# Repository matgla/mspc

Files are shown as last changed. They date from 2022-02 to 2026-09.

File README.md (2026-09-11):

# MSPC

Hardware for MSPC: a small modular computer built from a mainboard and extension cards that plug
into the MSPC bus. The mainboard runs [yasos](https://github.com/matgla/yasos.zig).

## Versions and branches

| branch | contents |
|---|---|
| `main` | the current hardware: the v2 boards (same as `mspc_v2`) |
| `mspc_v1` | the first generation, kept for reference |
| `mspc_v2` | the v2 boards as built |
| `mspc_v2.5` | the next revision, work in progress; `main` moves there when it is done and that point is tagged `mspcv2.5` |

## Repository layout

Every board is a KiCad project with its fabrication outputs next to it in `outputs/`.

| directory | board |
|---|---|
| `mainboard/` | Mainboard (project in `mainboard/mainboard/`). RP2350B (80-QFN), QSPI flash and PSRAM, microSD, HS8836A USB hub, TLV320DAC3203 audio DAC, 12 V input with BD9D321EFJ bucks, three MSPC bus sockets (2×10 and 2×15, 1.27 mm). 4 copper layers. |
| `gpu_vga_extension/` | VGA card: RP2350A (60-QFN), 2× W25Q32JV flash, AP2112K 3.3 V regulator, resistor-ladder RGB DAC and DB15 connector. 24 × 50 mm, 4 layers. |
| `gpu_dvi_card/` | DVI card: same core as the VGA card, with an HDMI-type receptacle carrying DVI. 24 × 50 mm, 4 layers. |
| `fpga_extension/` | FPGA card (project in `fpga_extension/fpga_extension/`): Lattice ECP5 LFE5UM-85F, W958D8NBYA HyperRAM, QSPI configuration flash, microSD, and an on-board RP2040 USB-C JTAG programmer. 47.5 × 50 mm, 6 layers. |
| `bus_adapter_20pin/` | Passive breakout from the 2×10 1.27 mm bus socket to two 1×10 2.54 mm headers. |
| `bus_adapter_30pin/` | Passive breakout from the 2×15 1.27 mm bus socket to two 1×15 2.54 mm headers. |
| `simulation/` | 2022 SPICE sandbox: KiCad/ngspice schematics (audio filter, power switch) and PySpice scripts. Not a board. |

## Working with the files

- The projects are in **KiCad 8** format. Newer KiCad versions upgrade them on the first save, and
  the result no longer opens in KiCad 8. Do such an upgrade as its own commit, with no design
  changes, so later diffs stay readable.
- Schematic PDFs (`outputs/schematic.pdf`) are tracked, so the schematics can be read without
  KiCad. Gerbers and drill files are not: plot them from the KiCad project when ordering a board.
  Per-machine files (backups, caches, `*.kicad_prl`, lock files, local history) are ignored too.

## Known issues

- Some outputs are older than the boards they sit next to: the mainboard stencil (from v1), the
  GPU cards' schematic PDFs and stencils (from before the VGA/DVI split), and the FPGA card's
  schematic PDF. Regenerate them before the next order.
- The silkscreen of the 20-pin bus adapter reads "2x15" (copied from the 30-pin adapter).
- The libraries are copied into each project and have diverged.

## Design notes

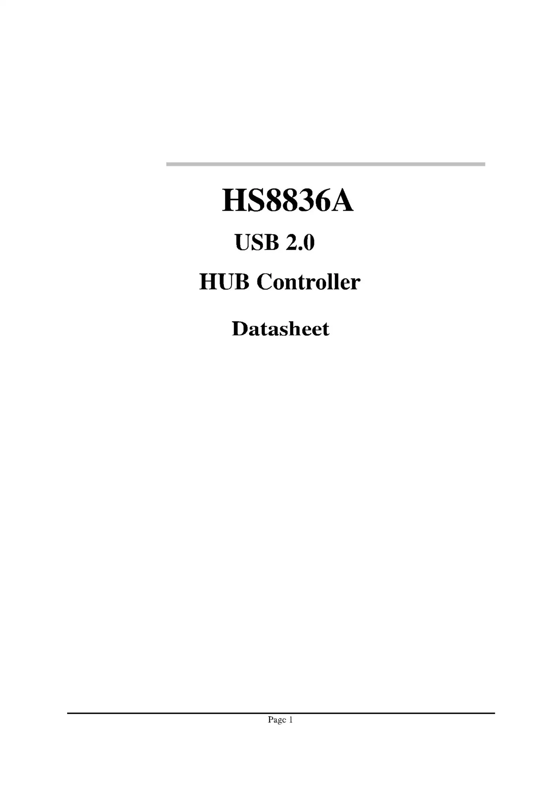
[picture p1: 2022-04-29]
mainboard/mainboard/docs/hs8836a/Had52ff619c5044d0bcb96a23b9133d81U.jpg_.webp

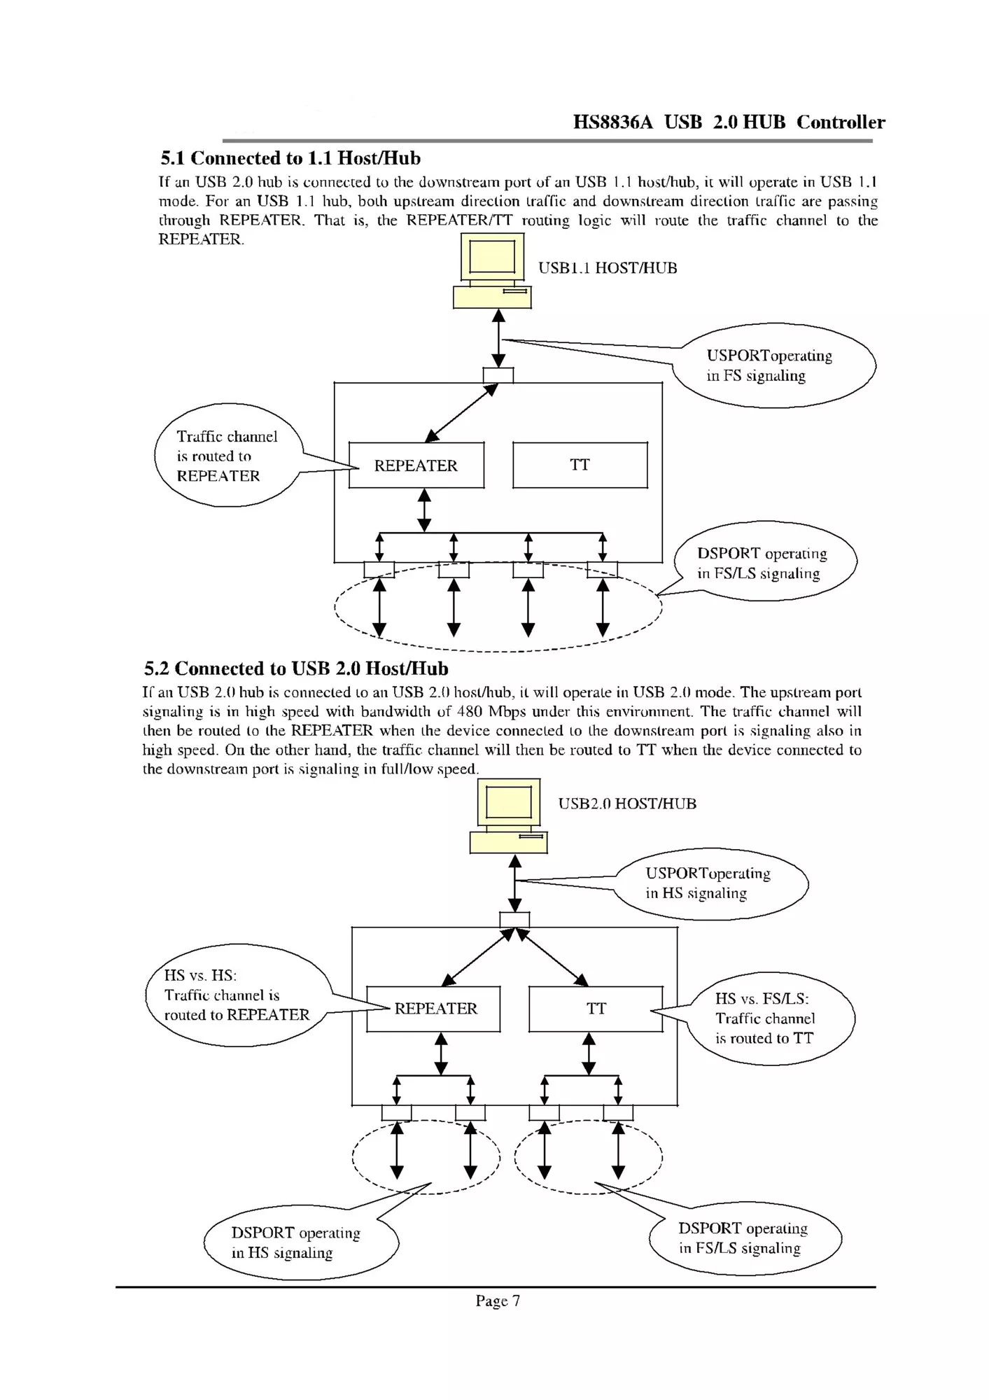
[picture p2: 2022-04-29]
mainboard/mainboard/docs/hs8836a/H961c6f75e87a4ca28475161b637013b4f.jpg_.webp

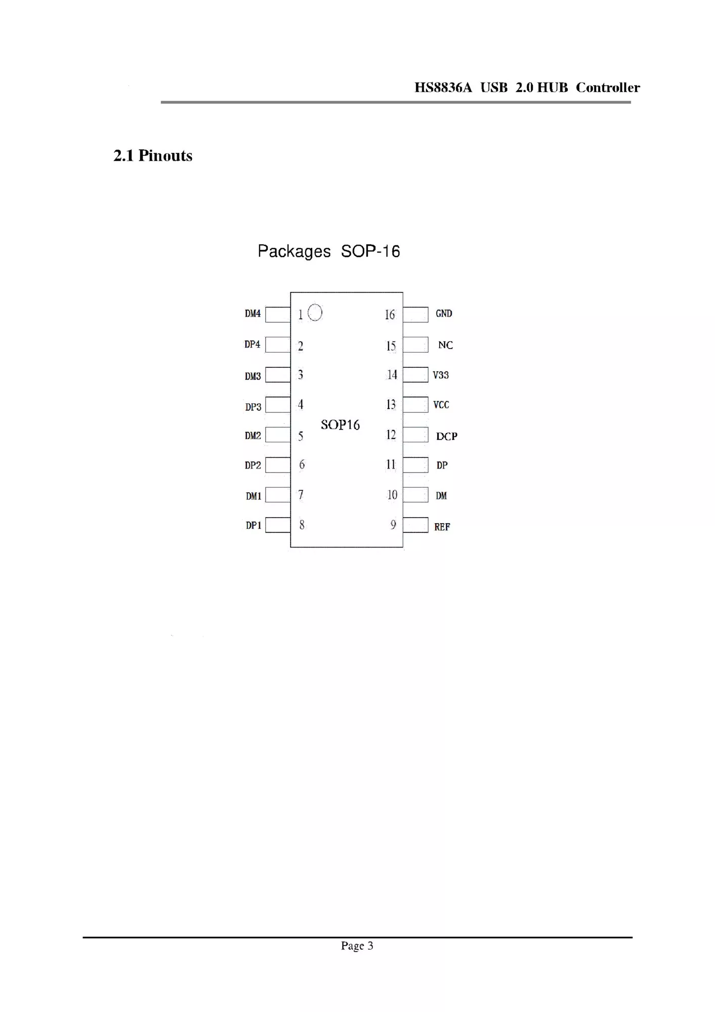
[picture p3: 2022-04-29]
mainboard/mainboard/docs/hs8836a/Hb40b045f20e34e7facae269df4be357fu.jpg_.webp

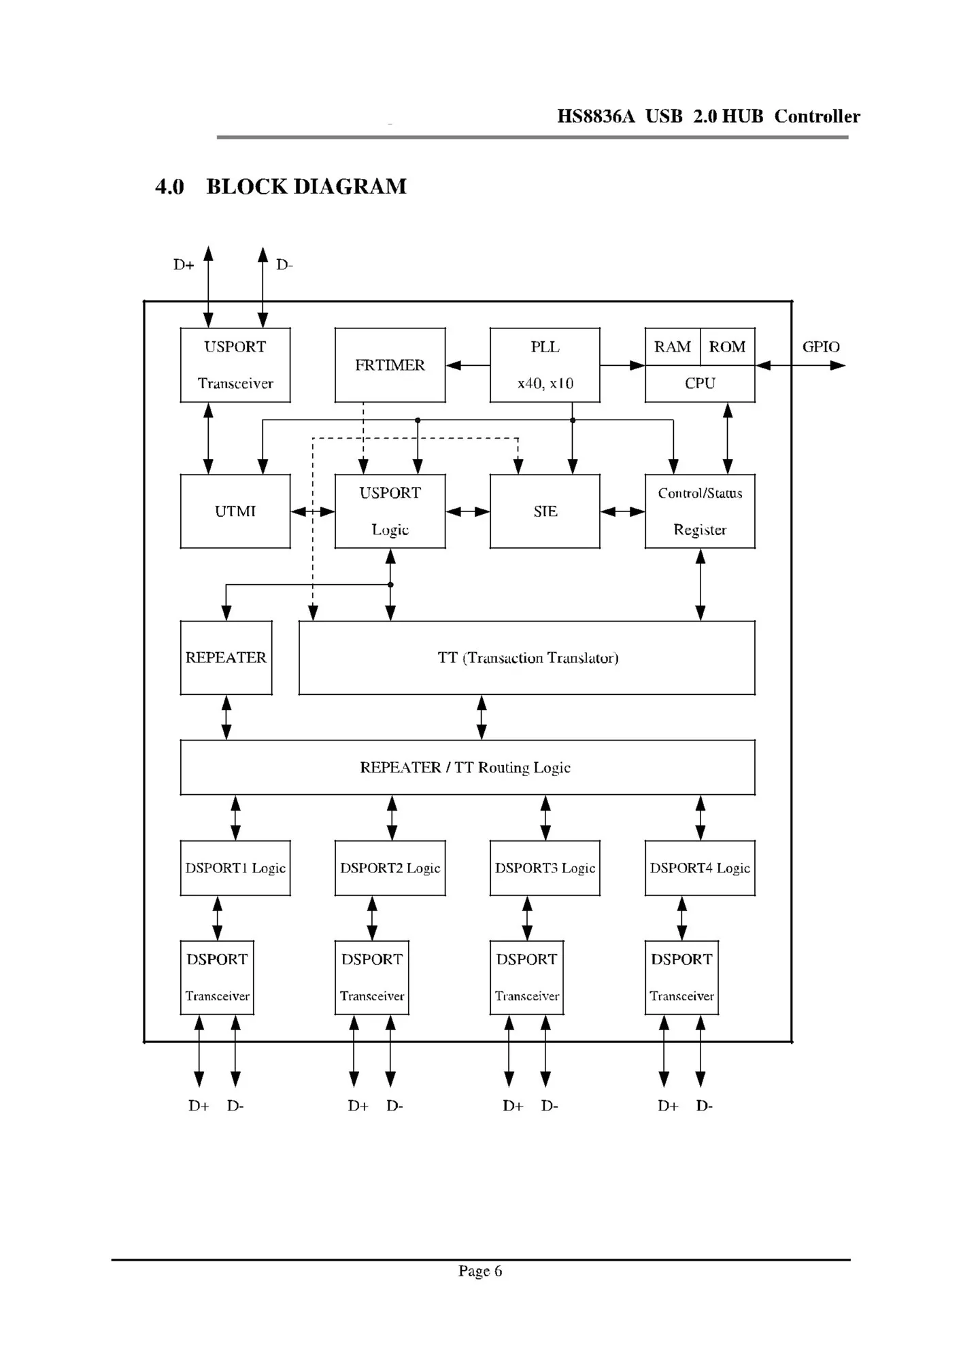
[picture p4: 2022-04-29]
mainboard/mainboard/docs/hs8836a/Hc16099ccc998455ca653669efb70748a5.jpg_.webp

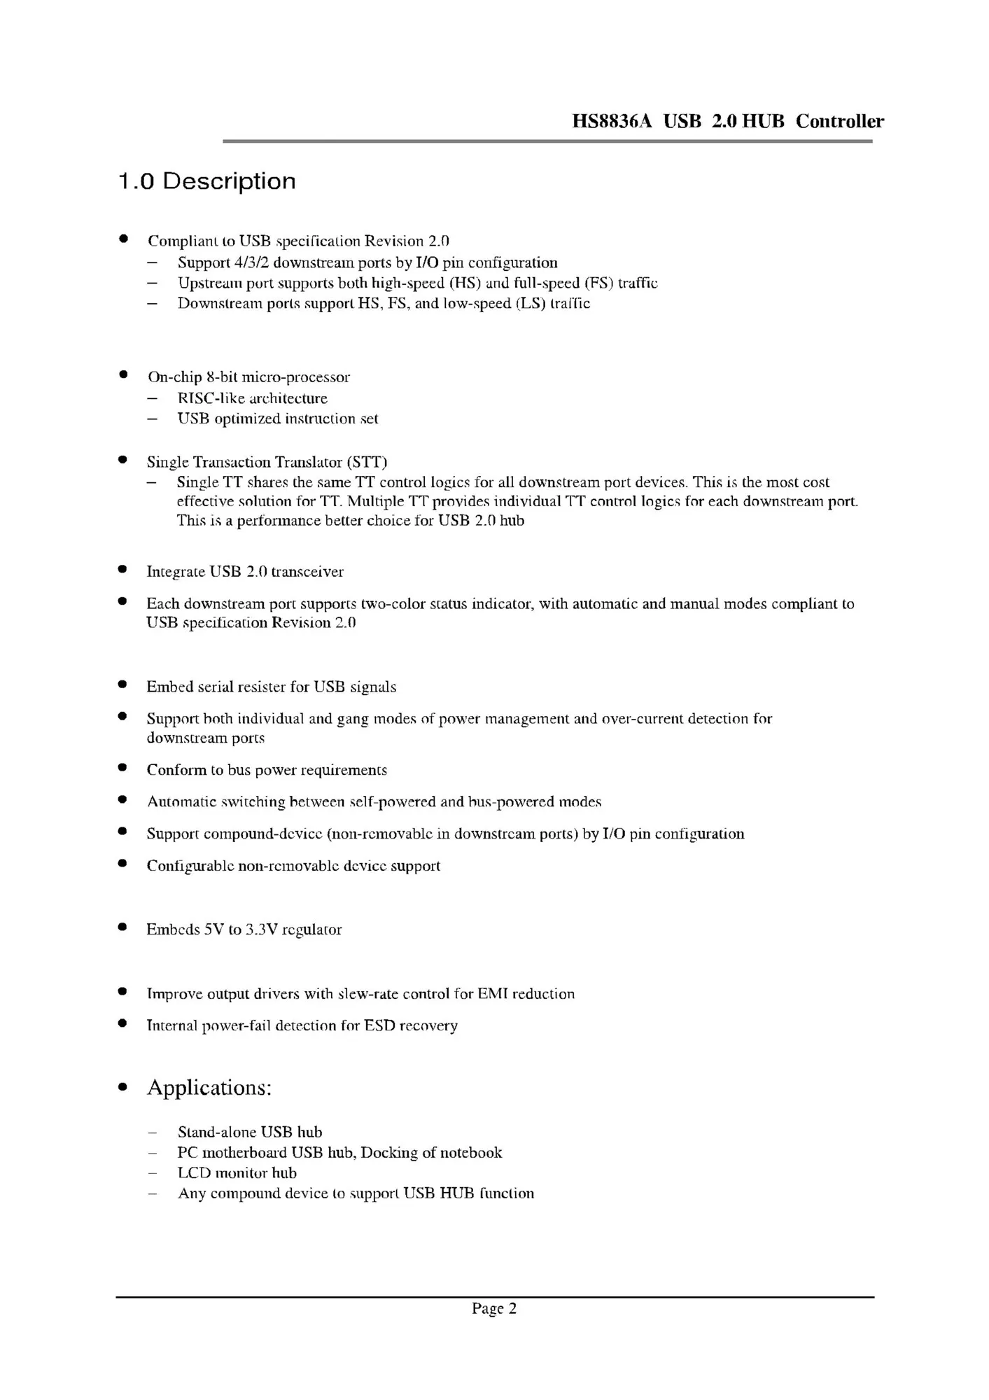
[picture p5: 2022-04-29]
mainboard/mainboard/docs/hs8836a/Hbae3ca12f1974fc99a928988f4e37874O.jpg_.webp

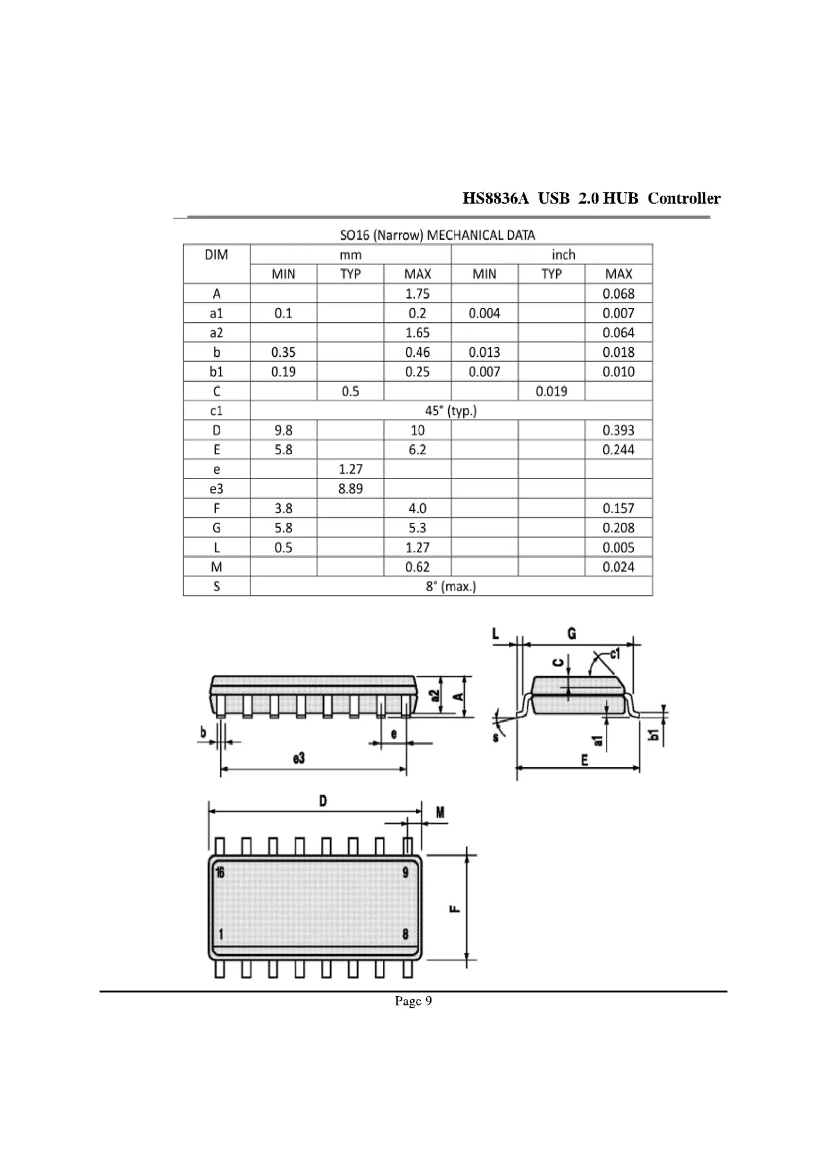
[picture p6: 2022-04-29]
mainboard/mainboard/docs/hs8836a/H5af7ee53966f407483fe4118c96aea51C.jpg_.webp

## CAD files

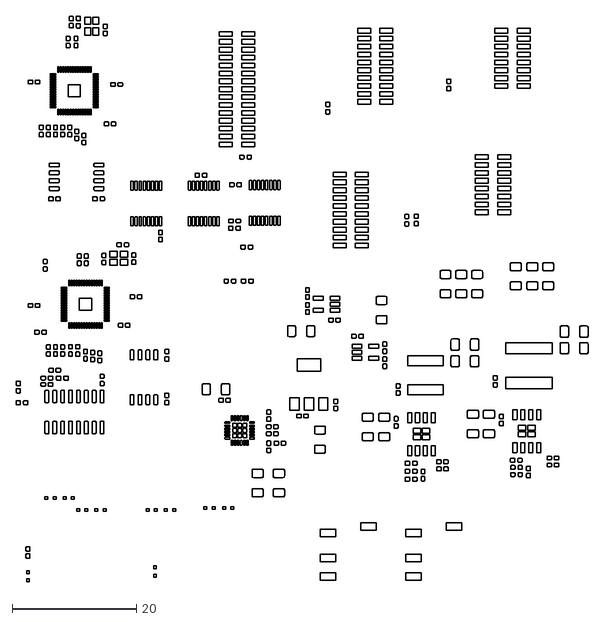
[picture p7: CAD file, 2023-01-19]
mainboard/mainboard/stencil/mainboard-PasteTop.dxf
92.0 x 91.0

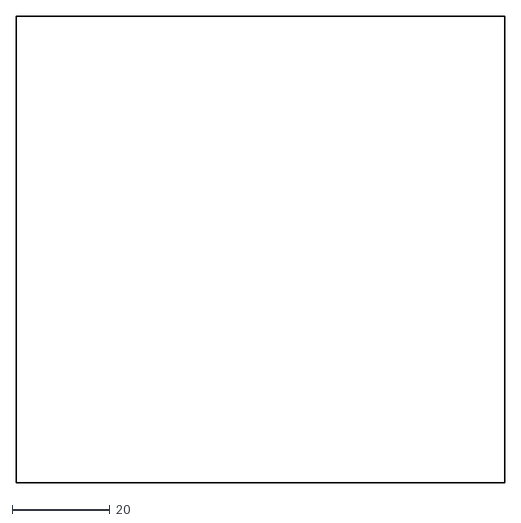
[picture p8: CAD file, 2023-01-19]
mainboard/mainboard/stencil/mainboard-EdgeCuts.dxf
99.9 x 95.3

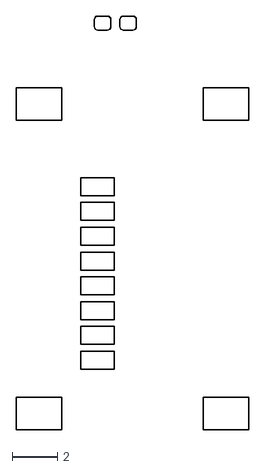
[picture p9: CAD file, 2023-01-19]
mainboard/mainboard/stencil/mainboard-PasteBottom.dxf
10.3 x 18.4

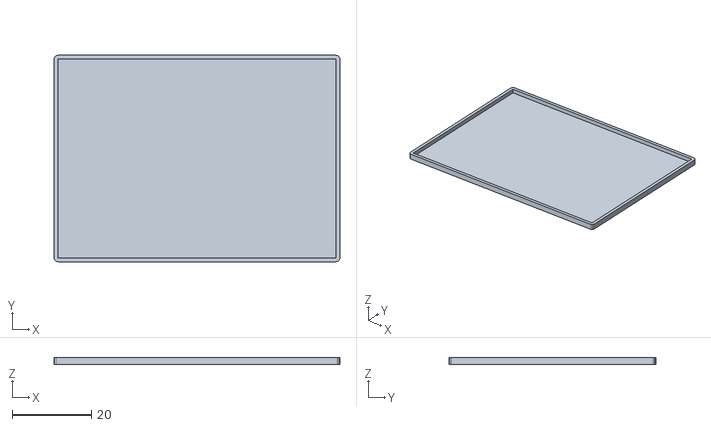
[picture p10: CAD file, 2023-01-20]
gpu_dvi_card/stencil/bottomStencil.stl
72.0 x 52.0 x 1.75

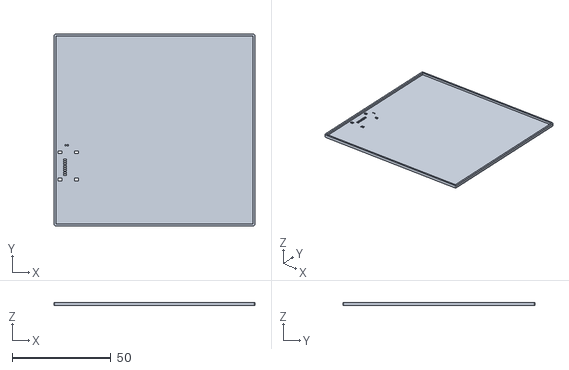
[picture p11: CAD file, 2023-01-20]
mainboard/mainboard/stencil/bottomStencil.stl
101.9 x 97.3 x 1.75

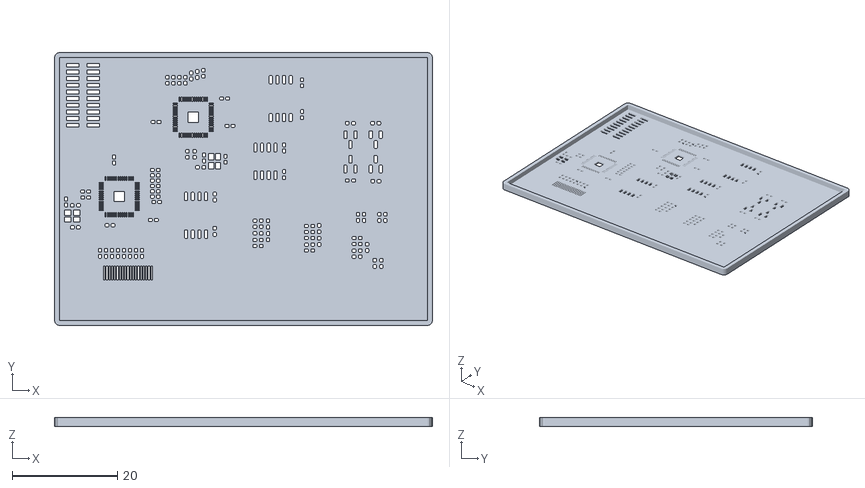
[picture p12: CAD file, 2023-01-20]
gpu_dvi_card/stencil/topStencil.stl
72.0 x 52.0 x 1.75

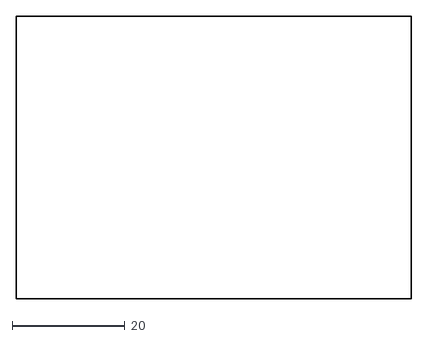
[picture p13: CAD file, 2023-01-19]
gpu_vga_extension/stencil/gpu_extension-EdgeCuts.dxf
70.0 x 50.0

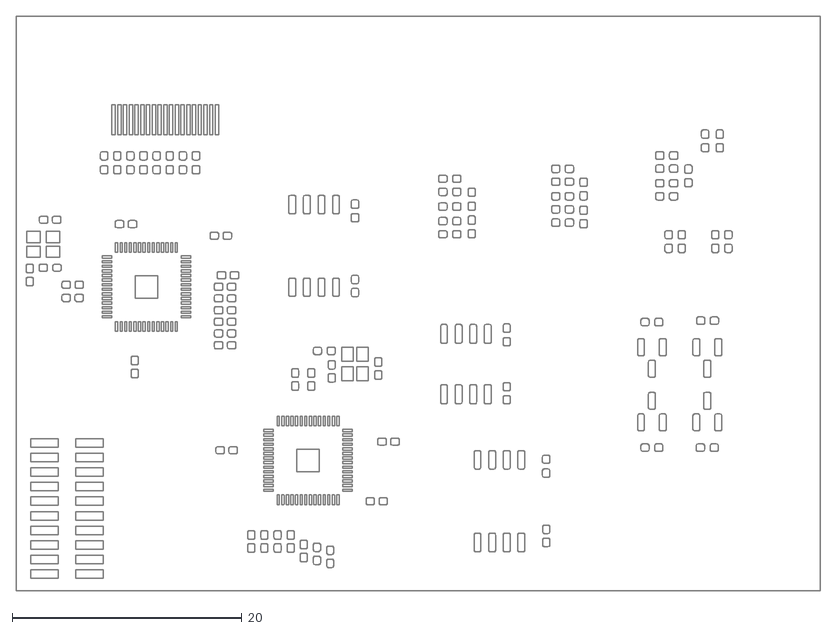
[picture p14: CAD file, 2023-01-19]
gpu_dvi_card/stencil/st2.dxf
70.0 x 50.0

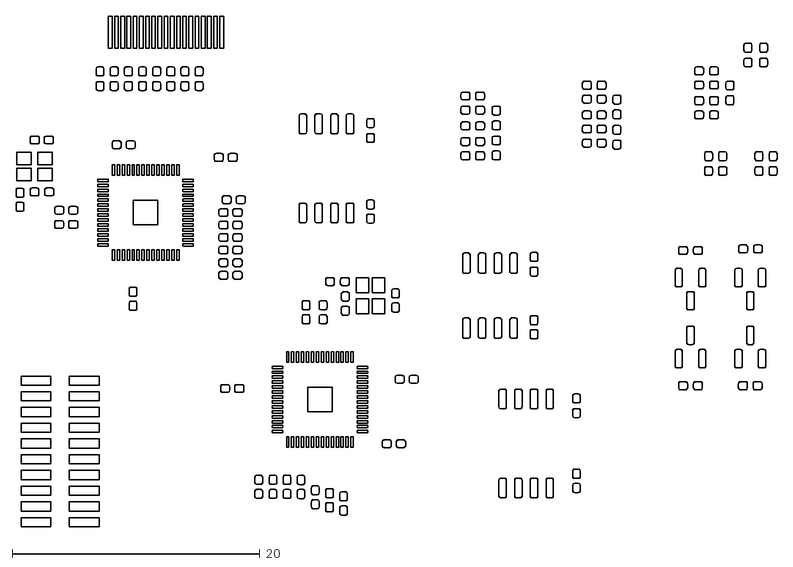
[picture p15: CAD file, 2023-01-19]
gpu_vga_extension/stencil/gpu_extension-PasteTop.dxf
61.5 x 41.2

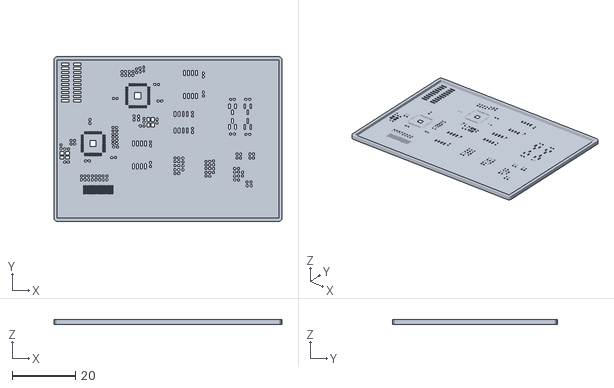
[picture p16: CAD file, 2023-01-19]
mainboard/mainboard/stencil/topStencil.stl
72.0 x 52.0 x 1.45

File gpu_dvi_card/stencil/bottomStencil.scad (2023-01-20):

// Generated by SolidPython 1.1.3 on 2023-01-20 13:13:41
$fa = 0.4; $fs = 0.4;


rotate(a = 0, v = [1, 0, 0]) {
	difference() {
		scale(v = [1, 1, 1]) {
			difference() {
				linear_extrude(height = 1.7500000000) {
					offset(r = 1.0000000000) {
						import(file = "/home/mateusz/repos/mspc/gpu_extension/stencil/gpu_extension-EdgeCuts.dxf", origin = [0, 0]);
					}
				}
				translate(v = [0, 0, 0.4500000000]) {
					linear_extrude(height = 1.7500000000) {
						translate(v = [0, 0, 0]) {
							import(file = "/home/mateusz/repos/mspc/gpu_extension/stencil/gpu_extension-EdgeCuts.dxf", origin = [0, 0]);
						}
					}
				}
			}
		}
		linear_extrude(center = true, height = 1.8000000000) {
			translate(v = [0, 0, 0]) {
				import(file = "/home/mateusz/repos/mspc/gpu_extension/stencil/gpu_extension-PasteBottom.dxf", origin = [0, 0]);
			}
		}
	}
}
/***********************************************
*********      SolidPython code:      **********
************************************************
 
from pcbnewTransition import pcbnew
from pcbnew import VECTOR2I
import numpy as np
import json
from collections import OrderedDict
from kikit.common import *
from kikit.defs import *
from kikit.substrate import Substrate, extractRings, toShapely, linestringToKicad
from kikit.export import gerberImpl, pasteDxfExport
from kikit.export import exportSettingsJlcpcb
import solid
import solid.utils
import subprocess
import shutil
from kikit.common import removeComponents, parseReferences

from shapely.geometry import Point


OUTER_BORDER = fromMm(7.5)
INNER_BORDER = fromMm(5)
MOUNTING_HOLES_COUNT = 3
MOUNTING_HOLE_R = fromMm(1)
HOLE_SPACING = fromMm(20)

def addBottomCounterpart(board, item):
    item = item.Duplicate()
    item.SetLayer(Layer.B_Paste)
    board.Add(item)

def addRoundedCorner(board, center, start, end, thickness):
    corner = pcbnew.PCB_SHAPE()
    corner.SetShape(STROKE_T.S_ARC)
    corner.SetCenter(VECTOR2I(center[0], center[1]))
    corner.SetStart(VECTOR2I(start[0], start[1]))

    if np.cross(start - center, end - center) > 0:
        corner.SetArcAngleAndEnd(fromDegrees(90), True)
    else:
        corner.SetArcAngleAndEnd(fromDegrees(-90), True)
    corner.SetWidth(thickness)
    corner.SetLayer(Layer.F_Paste)
    board.Add(corner)
    addBottomCounterpart(board, corner)

def addLine(board, start, end, thickness):
    line = pcbnew.PCB_SHAPE()
    line.SetShape(STROKE_T.S_SEGMENT)
    line.SetStart(VECTOR2I(start[0], start[1]))
    line.SetEnd(VECTOR2I(end[0], end[1]))
    line.SetWidth(thickness)
    line.SetLayer(Layer.F_Paste)
    board.Add(line)
    addBottomCounterpart(board, line)

def addBite(board, origin, direction, normal, thickness):
    """
    Adds a bite to the stencil, direction points to the bridge, normal points
    inside the stencil
    """
    direction = normalize(direction) * thickness
    normal = normalize(normal) * thickness
    center = VECTOR2I(origin[0], origin[1]) + VECTOR2I(normal[0], normal[1])
    start = origin
    end = center + VECTOR2I(direction[0], direction[1])
    # addLine(board, end, end + normal / 2, thickness)
    addRoundedCorner(board, center, start, end, thickness)

def numberOfCuts(length, bridgeWidth, bridgeSpacing):
    """
    Return number of bridges which fit inside the length and cut length
    """
    count = int(np.floor((length + bridgeWidth) / (bridgeWidth + bridgeSpacing)))
    cutLength = (length - (count - 1) * bridgeWidth) / count
    return count, cutLength

def addFrame(board, rect, bridgeWidth, bridgeSpacing, clearance):
    """
    Add rectangular frame to the board
    """
    R=fromMm(1)

    corners = [
        (tl(rect), VECTOR2I(R, 0), VECTOR2I(0, R)), # TL
        (tr(rect), VECTOR2I(0, R), VECTOR2I(-R, 0)), # TR
        (br(rect), VECTOR2I(-R, 0), VECTOR2I(0, -R)), # BR
        (bl(rect), VECTOR2I(0, -R), VECTOR2I(R, 0)) # BL
    ]
    for c, sOffset, eOffset in corners:
        addRoundedCorner(board, c + sOffset + eOffset, c + sOffset, c + eOffset, clearance)

    count, cutLength = numberOfCuts(rect.GetWidth() - 2 * R, bridgeWidth, bridgeSpacing)
    for i in range(count):
        start = rect.GetX() + R + i * bridgeWidth + i * cutLength
        end = start + cutLength

        y1, y2 = rect.GetY(), rect.GetY() + rect.GetHeight()
        addLine(board, VECTOR2I(start, y1), VECTOR2I(end, y1), clearance)
        if i != 0:
            addBite(board, VECTOR2I(start, y1), VECTOR2I(-1, 0), VECTOR2I(0, 1), clearance)
        if i != count - 1:
            addBite(board, VECTOR2I(end, y1), VECTOR2I(1, 0), VECTOR2I(0, 1), clearance)
        addLine(board, VECTOR2I(start, y2), VECTOR2I(end, y2), clearance)
        if i != 0:
            addBite(board, VECTOR2I(start, y2), VECTOR2I(-1, 0), VECTOR2I(0, -1), clearance)
        if i != count - 1:
            addBite(board, VECTOR2I(end, y2), VECTOR2I(1, 0), VECTOR2I(0, -1), clearance)

    count, cutLength = numberOfCuts(rect.GetHeight() - 2 * R, bridgeWidth, bridgeSpacing)
    for i in range(count):
        start = rect.GetY() + R + i * bridgeWidth + i * cutLength
        end = start + cutLength

        x1, x2 = rect.GetX(), rect.GetX() + rect.GetWidth()
        addLine(board, VECTOR2I(x1, start), VECTOR2I(x1, end), clearance)
        if i != 0:
            addBite(board, VECTOR2I(x1, start), VECTOR2I(0, -1), VECTOR2I(1, 0), clearance)
        if i != count - 1:
            addBite(board, VECTOR2I(x1, end), VECTOR2I(0, 1), VECTOR2I(1, 0), clearance)
        addLine(board, VECTOR2I(x2, start), VECTOR2I(x2, end), clearance)
        if i != 0:
            addBite(board, VECTOR2I(x2, start), VECTOR2I(0, -1), VECTOR2I(-1, 0), clearance)
        if i != count - 1:
            addBite(board, VECTOR2I(x2, end), VECTOR2I(0, 1), VECTOR2I(-1, 0), clearance)

def addHole(board, position, radius):
    circle = pcbnew.PCB_SHAPE()
    circle.SetShape(STROKE_T.S_CIRCLE)
    circle.SetCenter(VECTOR2I(position[0], position[1]))
    # Set 3'oclock point of the circle to set radius
    circle.SetEnd(VECTOR2I(position[0], position[1]) + VECTOR2I(radius/2, 0))

    circle.SetWidth(radius)
    circle.SetLayer(Layer.F_Paste)
    board.Add(circle)
    addBottomCounterpart(board, circle)

def addJigFrame(board, jigFrameSize, bridgeWidth=fromMm(2),
                bridgeSpacing=fromMm(10), clearance=fromMm(0.5)):
    """
    Given a Pcbnew board finds the board outline and creates a stencil for
    KiKit's stencil jig.

    Mainly, adds mounting holes and mouse bites to define the panel outline.

    jigFrameSize is a tuple (width, height).
    """
    bBox = findBoardBoundingBox(board)
    frameSize = rectByCenter(rectCenter(bBox),
        jigFrameSize[0] + 2 * (OUTER_BORDER + INNER_BORDER),
        jigFrameSize[1] + 2 * (OUTER_BORDER + INNER_BORDER))
    cutSize = rectByCenter(rectCenter(bBox),
        jigFrameSize[0] + 2 * (OUTER_BORDER + INNER_BORDER) - fromMm(1),
        jigFrameSize[1] + 2 * (OUTER_BORDER + INNER_BORDER) - fromMm(1))
    addFrame(board, cutSize, bridgeWidth, bridgeSpacing, clearance)

    for i in range(MOUNTING_HOLES_COUNT):
        x = frameSize.GetX() + OUTER_BORDER / 2 + (i + 1) * (frameSize.GetWidth() - OUTER_BORDER) / (MOUNTING_HOLES_COUNT + 1)
        addHole(board, VECTOR2I(x, OUTER_BORDER / 2 + frameSize.GetY()), MOUNTING_HOLE_R)
        addHole(board, VECTOR2I(x, - OUTER_BORDER / 2 +frameSize.GetY() + frameSize.GetHeight()), MOUNTING_HOLE_R)
    for i in range(MOUNTING_HOLES_COUNT):
        y = frameSize.GetY() + OUTER_BORDER / 2 + (i + 1) * (frameSize.GetHeight() - OUTER_BORDER) / (MOUNTING_HOLES_COUNT + 1)
        addHole(board, VECTOR2I(OUTER_BORDER / 2 + frameSize.GetX(), y), MOUNTING_HOLE_R)
        addHole(board, VECTOR2I(- OUTER_BORDER / 2 +frameSize.GetX() + frameSize.GetWidth(), y), MOUNTING_HOLE_R)

    PIN_TOLERANCE = fromMm(0.05)
    addHole(board, tl(frameSize) + VECTOR2I(OUTER_BORDER / 2, OUTER_BORDER / 2), MOUNTING_HOLE_R + PIN_TOLERANCE)
    addHole(board, tr(frameSize) + VECTOR2I(-OUTER_BORDER / 2, OUTER_BORDER / 2), MOUNTING_HOLE_R + PIN_TOLERANCE)
    addHole(board, br(frameSize) + VECTOR2I(-OUTER_BORDER / 2, -OUTER_BORDER / 2), MOUNTING_HOLE_R + PIN_TOLERANCE)
    addHole(board, bl(frameSize) + VECTOR2I(OUTER_BORDER / 2, -OUTER_BORDER / 2), MOUNTING_HOLE_R + PIN_TOLERANCE)

def jigMountingHoles(jigFrameSize, origin=VECTOR2I(0, 0)):
    """ Get list of all mounting holes in a jig of given size """
    w, h = jigFrameSize
    holes = [
        VECTOR2I(0, (w + INNER_BORDER) / 2),
        VECTOR2I(0, -(w + INNER_BORDER) / 2),
        VECTOR2I((h + INNER_BORDER) / 2, 0),
        VECTOR2I(-(h + INNER_BORDER) / 2, 0),
    ]
    return [x + origin for x in holes]

def createOuterPolygon(board, jigFrameSize, outerBorder):
    bBox = findBoardBoundingBox(board)
    centerpoint = rectCenter(bBox)
    holes = jigMountingHoles(jigFrameSize, centerpoint)
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

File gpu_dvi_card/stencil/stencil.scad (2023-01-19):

difference() {
    cube([70, 50, .3]);
    translate([-1.5, -3, 0]) minkowski() {
        linear_extrude(.2) import("st2.dxf");
        cube(.1);
    }
}

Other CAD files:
gpu_dvi_card/stencil/gpu_extension-PasteBottom.dxf
gpu_vga_extension/stencil/gpu_extension-PasteBottom.dxf
gpu_dvi_card/stencil/topStencil.scad
gpu_vga_extension/stencil/topStencil.scad
mainboard/mainboard/stencil/bottomStencil.scad
mainboard/mainboard/stencil/topStencil.scad

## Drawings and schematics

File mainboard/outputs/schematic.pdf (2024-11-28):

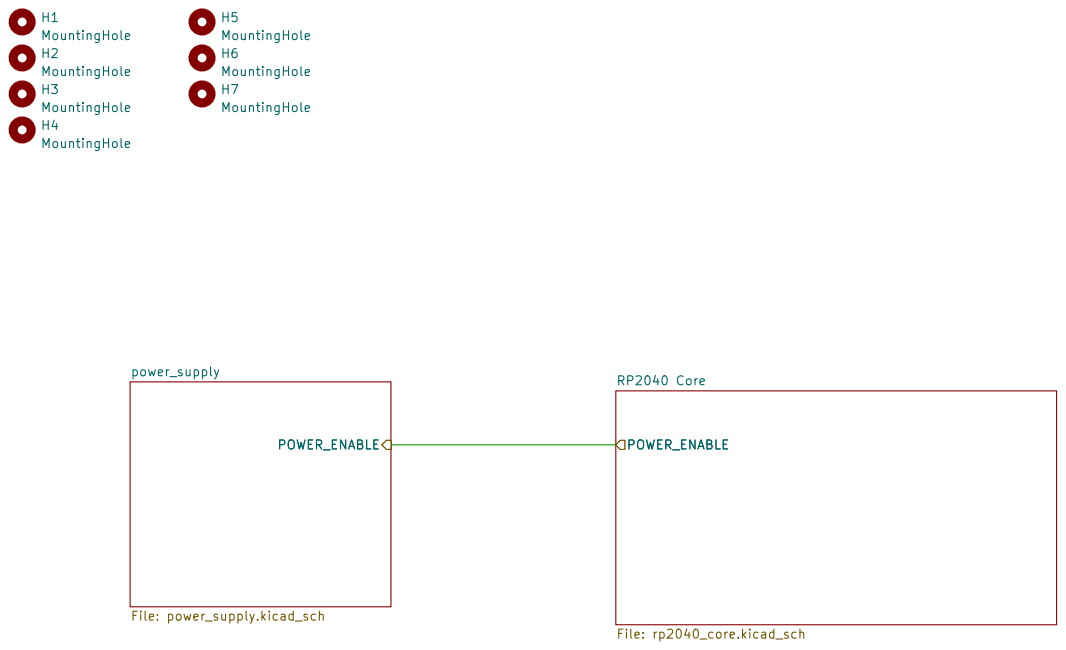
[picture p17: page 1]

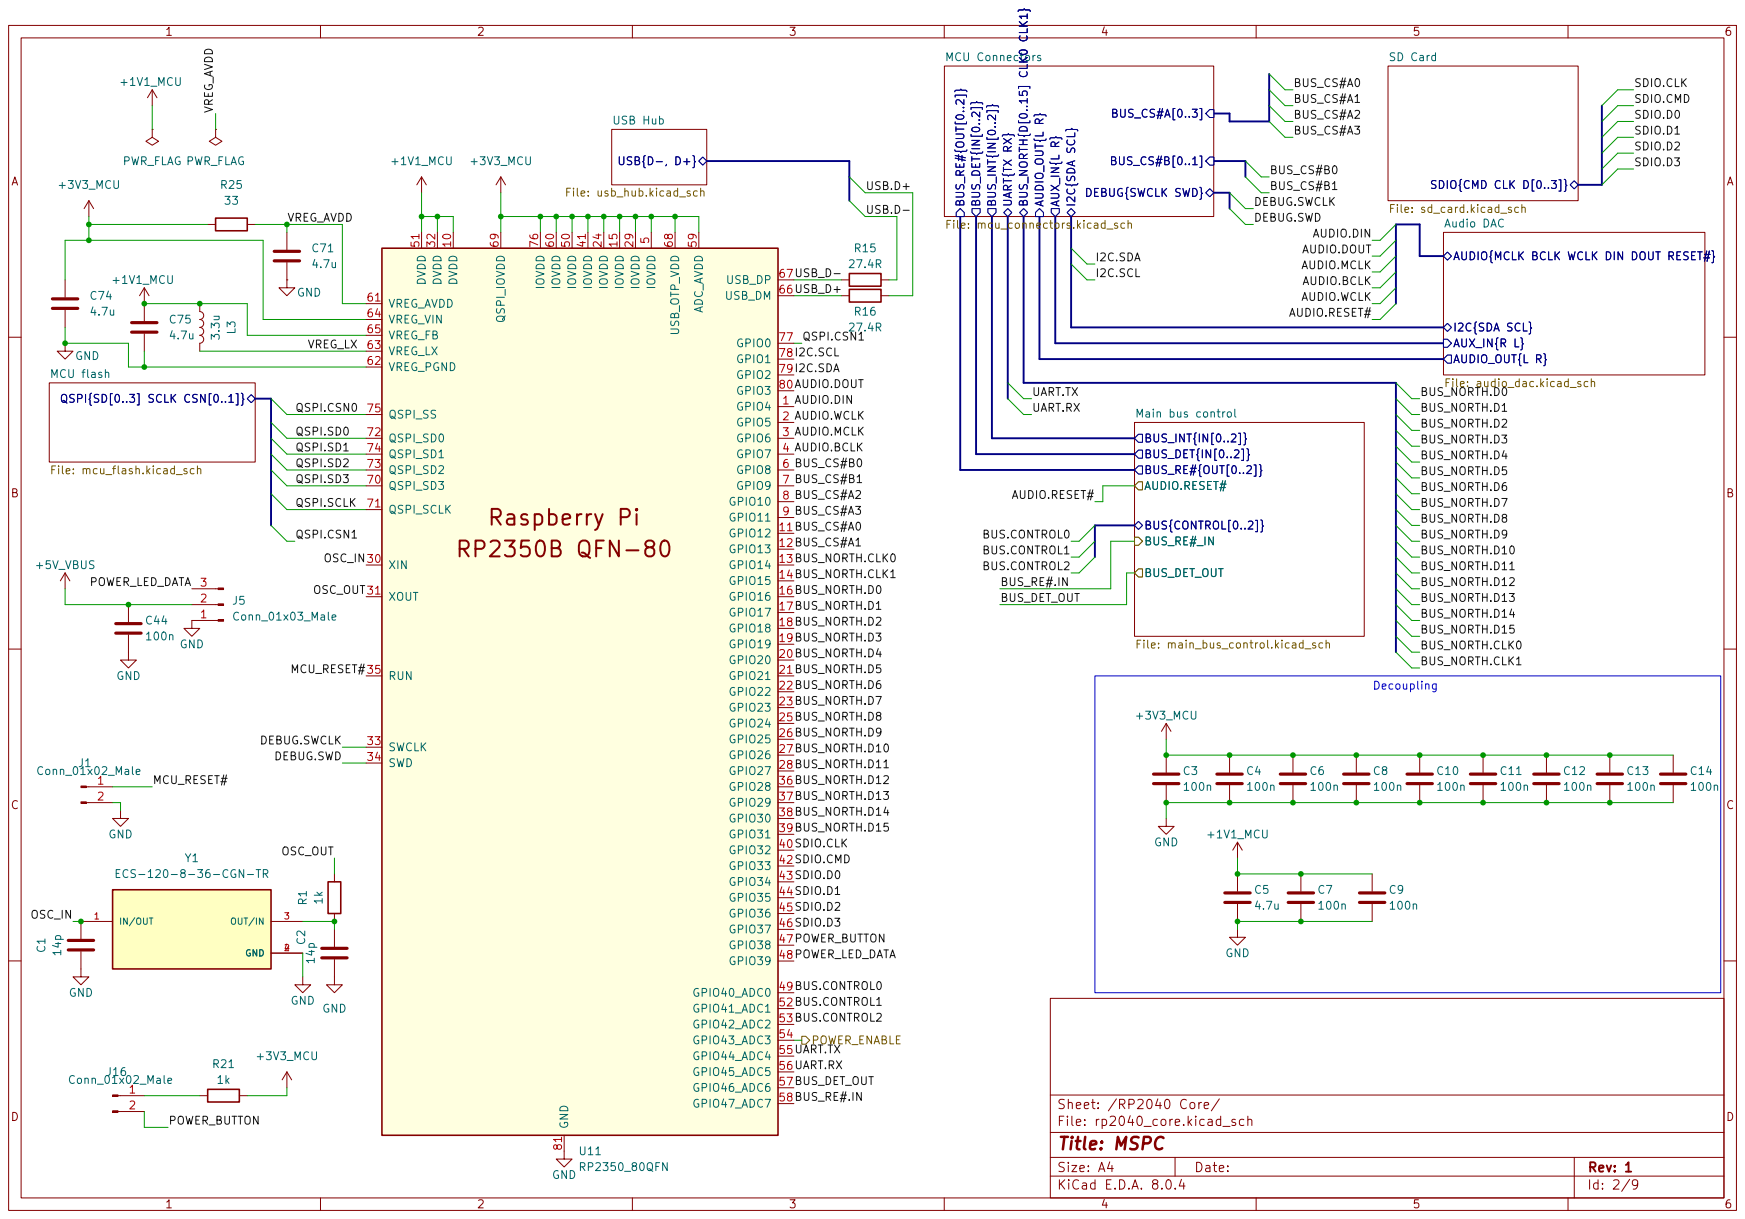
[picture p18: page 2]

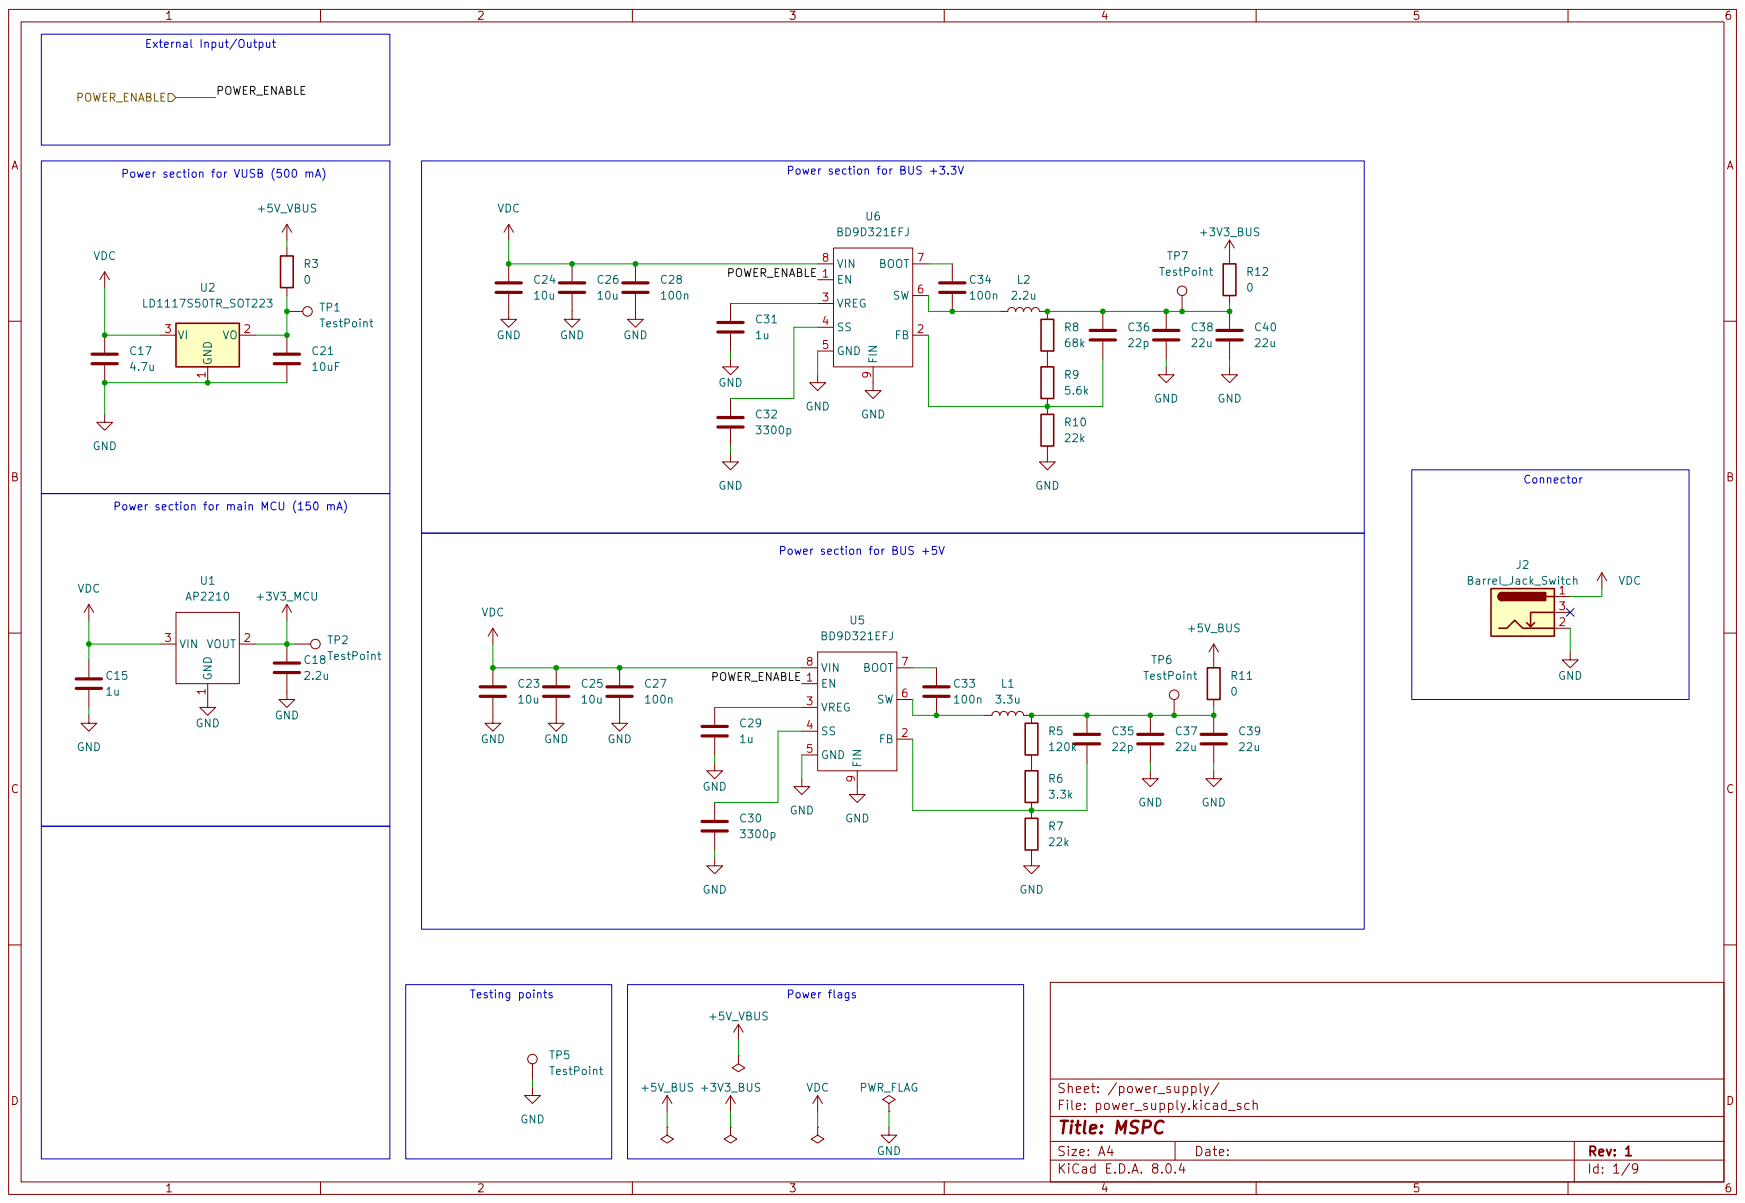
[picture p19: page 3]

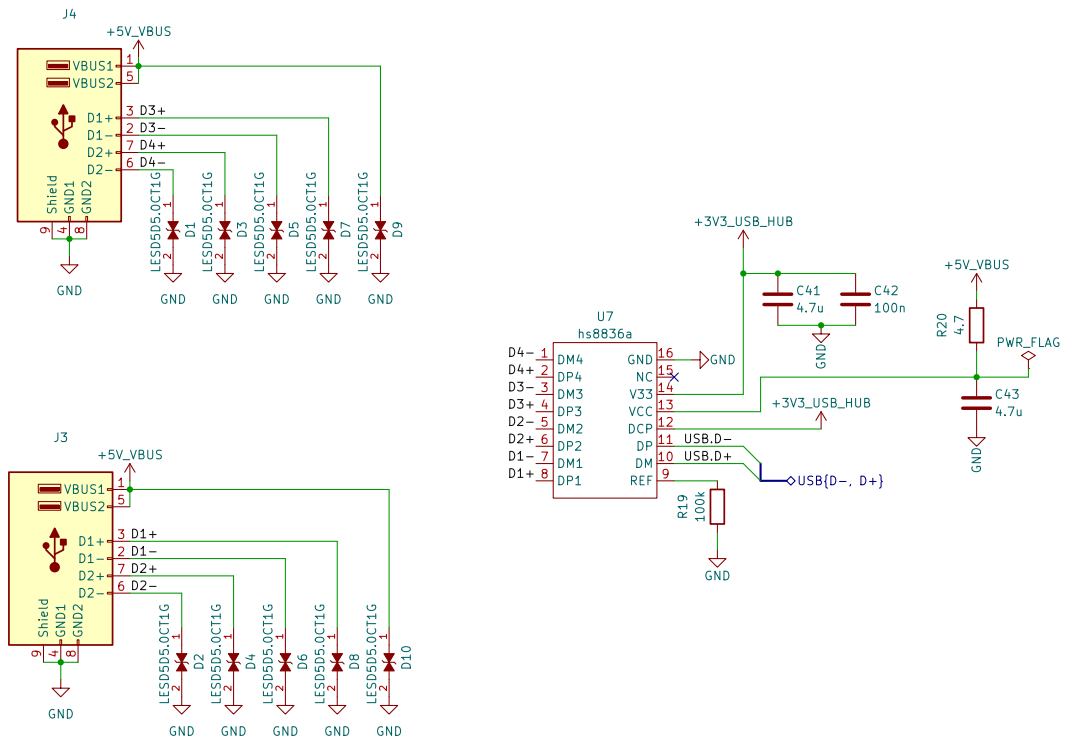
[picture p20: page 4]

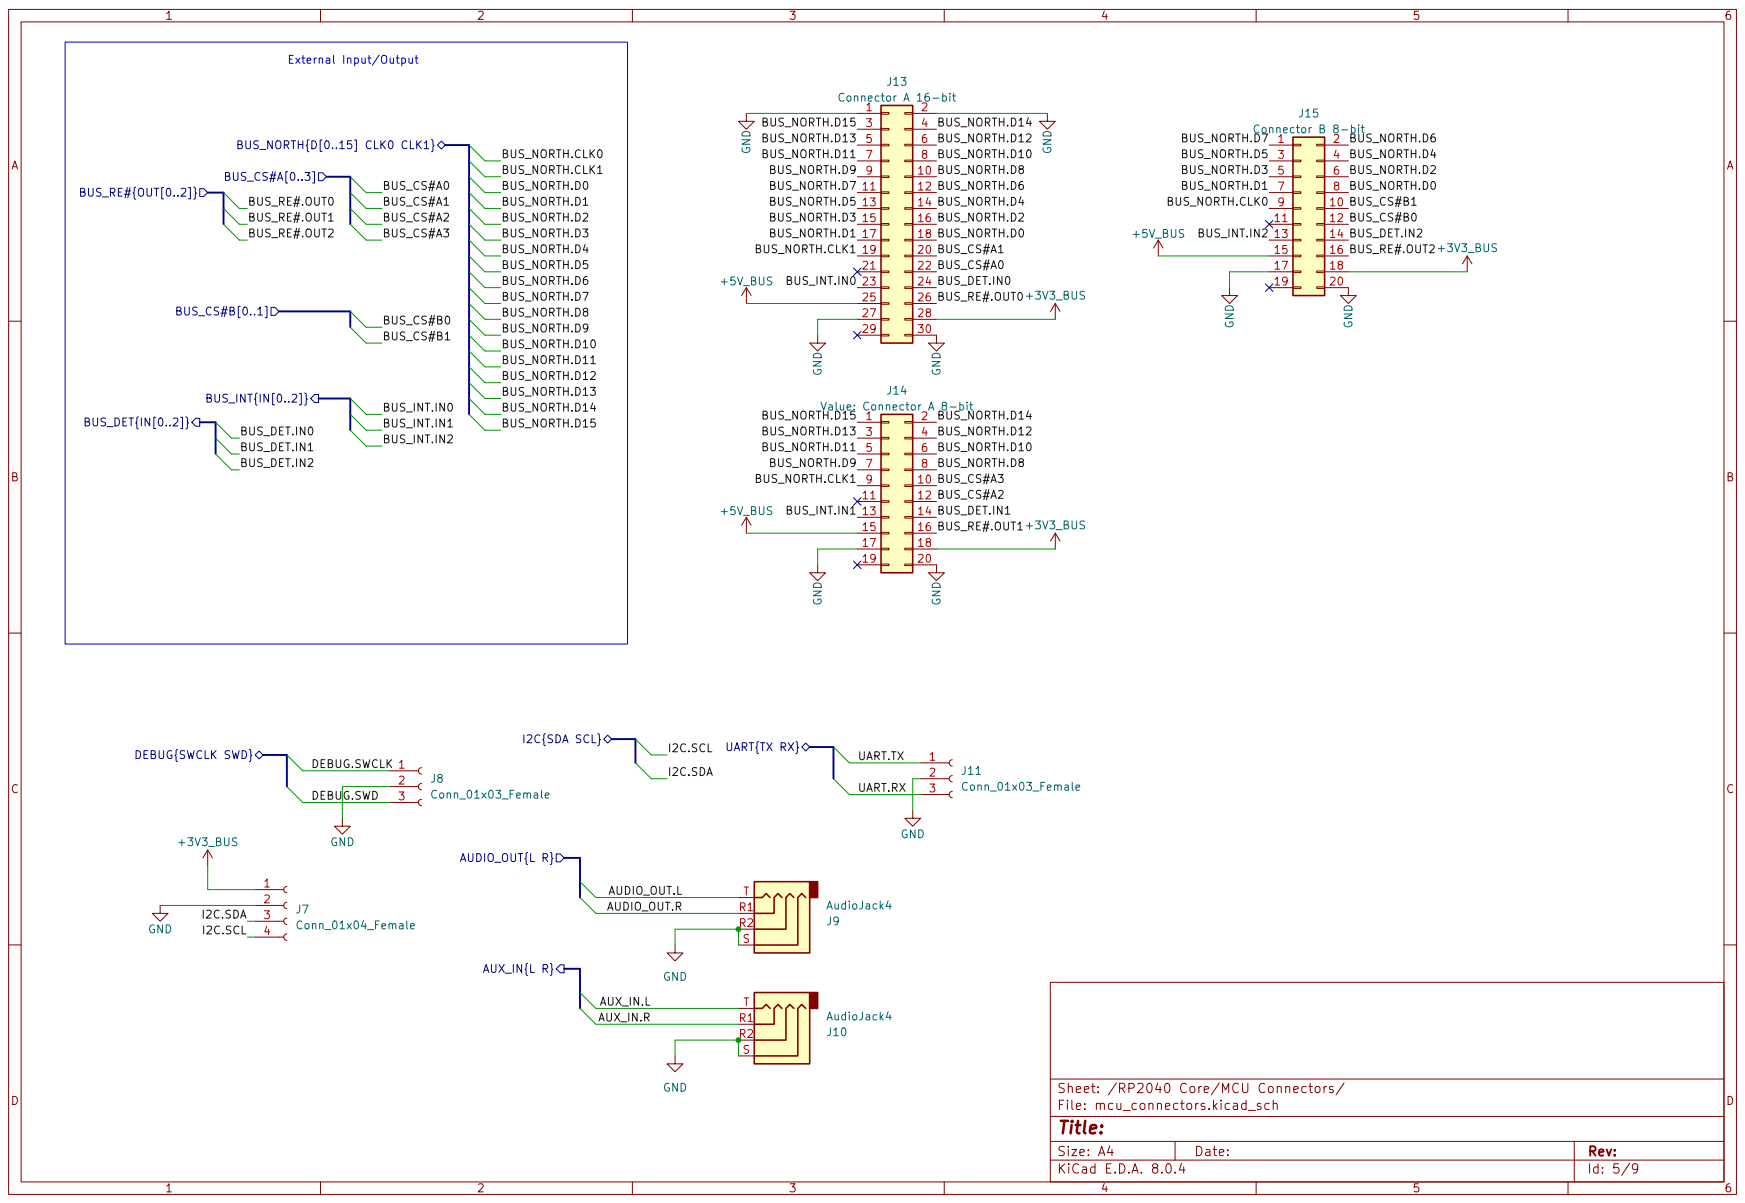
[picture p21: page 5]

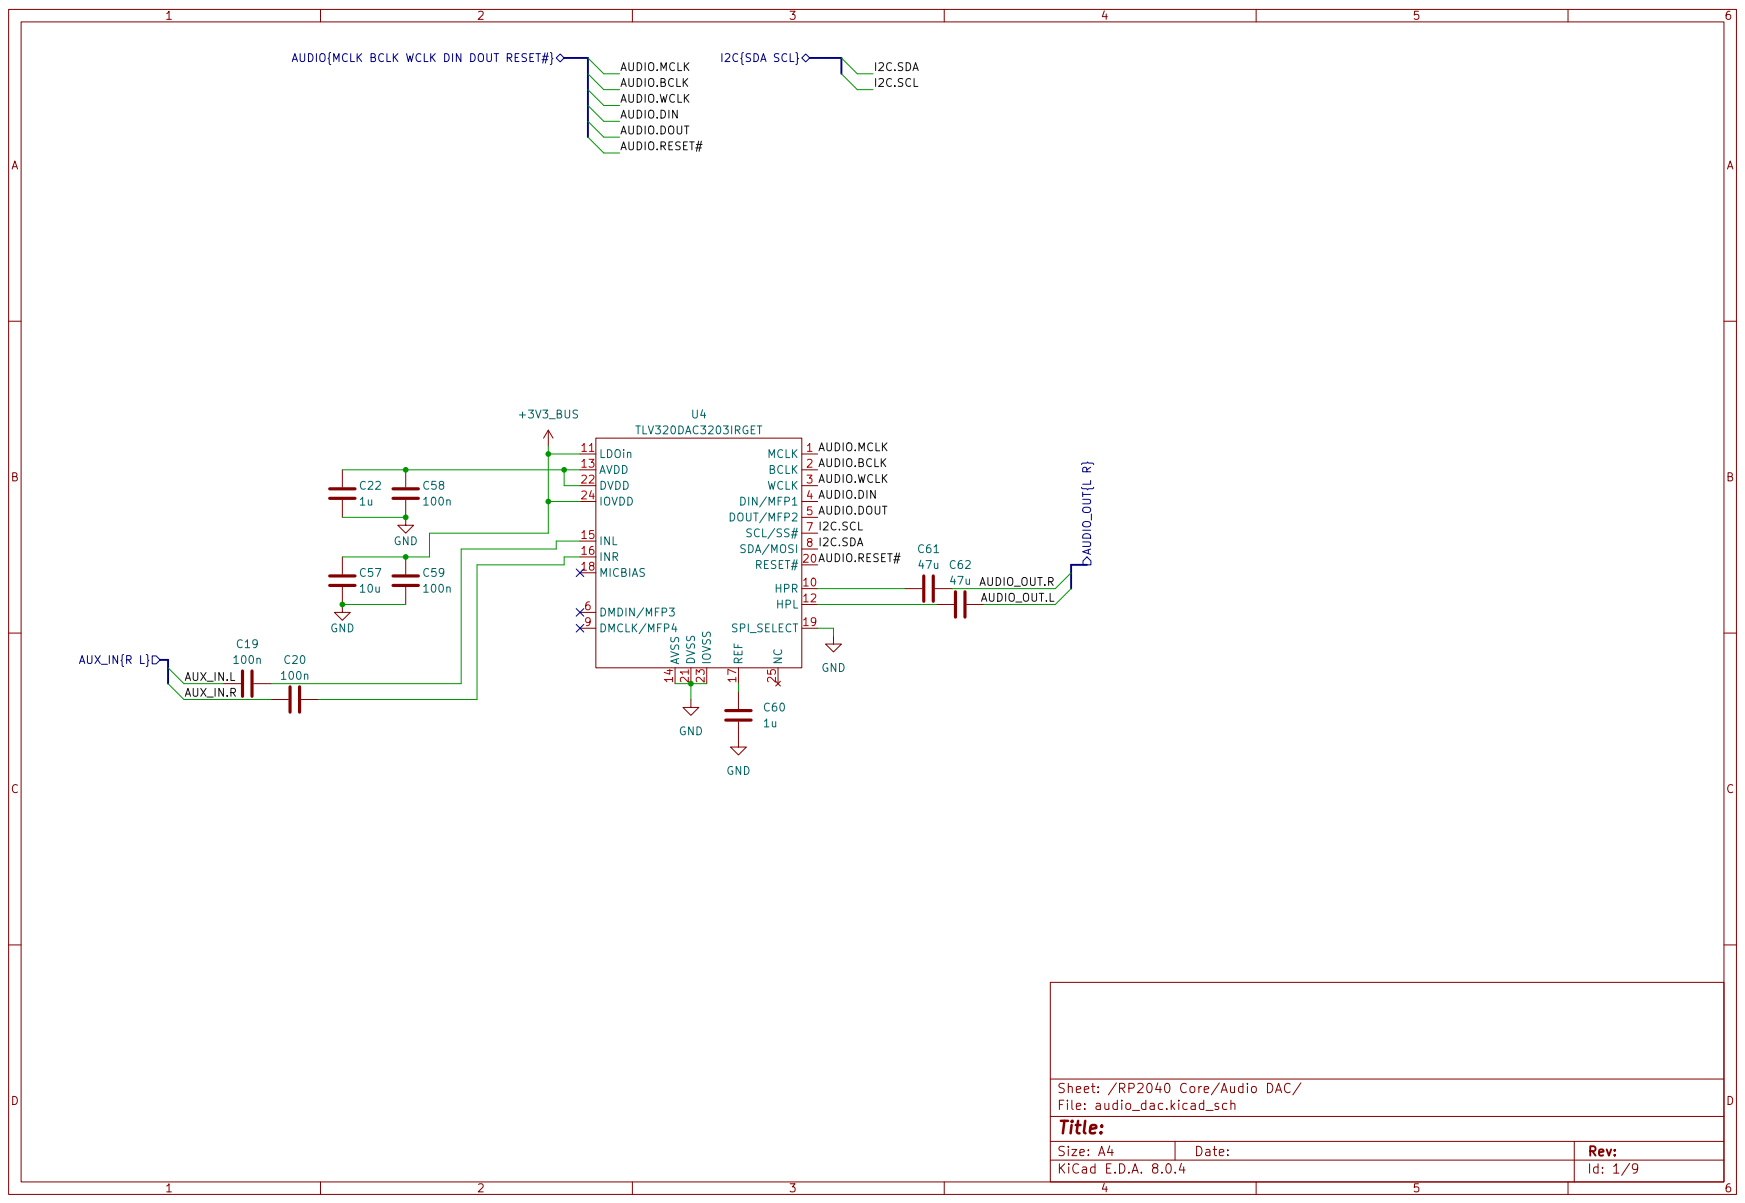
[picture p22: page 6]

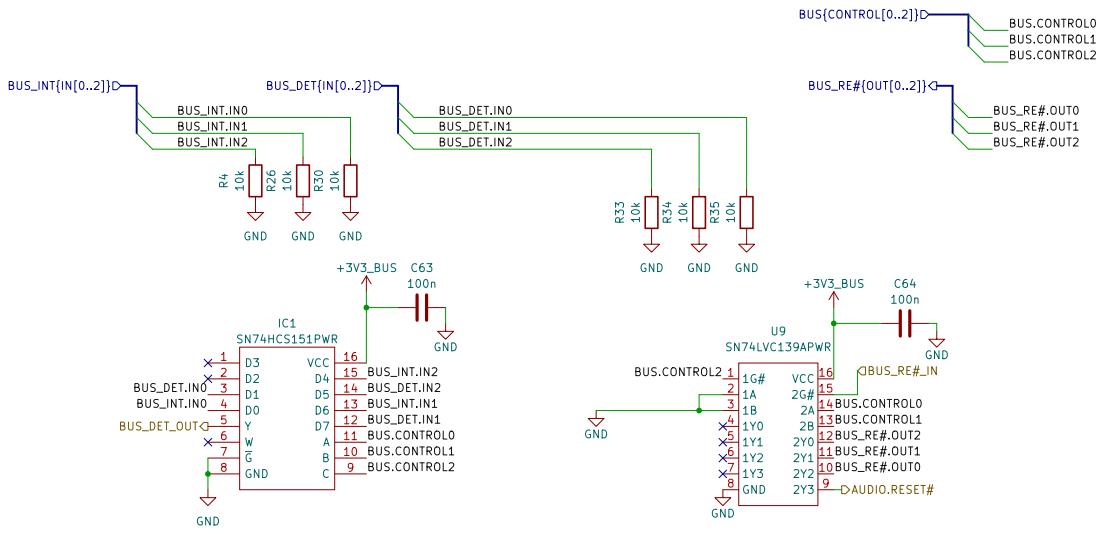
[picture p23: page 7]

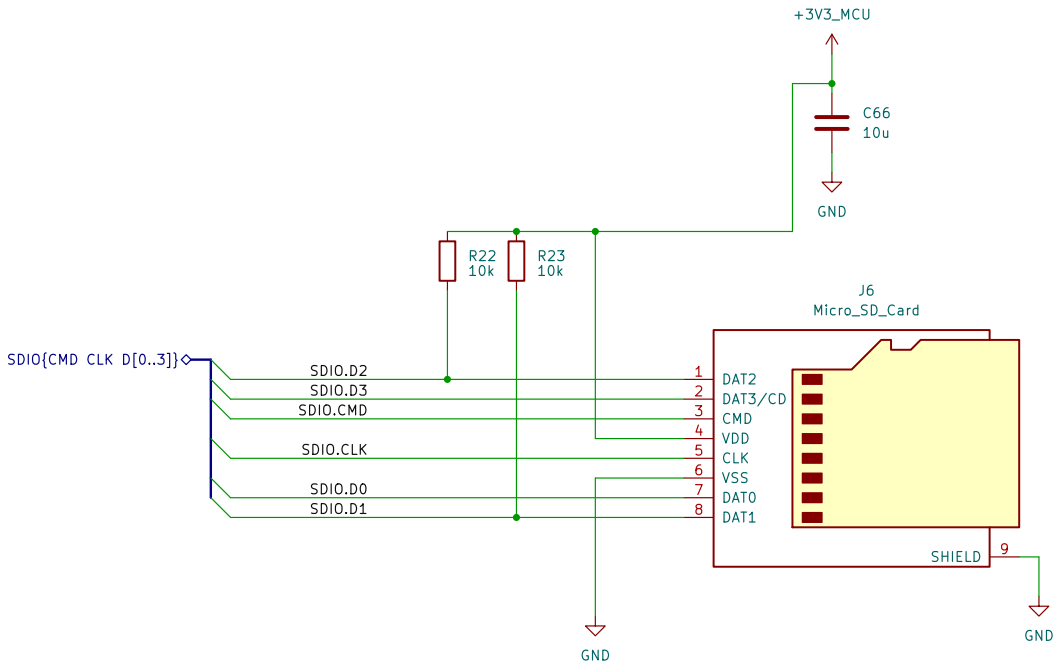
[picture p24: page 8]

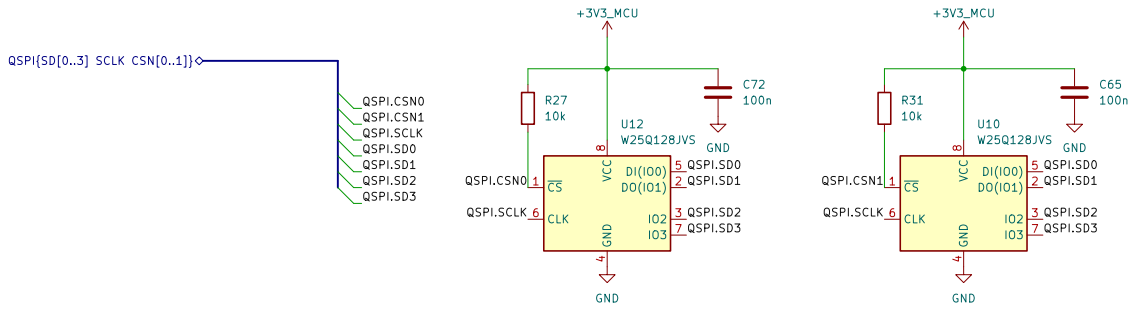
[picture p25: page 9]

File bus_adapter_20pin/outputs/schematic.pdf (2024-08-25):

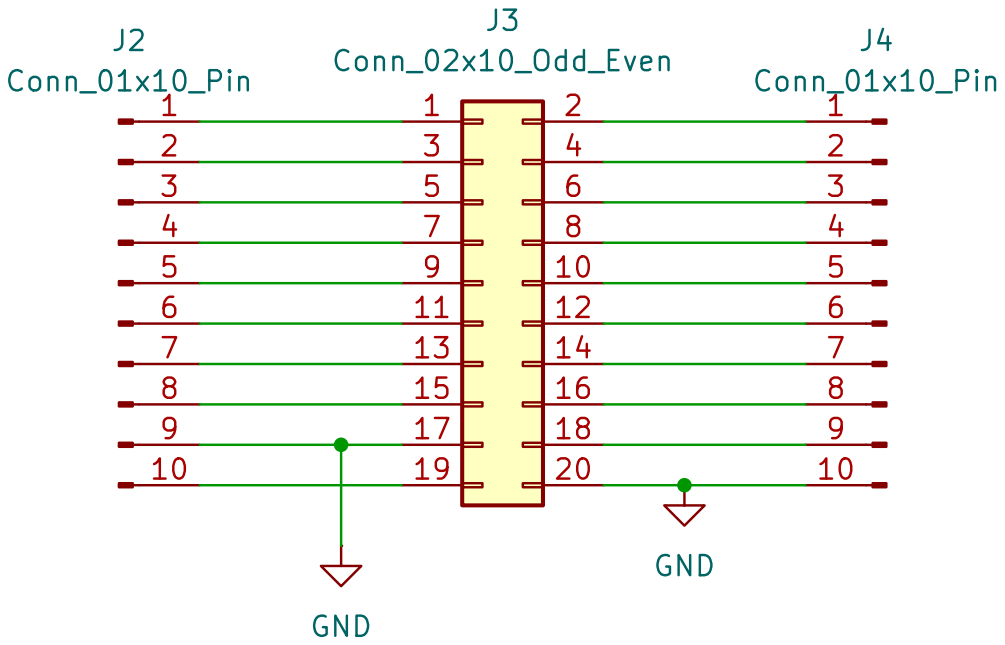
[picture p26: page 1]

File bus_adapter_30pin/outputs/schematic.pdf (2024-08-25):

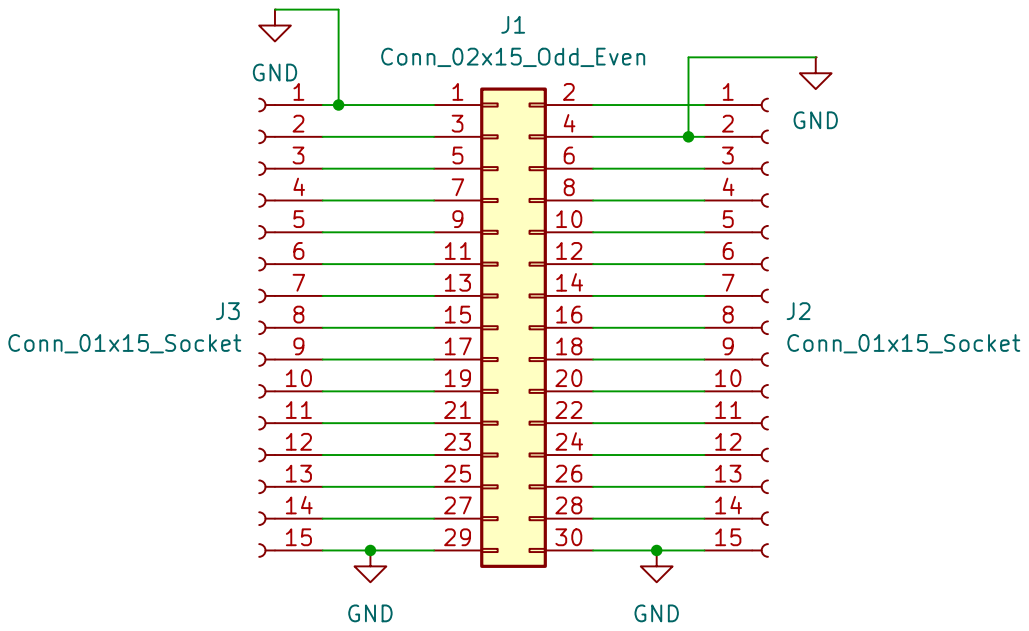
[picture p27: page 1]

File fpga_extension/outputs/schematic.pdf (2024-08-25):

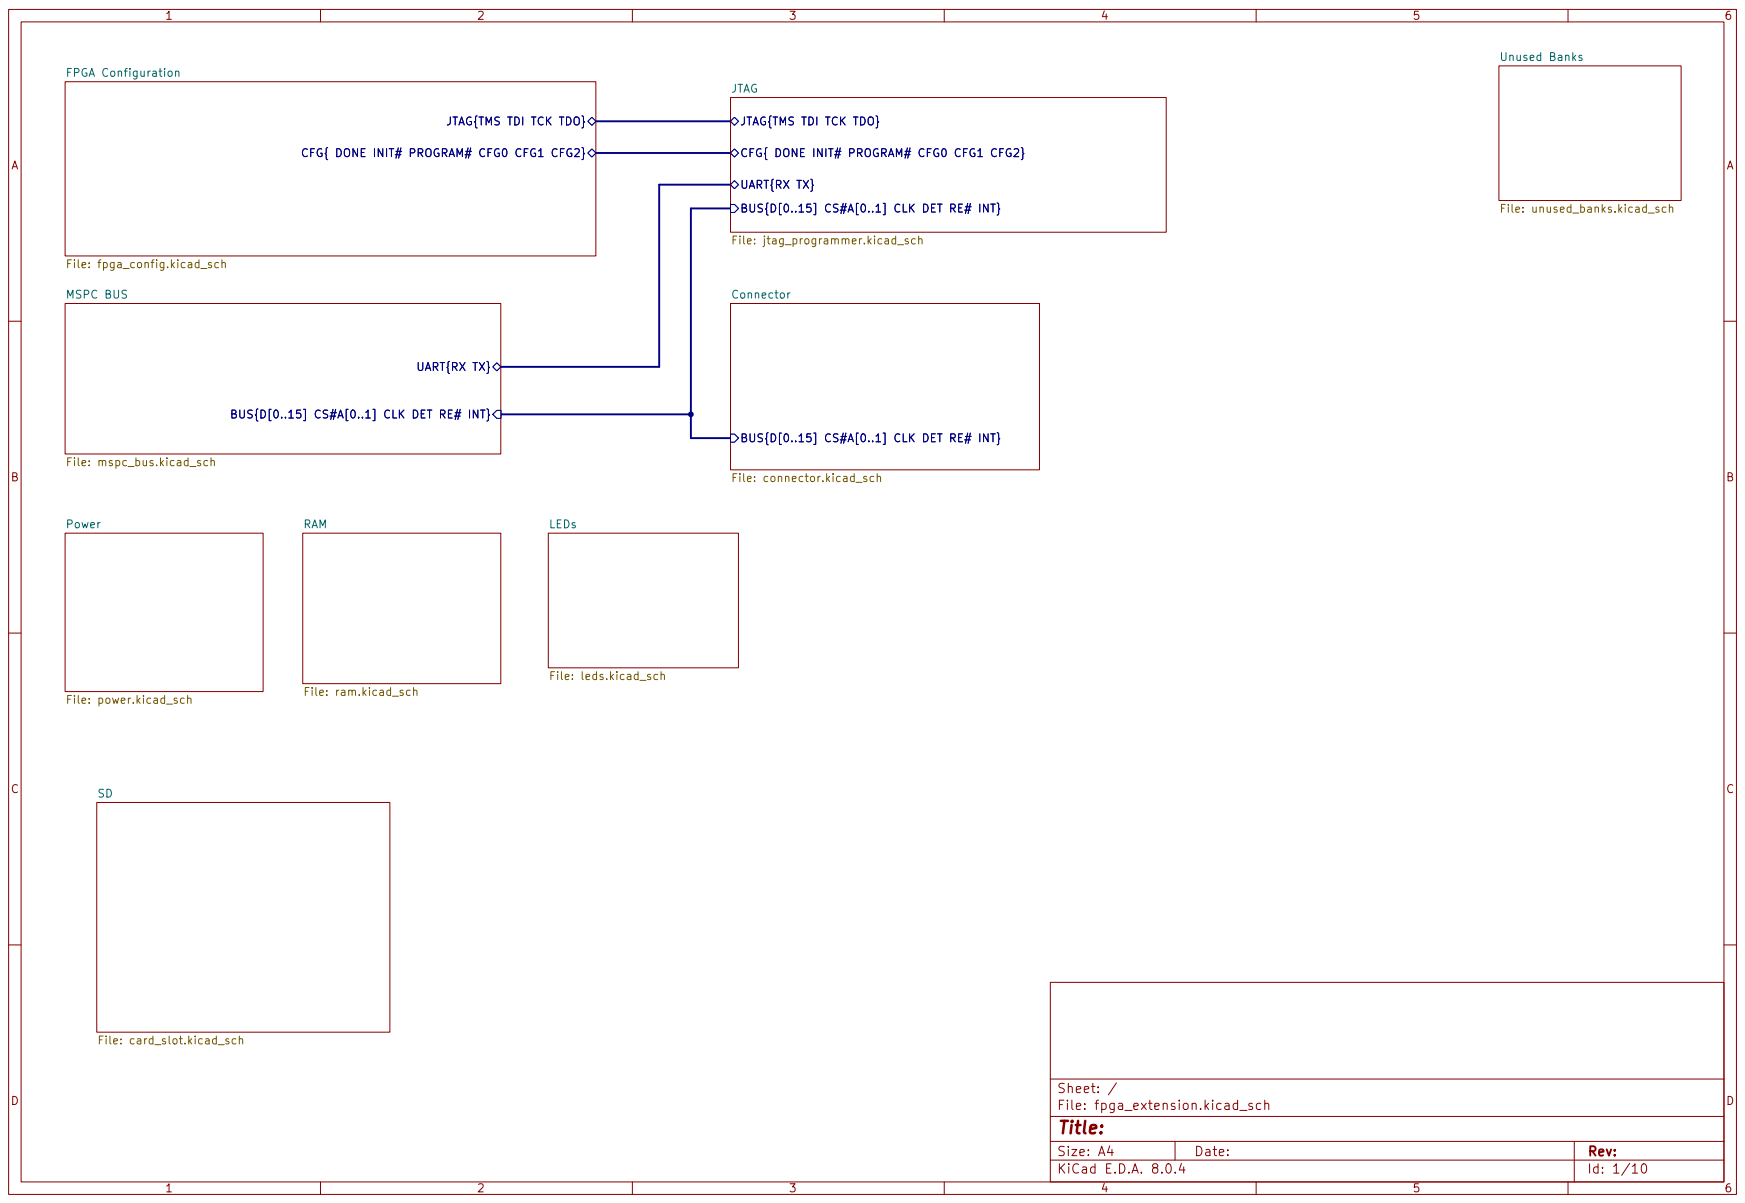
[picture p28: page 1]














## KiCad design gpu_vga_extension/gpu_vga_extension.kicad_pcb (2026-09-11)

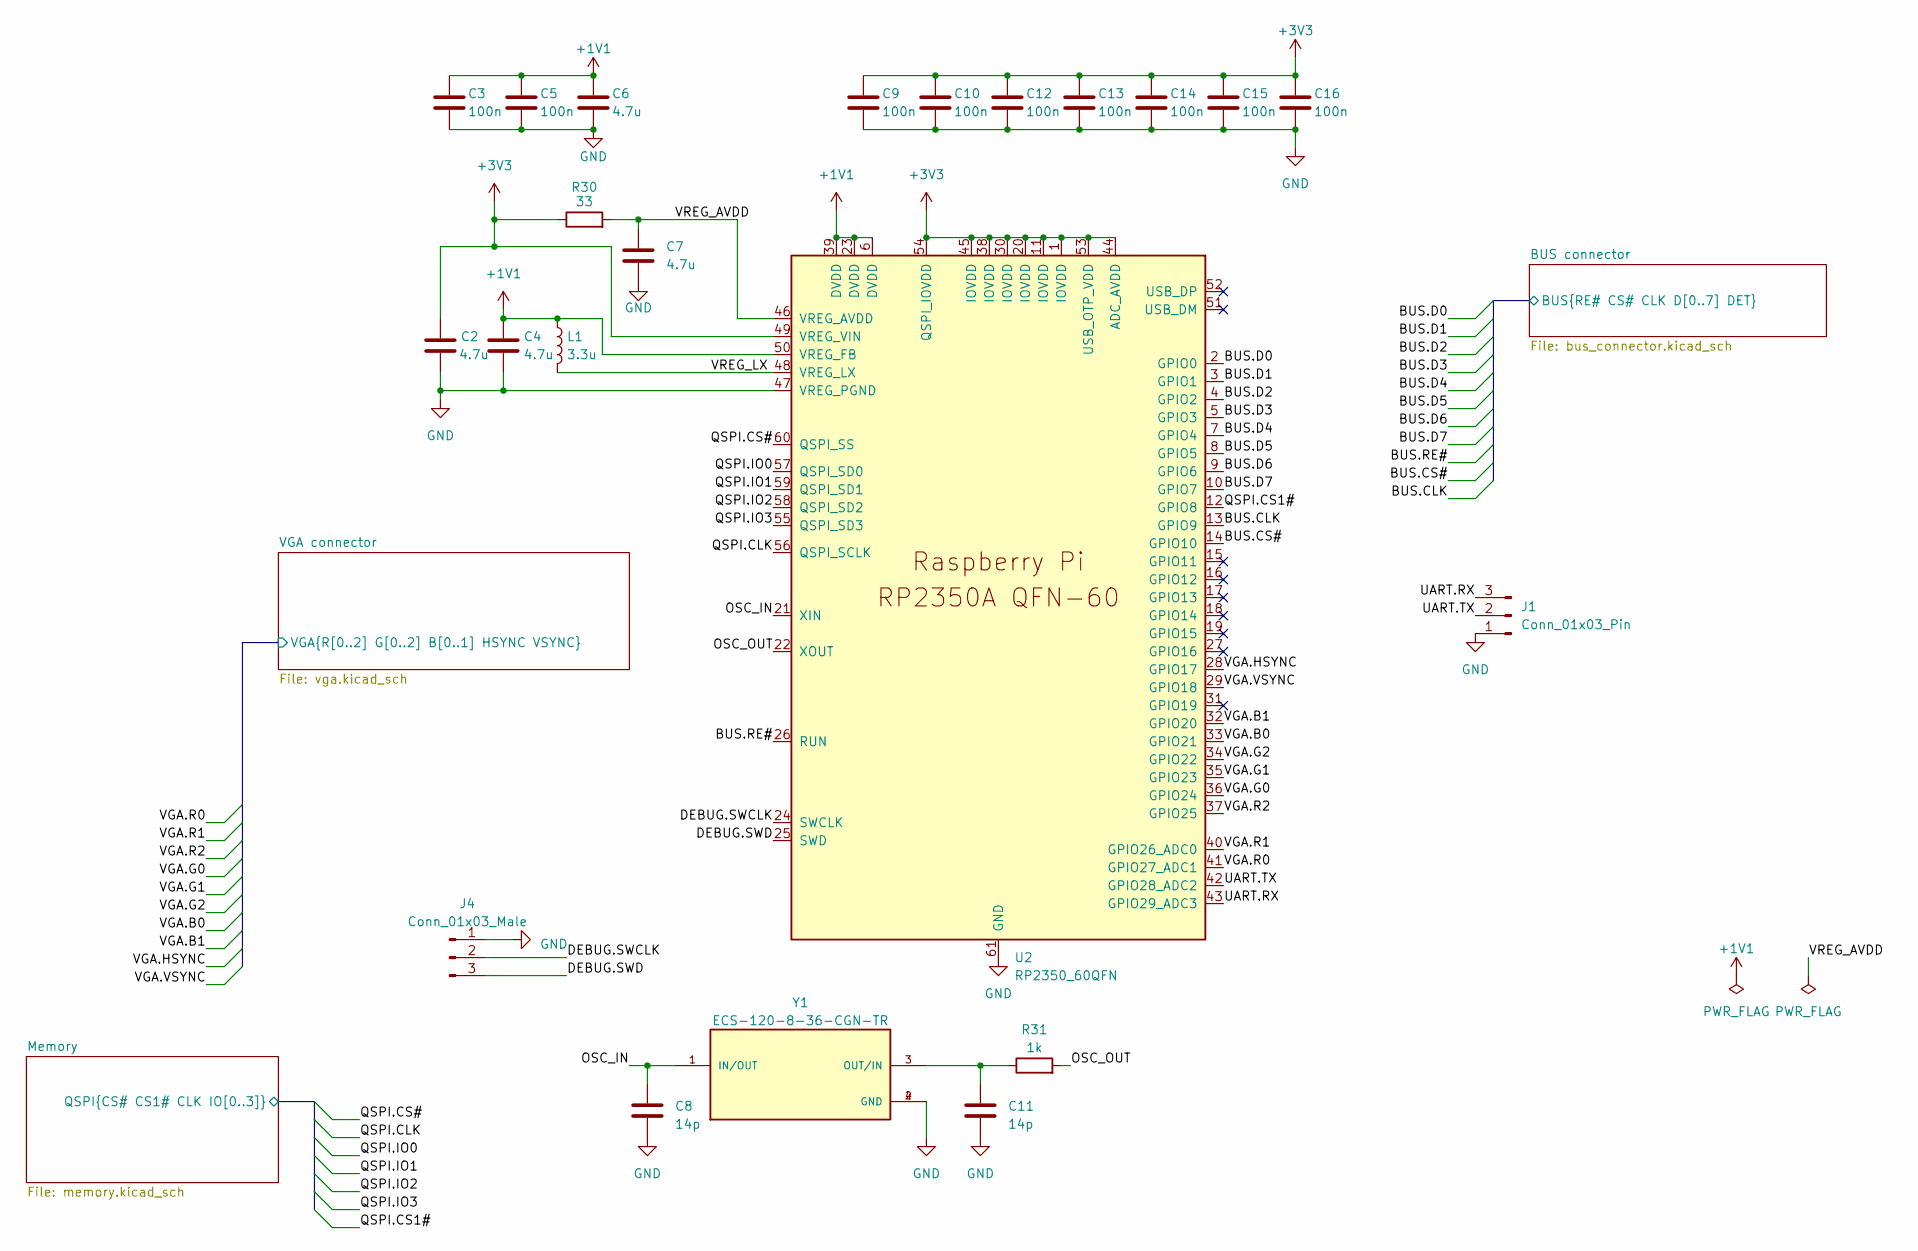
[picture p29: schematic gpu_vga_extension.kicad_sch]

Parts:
C2, C4, C6, C7: 4.7u; C_0402_1005Metric_Pad0.74x0.62mm_HandSolder
C3, C5, C9, C10, C12, C13, C14, C15, C16: 100n; C_0402_1005Metric_Pad0.74x0.62mm_HandSolder
C8, C11: 14p; C_0402_1005Metric_Pad0.74x0.62mm_HandSolder
J1: Conn_01x03_Pin; PinHeader_1x03_P2.54mm_Vertical
J4: Conn_01x03_Male; PinHeader_1x03_P2.54mm_Vertical
L1: 3.3u; L_0805_2012Metric_Pad1.15x1.40mm_HandSolder
R30: 33; R_0402_1005Metric_Pad0.72x0.64mm_HandSolder
R31: 1k; R_0402_1005Metric_Pad0.72x0.64mm_HandSolder
U2: RP2350_60QFN; RP2350-QFN-60-1EP_7x7_P0.4mm_EP3.4x3.4mm_ThermalVias
Y1: ECS-120-8-36-CGN-TR; XTAL_ECS-120-8-36-CGN-TR; PARTREV 2017

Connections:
+1V1: C3.1, C4.1, C5.1, C6.1, L1.1, U2.6 (DVDD), U2.23 (DVDD), U2.39 (DVDD), U2.50 (VREG_FB)
+3V3: C2.1, C9.1, C10.1, C12.1, C13.1, C14.1, C15.1, C16.1, R30.1, U2.1 (IOVDD), U2.11 (IOVDD), U2.20 (IOVDD), U2.30 (IOVDD), U2.38 (IOVDD), U2.44 (ADC_AVDD), U2.45 (IOVDD), U2.49 (VREG_VIN), U2.53 (USB_OTP_VDD), U2.54 (QSPI_IOVDD); also elsewhere on the board
/BUS connector/BUS.CLK: U2.13 (GPIO9); also elsewhere on the board
/BUS connector/BUS.CS#: U2.14 (GPIO10); also elsewhere on the board
/BUS connector/BUS.D0: U2.2 (GPIO0); also elsewhere on the board
/BUS connector/BUS.D1: U2.3 (GPIO1); also elsewhere on the board
/BUS connector/BUS.D2: U2.4 (GPIO2); also elsewhere on the board
/BUS connector/BUS.D3: U2.5 (GPIO3); also elsewhere on the board
/BUS connector/BUS.D4: U2.7 (GPIO4); also elsewhere on the board
/BUS connector/BUS.D5: U2.8 (GPIO5); also elsewhere on the board
/BUS connector/BUS.D6: U2.9 (GPIO6); also elsewhere on the board
/BUS connector/BUS.D7: U2.10 (GPIO7); also elsewhere on the board
/BUS connector/BUS.RE#: U2.26 (RUN); also elsewhere on the board
/DEBUG.SWCLK: J4.2, U2.24 (SWCLK)
/DEBUG.SWD: J4.3, U2.25 (SWD)
/Memory/QSPI.CLK: U2.56 (QSPI_SCLK); also elsewhere on the board
/Memory/QSPI.CS1#: U2.12 (GPIO8); also elsewhere on the board
/Memory/QSPI.CS#: U2.60 (QSPI_SS); also elsewhere on the board
/Memory/QSPI.IO0: U2.57 (QSPI_SD0); also elsewhere on the board
/Memory/QSPI.IO1: U2.59 (QSPI_SD1); also elsewhere on the board
/Memory/QSPI.IO2: U2.58 (QSPI_SD2); also elsewhere on the board
/Memory/QSPI.IO3: U2.55 (QSPI_SD3); also elsewhere on the board
/OSC_IN: C8.1, U2.21 (XIN), Y1.1 (IN/OUT)
/OSC_OUT: R31.2, U2.22 (XOUT)
/UART.RX: J1.3, U2.43 (GPIO29_ADC3)
/UART.TX: J1.2, U2.42 (GPIO28_ADC2)
/VGA connector/VGA.B0: U2.33 (GPIO21); also elsewhere on the board
/VGA connector/VGA.B1: U2.32 (GPIO20); also elsewhere on the board
/VGA connector/VGA.G0: U2.36 (GPIO24); also elsewhere on the board
/VGA connector/VGA.G1: U2.35 (GPIO23); also elsewhere on the board
/VGA connector/VGA.G2: U2.34 (GPIO22); also elsewhere on the board
/VGA connector/VGA.HSYNC: U2.28 (GPIO17); also elsewhere on the board
/VGA connector/VGA.R0: U2.41 (GPIO27_ADC1); also elsewhere on the board
/VGA connector/VGA.R1: U2.40 (GPIO26_ADC0); also elsewhere on the board
/VGA connector/VGA.R2: U2.37 (GPIO25); also elsewhere on the board
/VGA connector/VGA.VSYNC: U2.29 (GPIO18); also elsewhere on the board
/VREG_AVDD: C7.1, R30.2, U2.46 (VREG_AVDD)
/VREG_LX: L1.2, U2.48 (VREG_LX)
GND: C2.2, C3.2, C4.2, C5.2, C6.2, C7.2, C8.2, C9.2, C10.2, C11.2, C12.2, C13.2, C14.2, C15.2, C16.2, J1.1, J4.1, U2.47 (VREG_PGND), U2.61 (GND), Y1.2 (GND), Y1.4 (GND); also elsewhere on the board
unnamed: C11.1, R31.1, Y1.3 (OUT/IN)

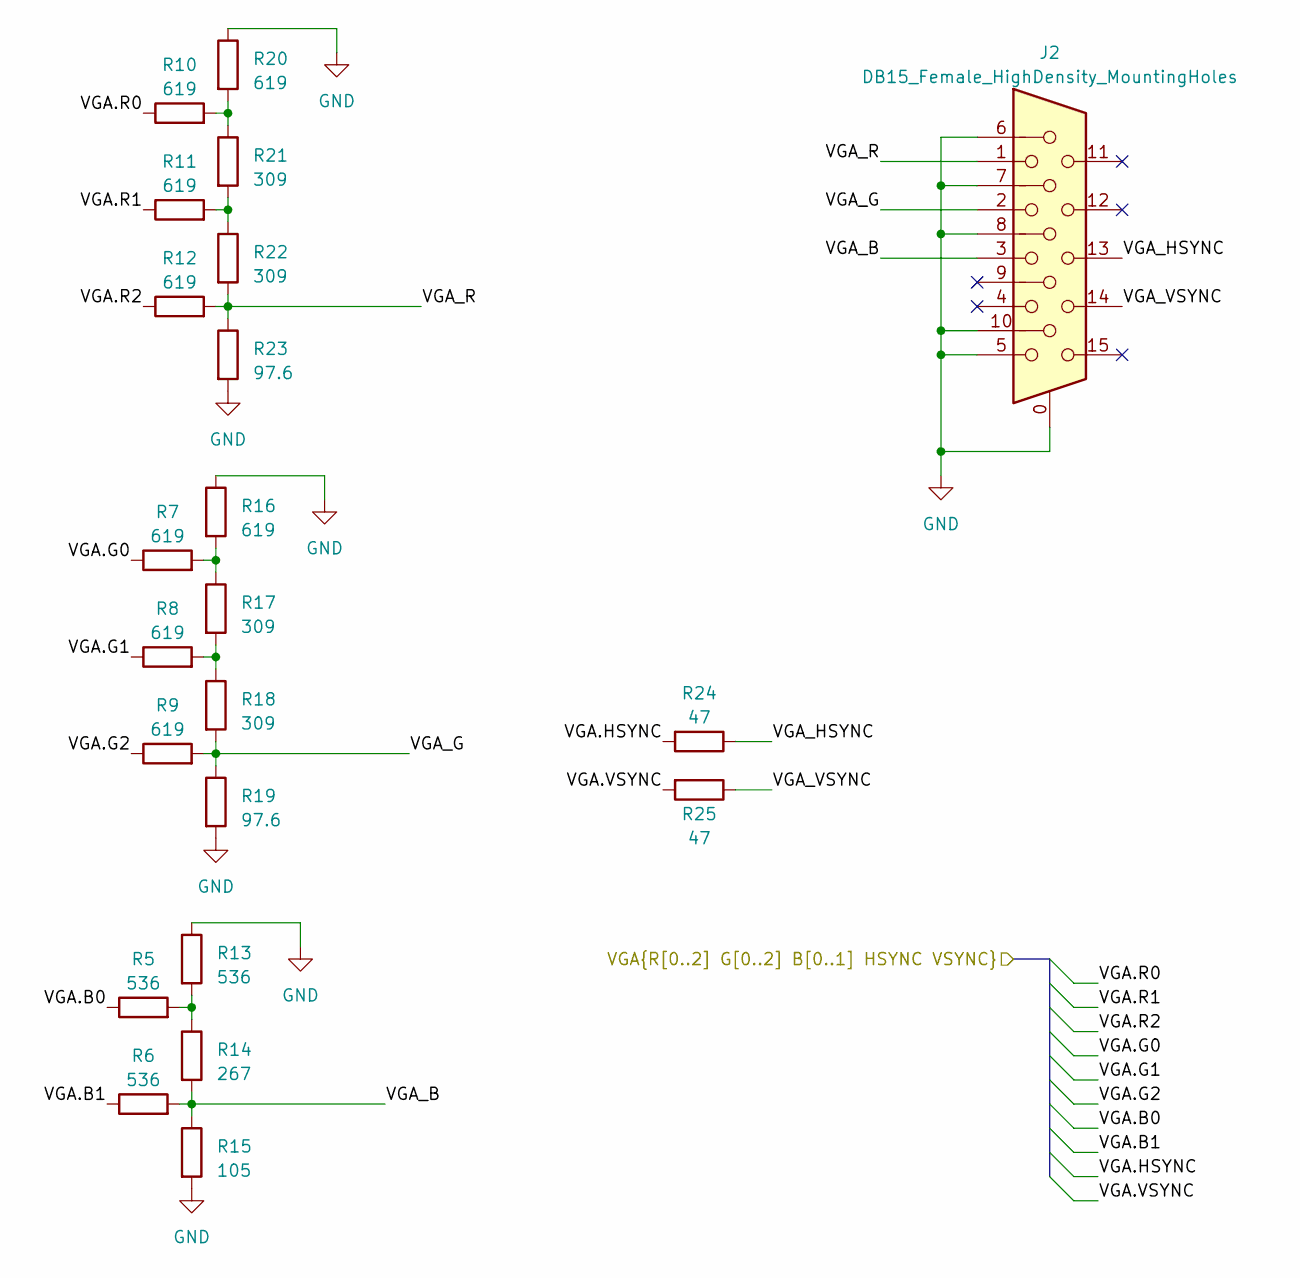
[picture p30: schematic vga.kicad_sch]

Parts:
J2: DB15_Female_HighDensity_MountingHoles; DSUB-15-HD_Female_Horizontal_P2.29x1.98mm_EdgePinOffset3.03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
R5, R6, R13: 536; R_0402_1005Metric_Pad0.72x0.64mm_HandSolder
R7, R8, R9, R10, R11, R12, R16, R20: 619; R_0402_1005Metric_Pad0.72x0.64mm_HandSolder
R14: 267; R_0402_1005Metric_Pad0.72x0.64mm_HandSolder
R15: 105; R_0402_1005Metric_Pad0.72x0.64mm_HandSolder
R17, R18, R21, R22: 309; R_0402_1005Metric_Pad0.72x0.64mm_HandSolder
R19, R23: 97.6; R_0402_1005Metric_Pad0.72x0.64mm_HandSolder
R24, R25: 47; R_0402_1005Metric_Pad0.72x0.64mm_HandSolder

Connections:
/VGA connector/VGA.B0: R5.1; also elsewhere on the board
/VGA connector/VGA.B1: R6.1; also elsewhere on the board
/VGA connector/VGA.G0: R7.1; also elsewhere on the board
/VGA connector/VGA.G1: R8.1; also elsewhere on the board
/VGA connector/VGA.G2: R9.1; also elsewhere on the board
/VGA connector/VGA.HSYNC: R24.2; also elsewhere on the board
/VGA connector/VGA.R0: R10.1; also elsewhere on the board
/VGA connector/VGA.R1: R11.1; also elsewhere on the board
/VGA connector/VGA.R2: R12.1; also elsewhere on the board
/VGA connector/VGA.VSYNC: R25.2; also elsewhere on the board
/VGA connector/VGA_B: J2.3, R6.2, R14.2, R15.1
/VGA connector/VGA_G: J2.2, R9.2, R18.2, R19.1
/VGA connector/VGA_HSYNC: J2.13, R24.1
/VGA connector/VGA_R: J2.1, R12.2, R22.2, R23.1
/VGA connector/VGA_VSYNC: J2.14, R25.1
GND: J2.0, J2.5, J2.6, J2.7, J2.8, J2.10, R13.1, R15.2, R16.1, R19.2, R20.1, R23.2; also elsewhere on the board
unnamed: R10.2, R20.2, R21.1
unnamed: R11.2, R21.2, R22.1
unnamed: R5.2, R13.2, R14.1
unnamed: R7.2, R16.2, R17.1
unnamed: R8.2, R17.2, R18.1

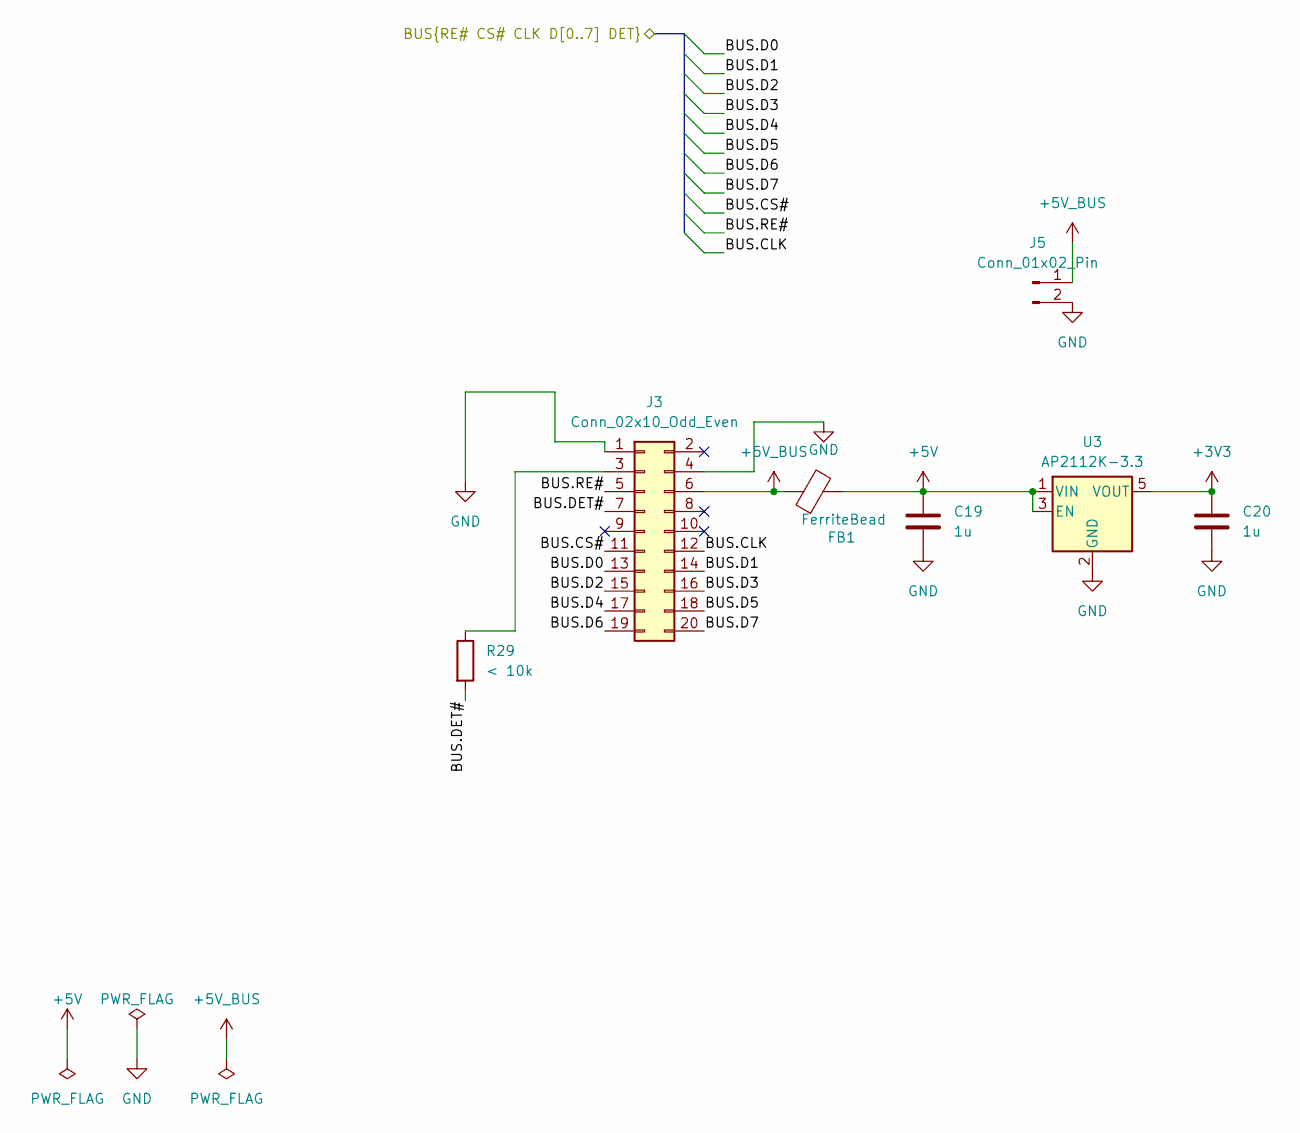
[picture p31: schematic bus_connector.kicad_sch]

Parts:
C19, C20: 1u; C_0402_1005Metric_Pad0.74x0.62mm_HandSolder
FB1: FerriteBead; L_0805_2012Metric_Pad1.05x1.20mm_HandSolder
J3: Conn_02x10_Odd_Even; PinHeader_2x10_P1.27mm_Vertical_SMD
J5: Conn_01x02_Pin; PinHeader_1x02_P2.54mm_Vertical
R29: < 10k; R_0402_1005Metric_Pad0.72x0.64mm_HandSolder
U3: AP2112K-3.3; SOT-23-5_HandSoldering

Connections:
+3V3: C20.1, U3.5 (VOUT); also elsewhere on the board
+5V: C19.1, FB1.2, U3.1 (VIN), U3.3 (EN)
+5V_BUS: FB1.1, J3.6, J5.1
/BUS connector/BUS.CLK: J3.12; also elsewhere on the board
/BUS connector/BUS.CS#: J3.11; also elsewhere on the board
/BUS connector/BUS.D0: J3.13; also elsewhere on the board
/BUS connector/BUS.D1: J3.14; also elsewhere on the board
/BUS connector/BUS.D2: J3.15; also elsewhere on the board
/BUS connector/BUS.D3: J3.16; also elsewhere on the board
/BUS connector/BUS.D4: J3.17; also elsewhere on the board
/BUS connector/BUS.D5: J3.18; also elsewhere on the board
/BUS connector/BUS.D6: J3.19; also elsewhere on the board
/BUS connector/BUS.D7: J3.20; also elsewhere on the board
/BUS connector/BUS.DET#: J3.7, R29.2
/BUS connector/BUS.RE#: J3.5; also elsewhere on the board
GND: C19.2, C20.2, J3.1, J3.4, J5.2, U3.2 (GND); also elsewhere on the board
unnamed: J3.3, R29.1

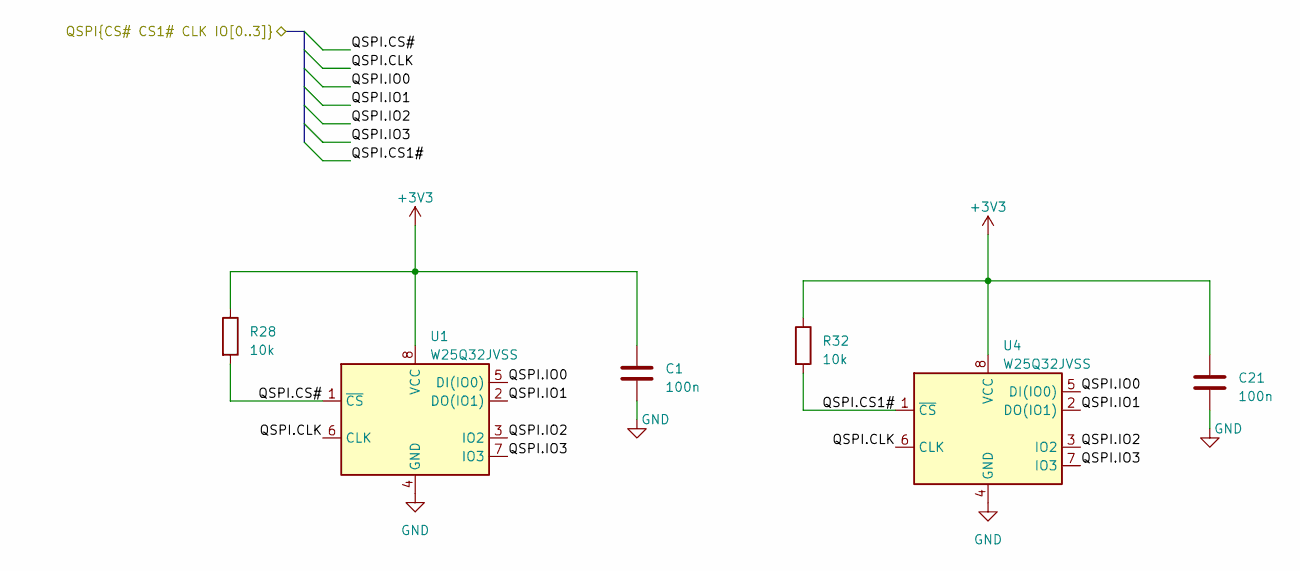
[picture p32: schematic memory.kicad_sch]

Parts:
C1, C21: 100n; C_0402_1005Metric_Pad0.74x0.62mm_HandSolder
R28, R32: 10k; R_0402_1005Metric_Pad0.72x0.64mm_HandSolder
U1, U4: W25Q32JVSS; SOIC-8_5.23x5.23mm_P1.27mm

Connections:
+3V3: C1.1, C21.1, R28.1, R32.1, U1.8 (VCC), U4.8 (VCC); also elsewhere on the board
/Memory/QSPI.CLK: U1.6 (CLK), U4.6 (CLK); also elsewhere on the board
/Memory/QSPI.CS1#: R32.2, U4.1 (~CS); also elsewhere on the board
/Memory/QSPI.CS#: R28.2, U1.1 (~CS); also elsewhere on the board
/Memory/QSPI.IO0: U1.5 (DI(IO0)), U4.5 (DI(IO0)); also elsewhere on the board
/Memory/QSPI.IO1: U1.2 (DO(IO1)), U4.2 (DO(IO1)); also elsewhere on the board
/Memory/QSPI.IO2: U1.3 (IO2), U4.3 (IO2); also elsewhere on the board
/Memory/QSPI.IO3: U1.7 (IO3), U4.7 (IO3); also elsewhere on the board
GND: C1.2, C21.2, U1.4 (GND), U4.4 (GND); also elsewhere on the board

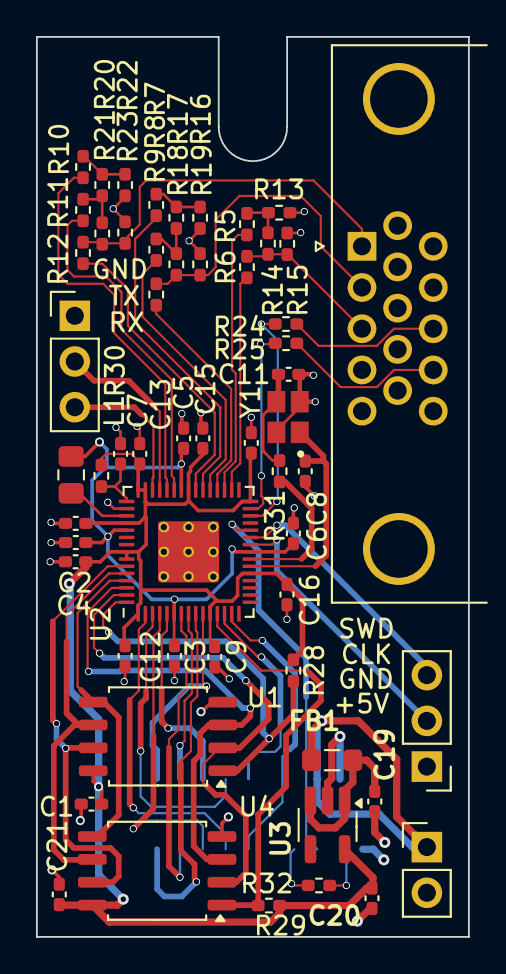
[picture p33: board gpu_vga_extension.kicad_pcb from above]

Board: 4 copper layers, 24.0 x 50.0 mm, 57 parts (1 on the bottom side), 54 nets.

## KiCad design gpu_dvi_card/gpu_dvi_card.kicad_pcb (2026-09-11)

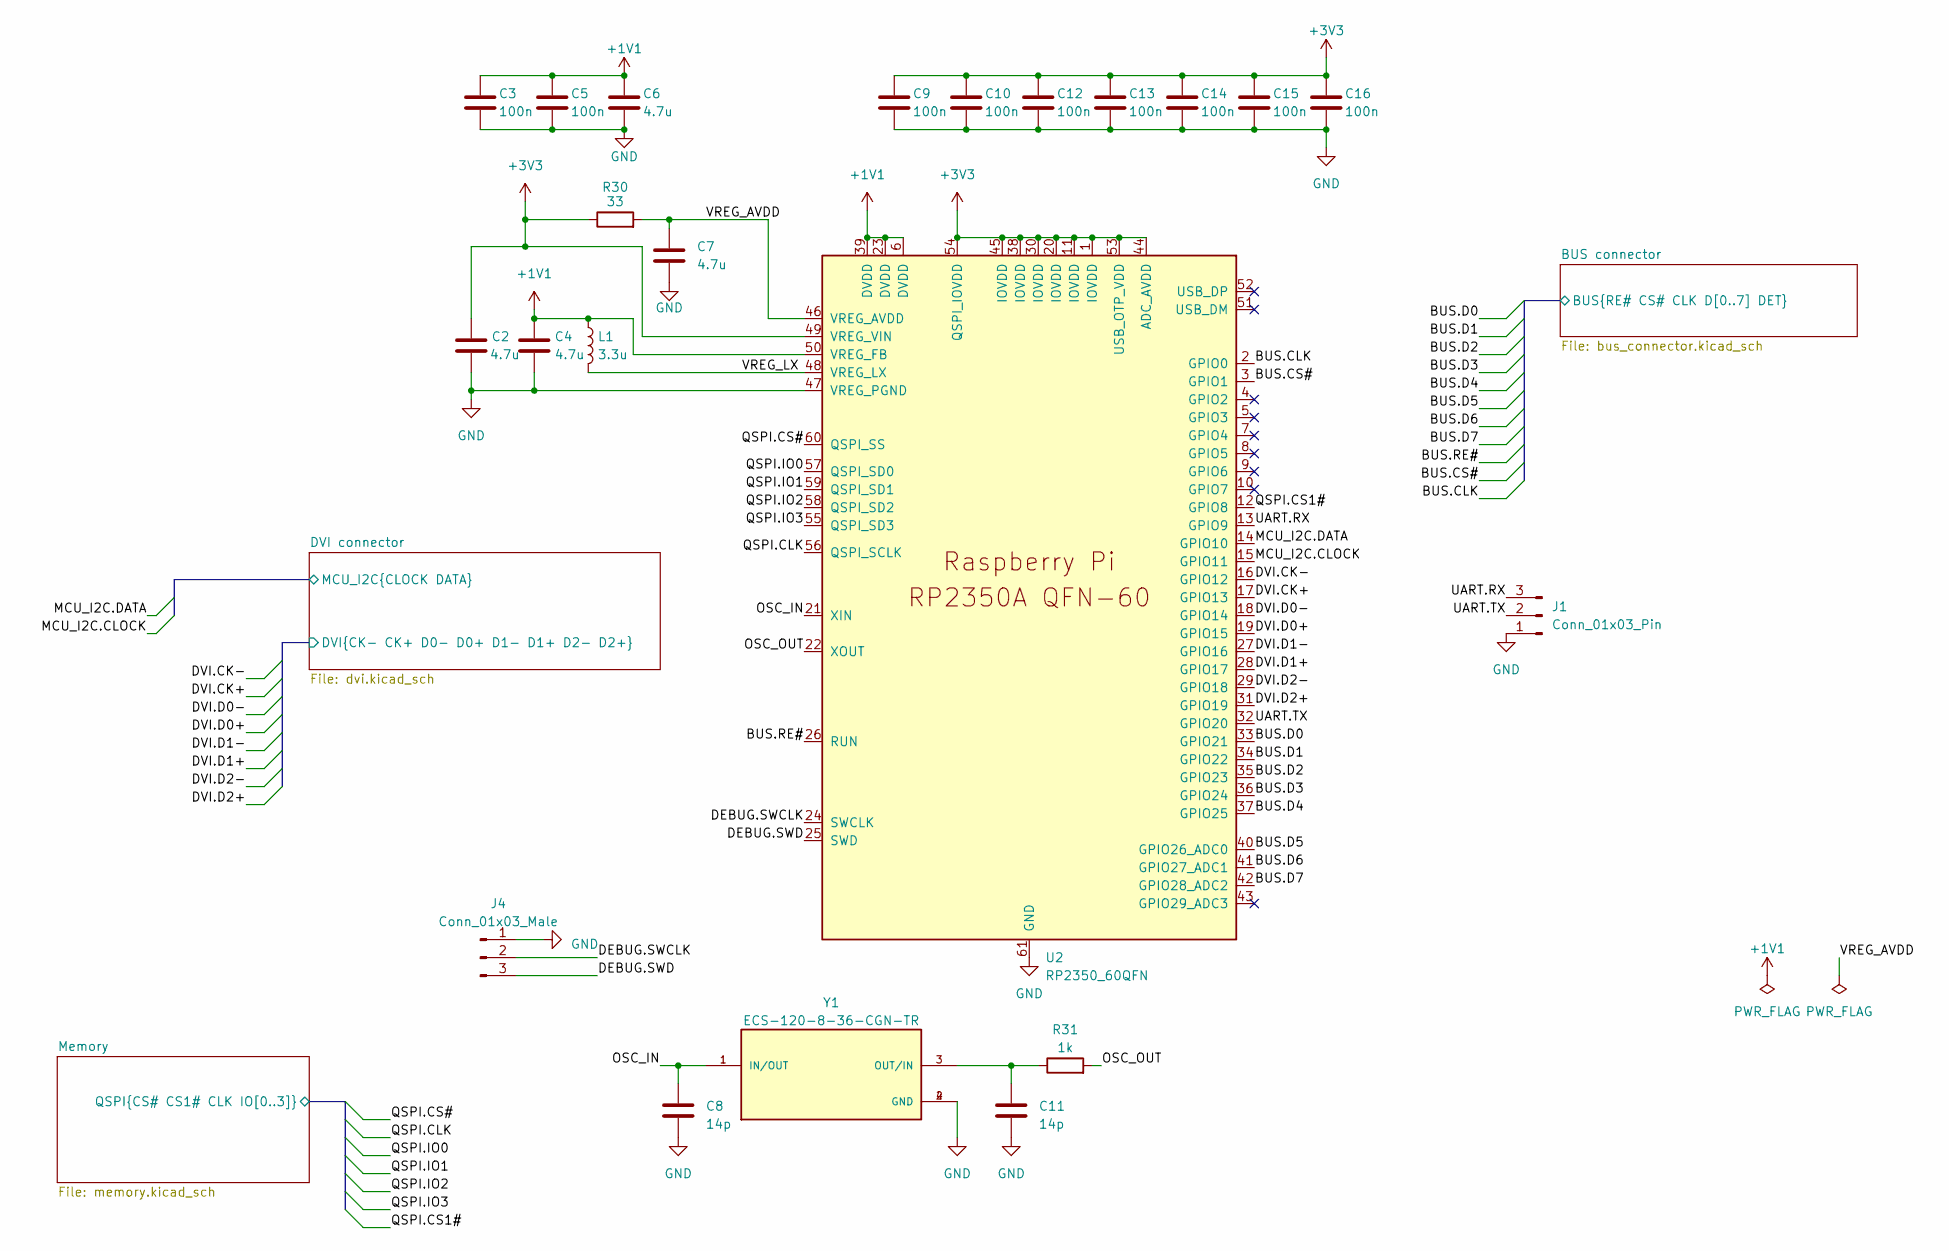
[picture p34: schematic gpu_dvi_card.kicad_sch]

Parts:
C2, C4, C6, C7: 4.7u; C_0402_1005Metric_Pad0.74x0.62mm_HandSolder
C3, C5, C9, C10, C12, C13, C14, C15, C16: 100n; C_0402_1005Metric_Pad0.74x0.62mm_HandSolder
C8, C11: 14p; C_0402_1005Metric_Pad0.74x0.62mm_HandSolder
J1: Conn_01x03_Pin; PinHeader_1x03_P2.54mm_Vertical
J4: Conn_01x03_Male; PinHeader_1x03_P2.54mm_Vertical
L1: 3.3u; L_0805_2012Metric_Pad1.15x1.40mm_HandSolder
R30: 33; R_0402_1005Metric_Pad0.72x0.64mm_HandSolder
R31: 1k; R_0402_1005Metric_Pad0.72x0.64mm_HandSolder
U2: RP2350_60QFN; RP2350-QFN-60-1EP_7x7_P0.4mm_EP3.4x3.4mm_ThermalVias
Y1: ECS-120-8-36-CGN-TR; XTAL_ECS-120-8-36-CGN-TR; PARTREV 2017

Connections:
+1V1: C3.1, C4.1, C5.1, C6.1, L1.1, U2.6 (DVDD), U2.23 (DVDD), U2.39 (DVDD), U2.50 (VREG_FB)
+3V3: C2.1, C9.1, C10.1, C12.1, C13.1, C14.1, C15.1, C16.1, R30.1, U2.1 (IOVDD), U2.11 (IOVDD), U2.20 (IOVDD), U2.30 (IOVDD), U2.38 (IOVDD), U2.44 (ADC_AVDD), U2.45 (IOVDD), U2.49 (VREG_VIN), U2.53 (USB_OTP_VDD), U2.54 (QSPI_IOVDD); also elsewhere on the board
/BUS connector/BUS.CLK: U2.2 (GPIO0); also elsewhere on the board
/BUS connector/BUS.CS#: U2.3 (GPIO1); also elsewhere on the board
/BUS connector/BUS.D0: U2.33 (GPIO21); also elsewhere on the board
/BUS connector/BUS.D1: U2.34 (GPIO22); also elsewhere on the board
/BUS connector/BUS.D2: U2.35 (GPIO23); also elsewhere on the board
/BUS connector/BUS.D3: U2.36 (GPIO24); also elsewhere on the board
/BUS connector/BUS.D4: U2.37 (GPIO25); also elsewhere on the board
/BUS connector/BUS.D5: U2.40 (GPIO26_ADC0); also elsewhere on the board
/BUS connector/BUS.D6: U2.41 (GPIO27_ADC1); also elsewhere on the board
/BUS connector/BUS.D7: U2.42 (GPIO28_ADC2); also elsewhere on the board
/BUS connector/BUS.RE#: U2.26 (RUN); also elsewhere on the board
/DEBUG.SWCLK: J4.2, U2.24 (SWCLK)
/DEBUG.SWD: J4.3, U2.25 (SWD)
/DVI connector/DVI.CK+: U2.17 (GPIO13); also elsewhere on the board
/DVI connector/DVI.CK-: U2.16 (GPIO12); also elsewhere on the board
/DVI connector/DVI.D0+: U2.19 (GPIO15); also elsewhere on the board
/DVI connector/DVI.D0-: U2.18 (GPIO14); also elsewhere on the board
/DVI connector/DVI.D1+: U2.28 (GPIO17); also elsewhere on the board
/DVI connector/DVI.D1-: U2.27 (GPIO16); also elsewhere on the board
/DVI connector/DVI.D2+: U2.31 (GPIO19); also elsewhere on the board
/DVI connector/DVI.D2-: U2.29 (GPIO18); also elsewhere on the board
/DVI connector/MCU_I2C.CLOCK: U2.15 (GPIO11); also elsewhere on the board
/DVI connector/MCU_I2C.DATA: U2.14 (GPIO10); also elsewhere on the board
/Memory/QSPI.CLK: U2.56 (QSPI_SCLK); also elsewhere on the board
/Memory/QSPI.CS1#: U2.12 (GPIO8); also elsewhere on the board
/Memory/QSPI.CS#: U2.60 (QSPI_SS); also elsewhere on the board
/Memory/QSPI.IO0: U2.57 (QSPI_SD0); also elsewhere on the board
/Memory/QSPI.IO1: U2.59 (QSPI_SD1); also elsewhere on the board
/Memory/QSPI.IO2: U2.58 (QSPI_SD2); also elsewhere on the board
/Memory/QSPI.IO3: U2.55 (QSPI_SD3); also elsewhere on the board
/OSC_IN: C8.1, U2.21 (XIN), Y1.1 (IN/OUT)
/OSC_OUT: R31.2, U2.22 (XOUT)
/UART.RX: J1.3, U2.13 (GPIO9)
/UART.TX: J1.2, U2.32 (GPIO20)
/VREG_AVDD: C7.1, R30.2, U2.46 (VREG_AVDD)
/VREG_LX: L1.2, U2.48 (VREG_LX)
GND: C2.2, C3.2, C4.2, C5.2, C6.2, C7.2, C8.2, C9.2, C10.2, C11.2, C12.2, C13.2, C14.2, C15.2, C16.2, J1.1, J4.1, U2.47 (VREG_PGND), U2.61 (GND), Y1.2 (GND), Y1.4 (GND); also elsewhere on the board
unnamed: C11.1, R31.1, Y1.3 (OUT/IN)

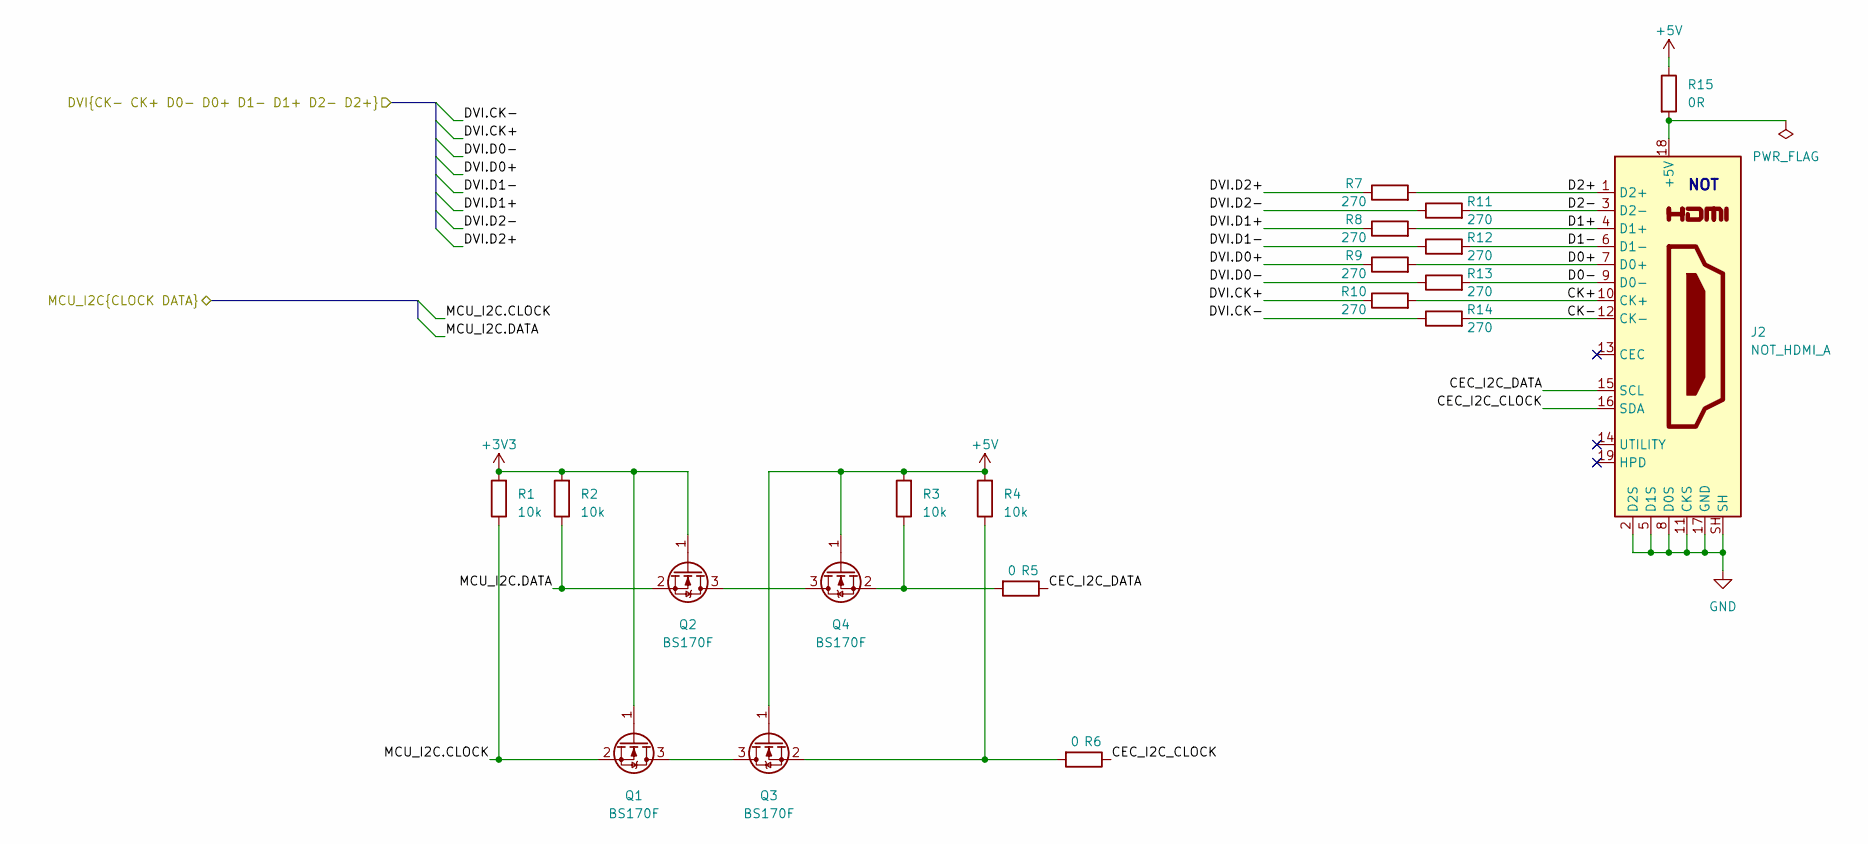
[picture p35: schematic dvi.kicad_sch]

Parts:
J2: NOT_HDMI_A; HDMI_A_Molex_208658-1001_Horizontal
Q1, Q2, Q3, Q4: BS170F; SOT-23
R1, R2, R3, R4: 10k; R_0402_1005Metric_Pad0.72x0.64mm_HandSolder
R5, R6: 0; R_0402_1005Metric_Pad0.72x0.64mm_HandSolder
R7, R8, R9, R10, R11, R12, R13, R14: 270; R_0402_1005Metric_Pad0.72x0.64mm_HandSolder
R15: 0R; R_0402_1005Metric_Pad0.72x0.64mm_HandSolder

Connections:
+3V3: Q1.1 (G), Q2.1 (G), R1.2, R2.2; also elsewhere on the board
+5V: Q3.1 (G), Q4.1 (G), R3.2, R4.2, R15.1; also elsewhere on the board
/DVI connector/CEC_I2C_CLOCK: J2.16 (SDA), R6.1
/DVI connector/CEC_I2C_DATA: J2.15 (SCL), R5.1
/DVI connector/CK+: J2.10 (CK+), R10.2
/DVI connector/CK-: J2.12 (CK-), R14.2
/DVI connector/D0+: J2.7 (D0+), R9.2
/DVI connector/D0-: J2.9 (D0-), R13.2
/DVI connector/D1+: J2.4 (D1+), R8.2
/DVI connector/D1-: J2.6 (D1-), R12.2
/DVI connector/D2+: J2.1 (D2+), R7.2
/DVI connector/D2-: J2.3 (D2-), R11.2
/DVI connector/DVI.CK+: R10.1; also elsewhere on the board
/DVI connector/DVI.CK-: R14.1; also elsewhere on the board
/DVI connector/DVI.D0+: R9.1; also elsewhere on the board
/DVI connector/DVI.D0-: R13.1; also elsewhere on the board
/DVI connector/DVI.D1+: R8.1; also elsewhere on the board
/DVI connector/DVI.D1-: R12.1; also elsewhere on the board
/DVI connector/DVI.D2+: R7.1; also elsewhere on the board
/DVI connector/DVI.D2-: R11.1; also elsewhere on the board
/DVI connector/MCU_I2C.CLOCK: Q1.2 (S), R1.1; also elsewhere on the board
/DVI connector/MCU_I2C.DATA: Q2.2 (S), R2.1; also elsewhere on the board
GND: J2.2 (D2S), J2.5 (D1S), J2.8 (D0S), J2.11 (CKS), J2.17 (GND), J2.SH; also elsewhere on the board
unnamed: J2.18 (+5V), R15.2
unnamed: Q1.3 (D), Q3.3 (D)
unnamed: Q2.3 (D), Q4.3 (D)
unnamed: Q3.2 (S), R4.1, R6.2
unnamed: Q4.2 (S), R3.1, R5.2

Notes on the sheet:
NOT


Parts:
C19, C20: 1u; C_0402_1005Metric_Pad0.74x0.62mm_HandSolder
FB1: FerriteBead; L_0805_2012Metric_Pad1.05x1.20mm_HandSolder
J3: Conn_02x10_Odd_Even; PinHeader_2x10_P1.27mm_Vertical_SMD
J5: Conn_01x02_Pin; PinHeader_1x02_P2.54mm_Vertical
R29: < 10k; R_0402_1005Metric_Pad0.72x0.64mm_HandSolder
U3: AP2112K-3.3; SOT-23-5_HandSoldering

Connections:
+3V3: C20.1, U3.5 (VOUT); also elsewhere on the board
+5V: C19.1, FB1.2, U3.1 (VIN), U3.3 (EN); also elsewhere on the board
+5V_BUS: FB1.1, J3.6, J5.1
/BUS connector/BUS.CLK: J3.12; also elsewhere on the board
/BUS connector/BUS.CS#: J3.11; also elsewhere on the board
/BUS connector/BUS.D0: J3.13; also elsewhere on the board
/BUS connector/BUS.D1: J3.14; also elsewhere on the board
/BUS connector/BUS.D2: J3.15; also elsewhere on the board
/BUS connector/BUS.D3: J3.16; also elsewhere on the board
/BUS connector/BUS.D4: J3.17; also elsewhere on the board
/BUS connector/BUS.D5: J3.18; also elsewhere on the board
/BUS connector/BUS.D6: J3.19; also elsewhere on the board
/BUS connector/BUS.D7: J3.20; also elsewhere on the board
/BUS connector/BUS.DET#: J3.7, R29.2
/BUS connector/BUS.RE#: J3.5; also elsewhere on the board
GND: C19.2, C20.2, J3.1, J3.4, J5.2, U3.2 (GND); also elsewhere on the board
unnamed: J3.3, R29.1


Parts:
C1, C21: 100n; C_0402_1005Metric_Pad0.74x0.62mm_HandSolder
R28, R32: 10k; R_0402_1005Metric_Pad0.72x0.64mm_HandSolder
U1, U4: W25Q32JVSS; SOIC-8_5.23x5.23mm_P1.27mm

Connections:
+3V3: C1.1, C21.1, R28.1, R32.1, U1.8 (VCC), U4.8 (VCC); also elsewhere on the board
/Memory/QSPI.CLK: U1.6 (CLK), U4.6 (CLK); also elsewhere on the board
/Memory/QSPI.CS1#: R32.2, U4.1 (~CS); also elsewhere on the board
/Memory/QSPI.CS#: R28.2, U1.1 (~CS); also elsewhere on the board
/Memory/QSPI.IO0: U1.5 (DI(IO0)), U4.5 (DI(IO0)); also elsewhere on the board
/Memory/QSPI.IO1: U1.2 (DO(IO1)), U4.2 (DO(IO1)); also elsewhere on the board
/Memory/QSPI.IO2: U1.3 (IO2), U4.3 (IO2); also elsewhere on the board
/Memory/QSPI.IO3: U1.7 (IO3), U4.7 (IO3); also elsewhere on the board
GND: C1.2, C21.2, U1.4 (GND), U4.4 (GND); also elsewhere on the board

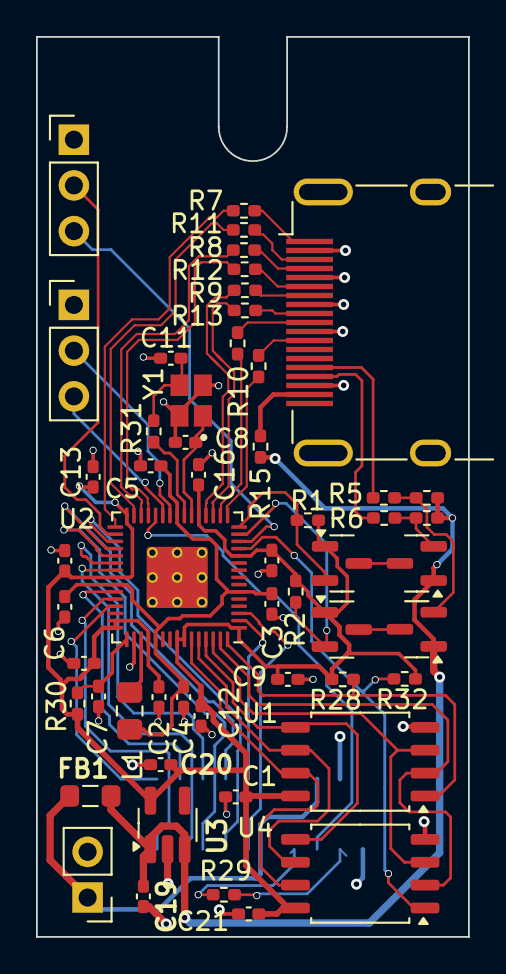
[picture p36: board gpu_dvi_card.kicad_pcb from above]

Board: 4 copper layers, 24.0 x 50.0 mm, 55 parts (1 on the bottom side), 59 nets.

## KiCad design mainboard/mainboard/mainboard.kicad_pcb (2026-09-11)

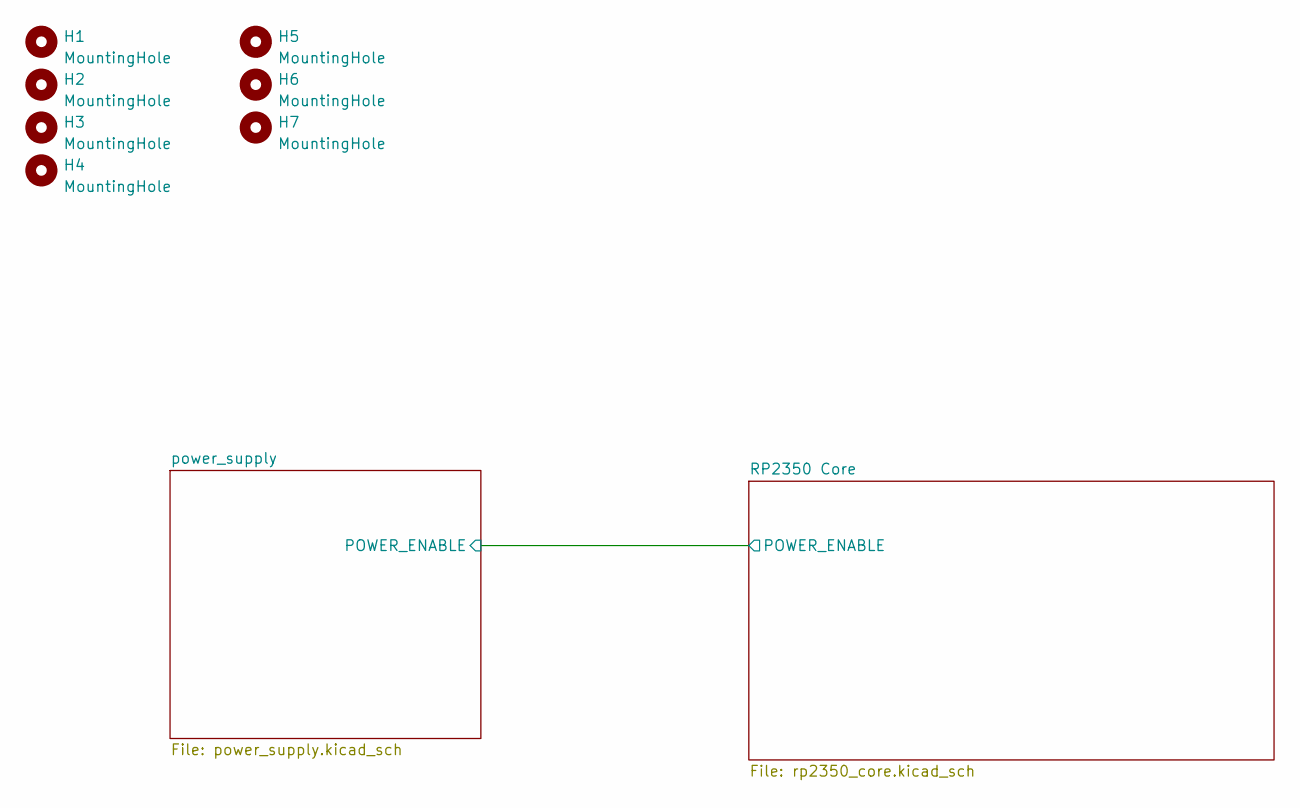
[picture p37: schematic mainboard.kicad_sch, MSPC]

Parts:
H1, H2, H3, H4: MountingHole; MountingHole_3.2mm_M3_DIN965
H5, H6, H7: MountingHole; MountingHole_2.2mm_M2_DIN965

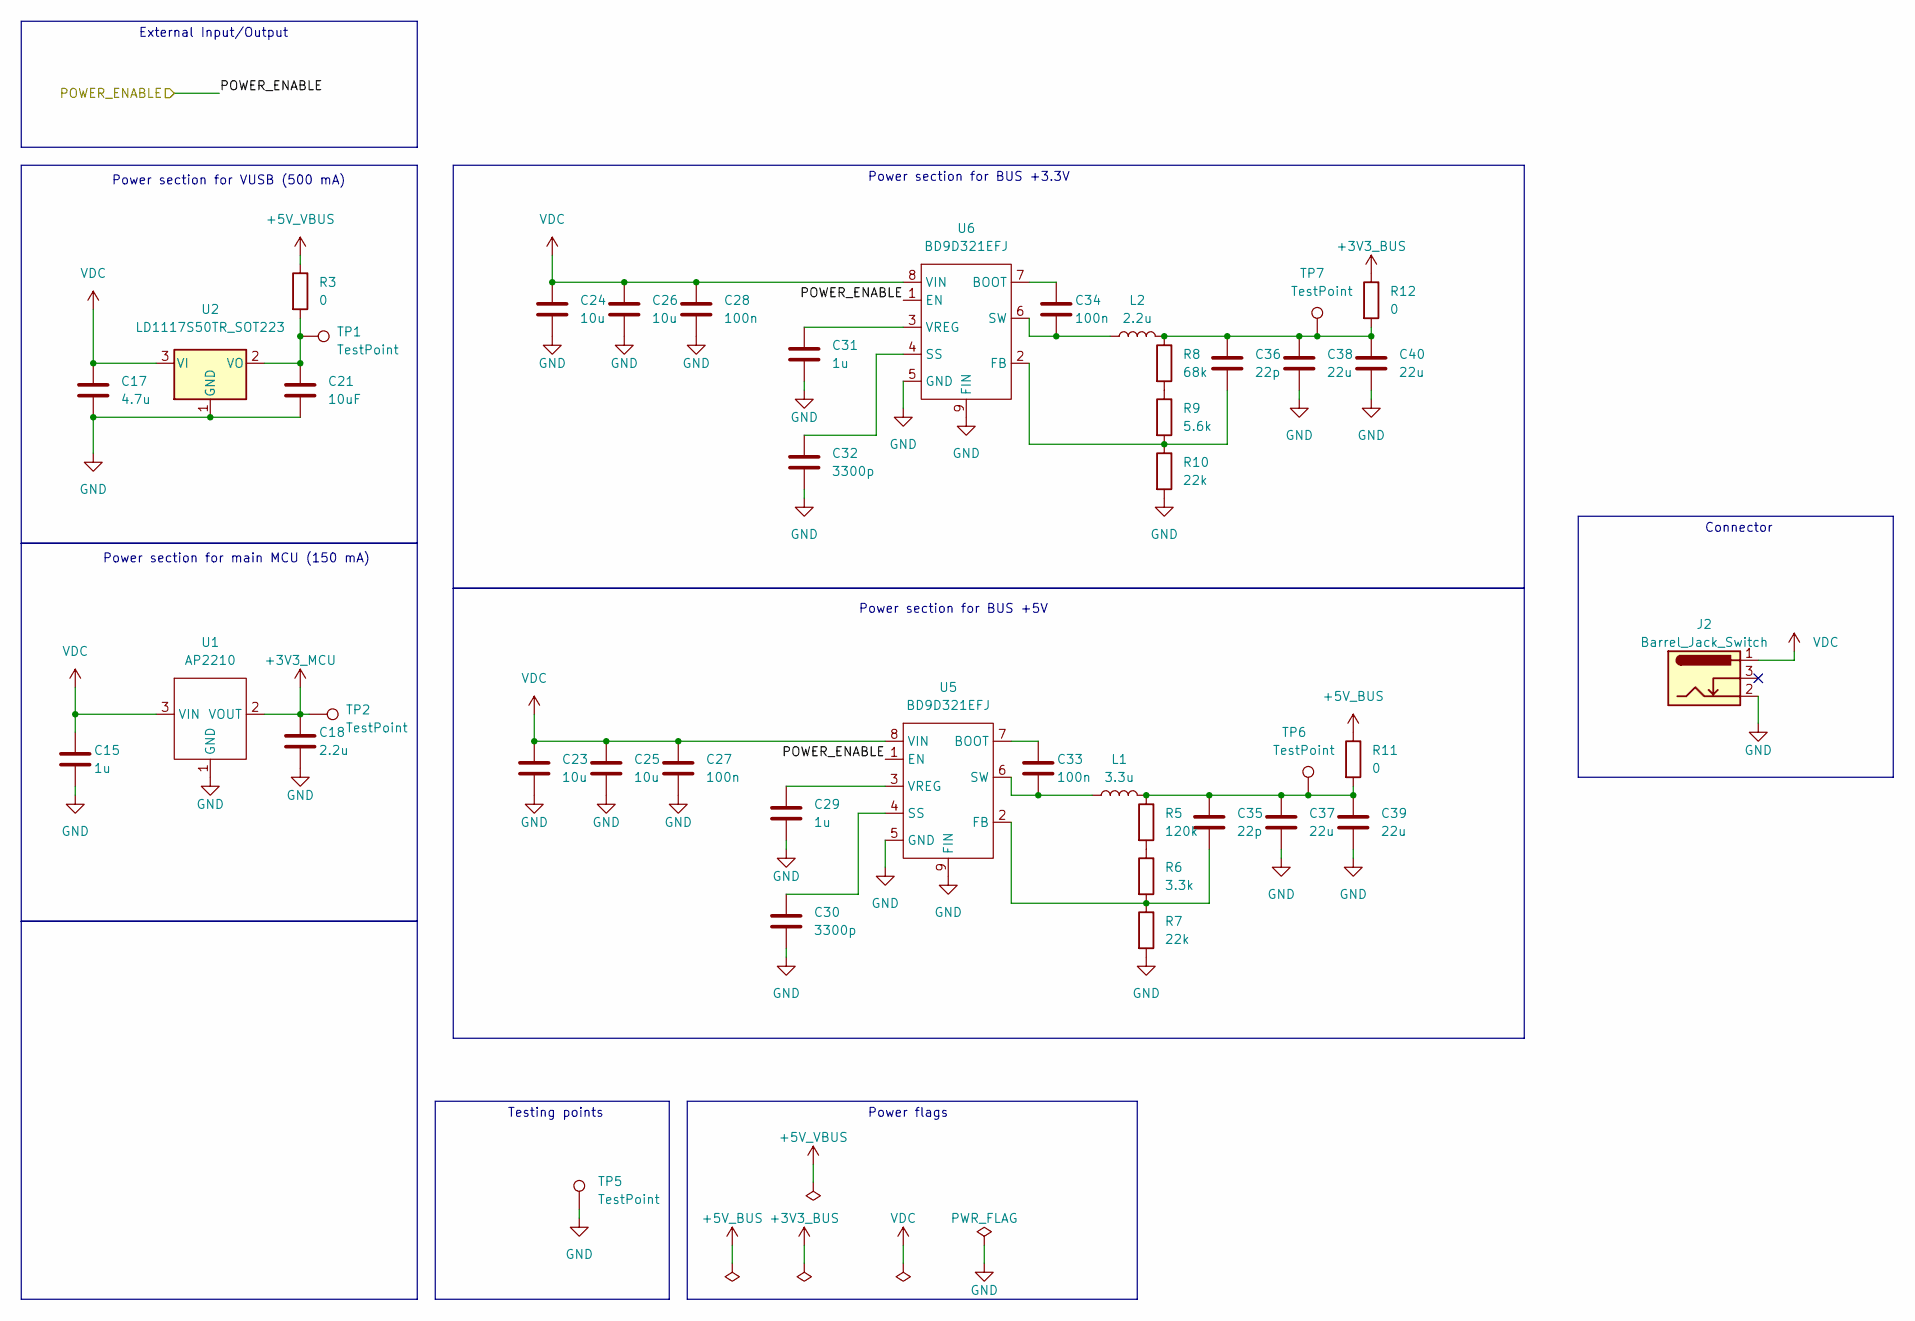
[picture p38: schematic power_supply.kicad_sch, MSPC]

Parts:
C15, C29, C31: 1u; C_0402_1005Metric_Pad0.74x0.62mm_HandSolder
C17: 4.7u; C_0402_1005Metric_Pad0.74x0.62mm_HandSolder
C18: 2.2u; C_0402_1005Metric_Pad0.74x0.62mm_HandSolder
C21: 10uF; C_0402_1005Metric_Pad0.74x0.62mm_HandSolder
C23, C24, C25, C26: 10u; C_1206_3216Metric_Pad1.33x1.80mm_HandSolder
C27, C28, C33, C34: 100n; C_0402_1005Metric_Pad0.74x0.62mm_HandSolder
C30, C32: 3300p; C_0402_1005Metric_Pad0.74x0.62mm_HandSolder
C35, C36: 22p; C_0402_1005Metric_Pad0.74x0.62mm_HandSolder
C37, C38, C39, C40: 22u; C_1206_3216Metric_Pad1.33x1.80mm_HandSolder
J2: Barrel_Jack_Switch; BarrelJack_GCT_DCJ200-10-A_Horizontal
L1: 3.3u; NRS8030
L2: 2.2u; IND_NR6028T4R7M
R3, R11, R12: 0; R_1206_3216Metric_Pad1.30x1.75mm_HandSolder
R5: 120k; R_0402_1005Metric_Pad0.72x0.64mm_HandSolder
R6: 3.3k; R_0402_1005Metric_Pad0.72x0.64mm_HandSolder
R7, R10: 22k; R_0402_1005Metric_Pad0.72x0.64mm_HandSolder
R8: 68k; R_0402_1005Metric_Pad0.72x0.64mm_HandSolder
R9: 5.6k; R_0402_1005Metric_Pad0.72x0.64mm_HandSolder
TP1, TP2, TP6, TP7: TestPoint; TestPoint_Pad_D1.5mm
TP5: TestPoint; TestPoint_THTPad_D1.5mm_Drill0.7mm
U1: AP2210; SOT-23-3
U2: LD1117S50TR_SOT223; SOT-223-3_TabPin2
U5, U6: BD9D321EFJ; SOIC127P600X100-9N

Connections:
+3V3_BUS: R12.1; also elsewhere on the board
+3V3_MCU: C18.1, TP2.1, U1.2 (VOUT); also elsewhere on the board
+5V_BUS: R11.1; also elsewhere on the board
+5V_VBUS: R3.1; also elsewhere on the board
/power_supply/POWER_ENABLE: U5.1 (EN), U6.1 (EN); also elsewhere on the board
GND: C15.2, C17.2, C18.2, C21.2, C23.2, C24.2, C25.2, C26.2, C27.2, C28.2, C29.2, C30.2, C31.2, C32.2, C37.2, C38.2, C39.2, C40.2, J2.2, R7.2, R10.2, TP5.1, U1.1 (GND), U2.1 (GND), U5.5 (GND), U5.9 (FIN), U6.5 (GND), U6.9 (FIN); also elsewhere on the board
unnamed: C35.1, C37.1, C39.1, L1.2, R5.1, R11.2, TP6.1
unnamed: C36.1, C38.1, C40.1, L2.2, R8.1, R12.2, TP7.1
unnamed: R5.2, R6.1
unnamed: R8.2, R9.1
unnamed: C21.1, R3.2, TP1.1, U2.2 (VO)
unnamed: C33.1, U5.7 (BOOT)
unnamed: C35.2, R6.2, R7.1, U5.2 (FB)
unnamed: C30.1, U5.4 (SS)
unnamed: C33.2, L1.1, U5.6 (SW)
unnamed: C29.1, U5.3 (VREG)
unnamed: C34.1, U6.7 (BOOT)
unnamed: C36.2, R9.2, R10.1, U6.2 (FB)
unnamed: C32.1, U6.4 (SS)
unnamed: C34.2, L2.1, U6.6 (SW)
unnamed: C31.1, U6.3 (VREG)
VDC: C15.1, C17.1, C23.1, C24.1, C25.1, C26.1, C27.1, C28.1, J2.1, U1.3 (VIN), U2.3 (VI), U5.8 (VIN), U6.8 (VIN)

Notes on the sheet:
External Input/Output
Power section for BUS +5V
Power section for main MCU (150 mA)
Connector
Power flags
Power section for VUSB (500 mA)
Testing points
Power section for BUS +3.3V

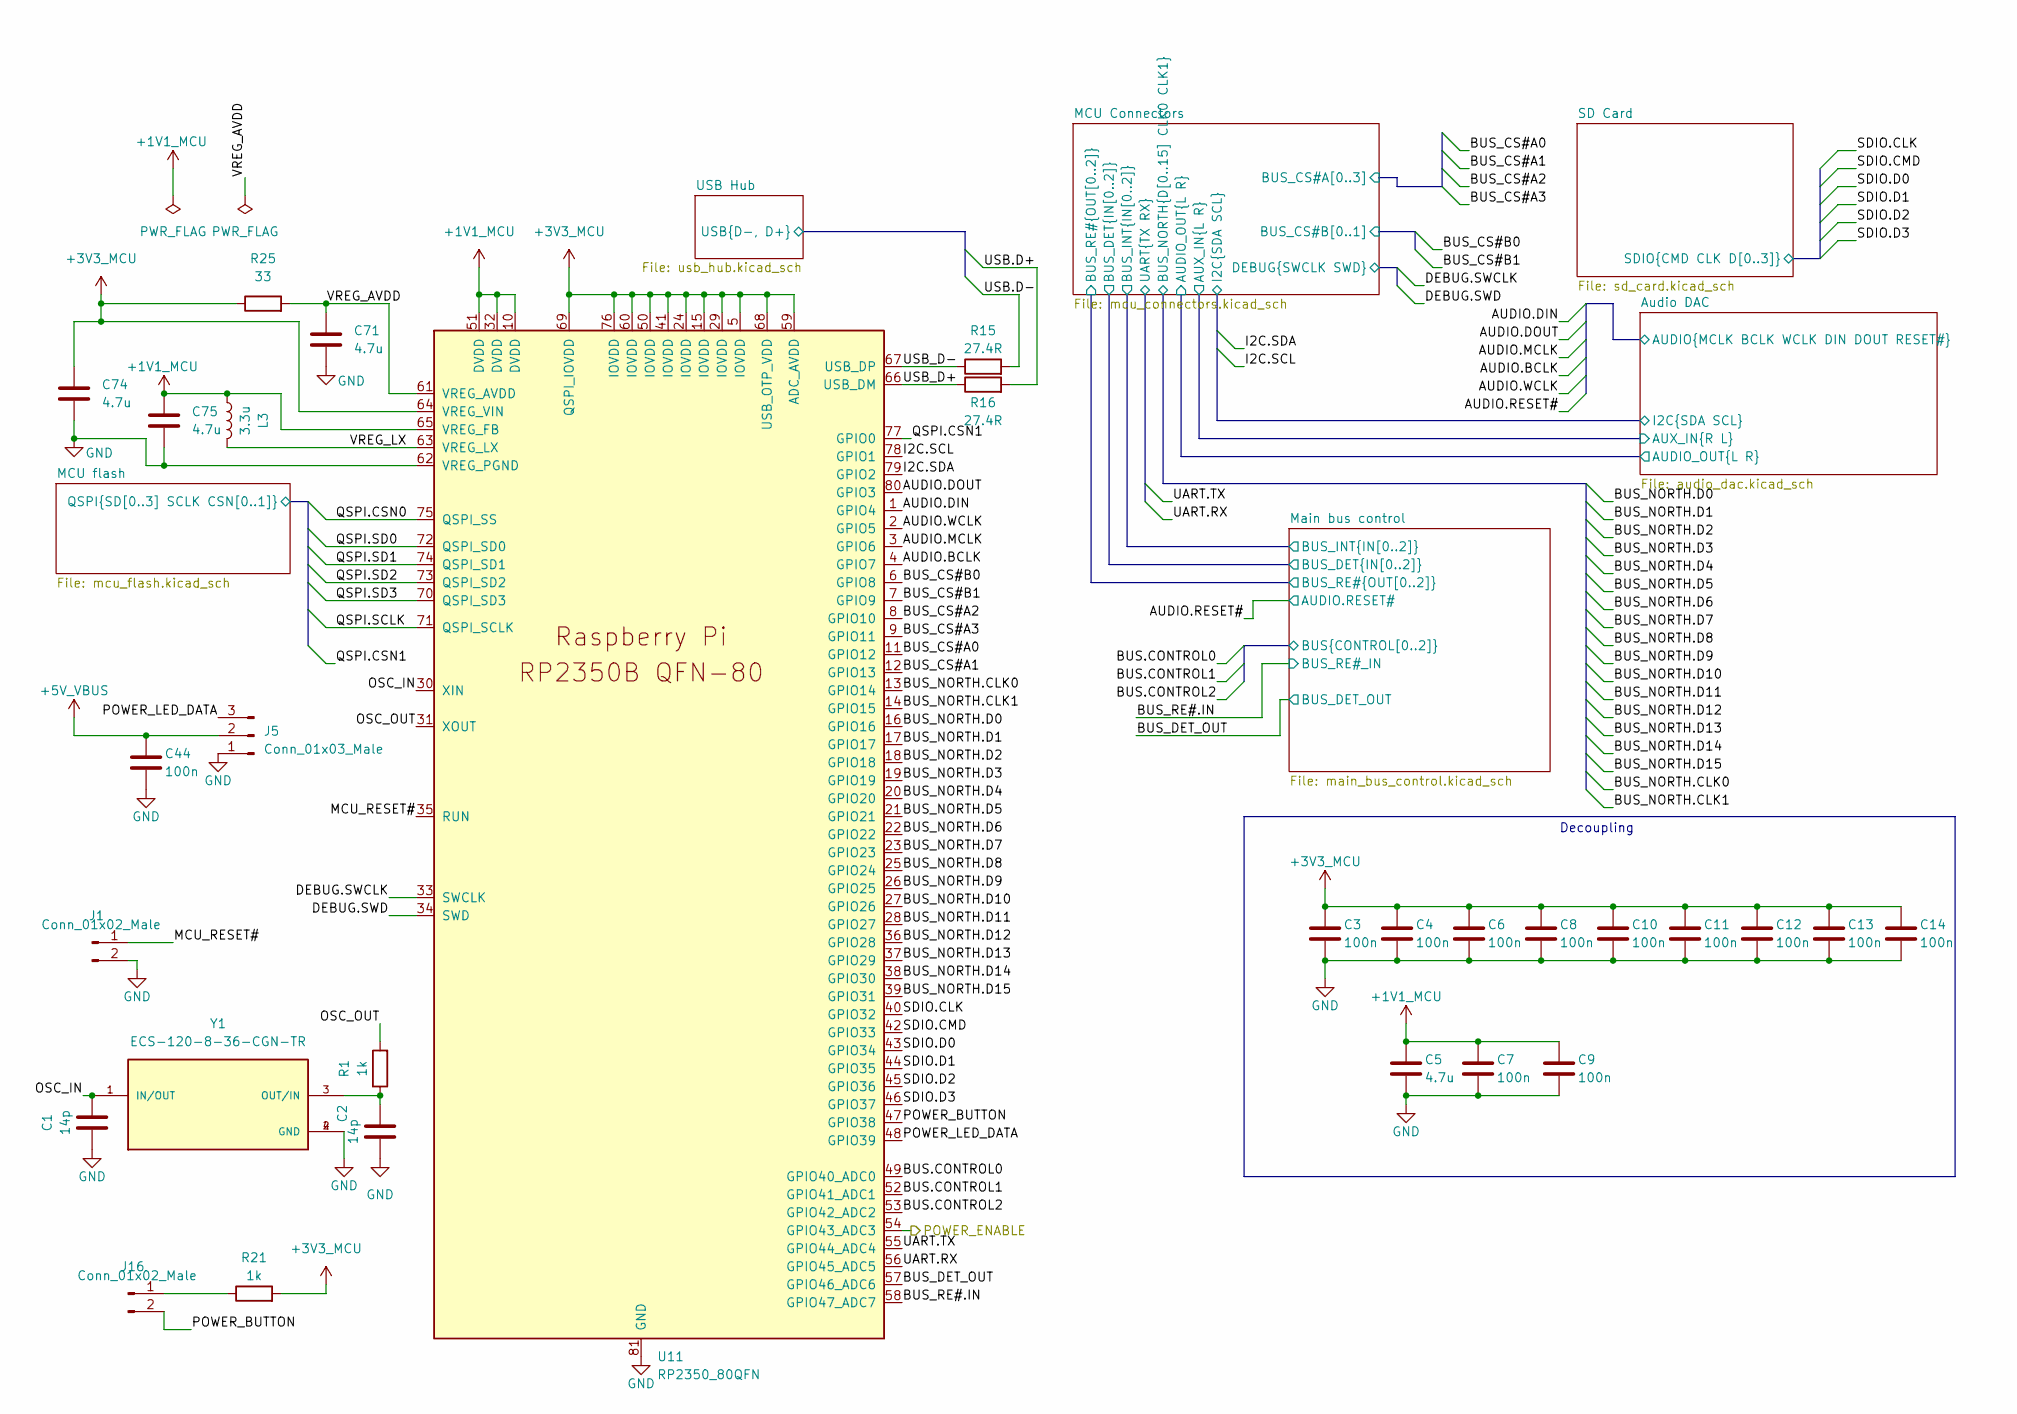
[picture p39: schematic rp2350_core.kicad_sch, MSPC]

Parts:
C1, C2: 14p; C_0402_1005Metric_Pad0.74x0.62mm_HandSolder
C3, C4, C6, C7, C8, C9, C10, C11, C12, C13, C14, C44: 100n; C_0402_1005Metric_Pad0.74x0.62mm_HandSolder
C5, C71, C74, C75: 4.7u; C_0402_1005Metric_Pad0.74x0.62mm_HandSolder
J1, J16: Conn_01x02_Male; PinHeader_1x02_P2.54mm_Vertical
J5: Conn_01x03_Male; PinHeader_1x03_P2.54mm_Vertical
L3: 3.3u; L_0805_2012Metric
R1, R21: 1k; R_0402_1005Metric_Pad0.72x0.64mm_HandSolder
R15, R16: 27.4R; R_0402_1005Metric_Pad0.72x0.64mm_HandSolder
R25: 33; R_0402_1005Metric_Pad0.72x0.64mm_HandSolder
U11: RP2350_80QFN; RP2350-QFN-80-1EP_10x10_P0.4mm_EP3.4x3.4mm_ThermalVias
Y1: ECS-120-8-36-CGN-TR; XTAL_ECS-120-8-36-CGN-TR; PARTREV 2017

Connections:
+1V1_MCU: C5.1, C7.1, C9.1, C75.1, L3.1, U11.10 (DVDD), U11.32 (DVDD), U11.51 (DVDD), U11.65 (VREG_FB)
+3V3_MCU: C3.1, C4.1, C6.1, C8.1, C10.1, C11.1, C12.1, C13.1, C14.1, C74.1, R21.2, R25.1, U11.5 (IOVDD), U11.15 (IOVDD), U11.24 (IOVDD), U11.29 (IOVDD), U11.41 (IOVDD), U11.50 (IOVDD), U11.59 (ADC_AVDD), U11.60 (IOVDD), U11.64 (VREG_VIN), U11.68 (USB_OTP_VDD), U11.69 (QSPI_IOVDD), U11.76 (IOVDD); also elsewhere on the board
+5V_VBUS: C44.1, J5.2; also elsewhere on the board
/RP2350 Core/Audio DAC/AUDIO.BCLK: U11.4 (GPIO7); also elsewhere on the board
/RP2350 Core/Audio DAC/AUDIO.DIN: U11.1 (GPIO4); also elsewhere on the board
/RP2350 Core/Audio DAC/AUDIO.DOUT: U11.80 (GPIO3); also elsewhere on the board
/RP2350 Core/Audio DAC/AUDIO.MCLK: U11.3 (GPIO6); also elsewhere on the board
/RP2350 Core/Audio DAC/AUDIO.WCLK: U11.2 (GPIO5); also elsewhere on the board
/RP2350 Core/Audio DAC/I2C.SCL: U11.78 (GPIO1); also elsewhere on the board
/RP2350 Core/Audio DAC/I2C.SDA: U11.79 (GPIO2); also elsewhere on the board
/RP2350 Core/BUS_DET_OUT: U11.57 (GPIO46_ADC6); also elsewhere on the board
/RP2350 Core/BUS_RE#.IN: U11.58 (GPIO47_ADC7); also elsewhere on the board
/RP2350 Core/MCU Connectors/BUS_CS#A0: U11.11 (GPIO12); also elsewhere on the board
/RP2350 Core/MCU Connectors/BUS_CS#A1: U11.12 (GPIO13); also elsewhere on the board
/RP2350 Core/MCU Connectors/BUS_CS#A2: U11.8 (GPIO10); also elsewhere on the board
/RP2350 Core/MCU Connectors/BUS_CS#A3: U11.9 (GPIO11); also elsewhere on the board
/RP2350 Core/MCU Connectors/BUS_CS#B0: U11.6 (GPIO8); also elsewhere on the board
/RP2350 Core/MCU Connectors/BUS_CS#B1: U11.7 (GPIO9); also elsewhere on the board
/RP2350 Core/MCU Connectors/BUS_NORTH.CLK0: U11.13 (GPIO14); also elsewhere on the board
/RP2350 Core/MCU Connectors/BUS_NORTH.CLK1: U11.14 (GPIO15); also elsewhere on the board
/RP2350 Core/MCU Connectors/BUS_NORTH.D0: U11.16 (GPIO16); also elsewhere on the board
/RP2350 Core/MCU Connectors/BUS_NORTH.D1: U11.17 (GPIO17); also elsewhere on the board
/RP2350 Core/MCU Connectors/BUS_NORTH.D2: U11.18 (GPIO18); also elsewhere on the board
/RP2350 Core/MCU Connectors/BUS_NORTH.D3: U11.19 (GPIO19); also elsewhere on the board
/RP2350 Core/MCU Connectors/BUS_NORTH.D4: U11.20 (GPIO20); also elsewhere on the board
/RP2350 Core/MCU Connectors/BUS_NORTH.D5: U11.21 (GPIO21); also elsewhere on the board
/RP2350 Core/MCU Connectors/BUS_NORTH.D6: U11.22 (GPIO22); also elsewhere on the board
/RP2350 Core/MCU Connectors/BUS_NORTH.D7: U11.23 (GPIO23); also elsewhere on the board
/RP2350 Core/MCU Connectors/BUS_NORTH.D8: U11.25 (GPIO24); also elsewhere on the board
/RP2350 Core/MCU Connectors/BUS_NORTH.D9: U11.26 (GPIO25); also elsewhere on the board
/RP2350 Core/MCU Connectors/BUS_NORTH.D10: U11.27 (GPIO26); also elsewhere on the board
/RP2350 Core/MCU Connectors/BUS_NORTH.D11: U11.28 (GPIO27); also elsewhere on the board
/RP2350 Core/MCU Connectors/BUS_NORTH.D12: U11.36 (GPIO28); also elsewhere on the board
/RP2350 Core/MCU Connectors/BUS_NORTH.D13: U11.37 (GPIO29); also elsewhere on the board
/RP2350 Core/MCU Connectors/BUS_NORTH.D14: U11.38 (GPIO30); also elsewhere on the board
/RP2350 Core/MCU Connectors/BUS_NORTH.D15: U11.39 (GPIO31); also elsewhere on the board
/RP2350 Core/MCU Connectors/DEBUG.SWCLK: U11.33 (SWCLK); also elsewhere on the board
/RP2350 Core/MCU Connectors/DEBUG.SWD: U11.34 (SWD); also elsewhere on the board
/RP2350 Core/MCU Connectors/UART.RX: U11.56 (GPIO45_ADC5); also elsewhere on the board
/RP2350 Core/MCU Connectors/UART.TX: U11.55 (GPIO44_ADC4); also elsewhere on the board
/RP2350 Core/MCU flash/QSPI.CSN0: U11.75 (QSPI_SS); also elsewhere on the board
/RP2350 Core/MCU flash/QSPI.CSN1: U11.77 (GPIO0); also elsewhere on the board
/RP2350 Core/MCU flash/QSPI.SCLK: U11.71 (QSPI_SCLK); also elsewhere on the board
/RP2350 Core/MCU flash/QSPI.SD0: U11.72 (QSPI_SD0); also elsewhere on the board
/RP2350 Core/MCU flash/QSPI.SD1: U11.74 (QSPI_SD1); also elsewhere on the board
/RP2350 Core/MCU flash/QSPI.SD2: U11.73 (QSPI_SD2); also elsewhere on the board
/RP2350 Core/MCU flash/QSPI.SD3: U11.70 (QSPI_SD3); also elsewhere on the board
/RP2350 Core/MCU_RESET#: J1.1, U11.35 (RUN)
/RP2350 Core/Main bus control/BUS.CONTROL0: U11.49 (GPIO40_ADC0); also elsewhere on the board
/RP2350 Core/Main bus control/BUS.CONTROL1: U11.52 (GPIO41_ADC1); also elsewhere on the board
/RP2350 Core/Main bus control/BUS.CONTROL2: U11.53 (GPIO42_ADC2); also elsewhere on the board
/RP2350 Core/OSC_IN: C1.1, U11.30 (XIN), Y1.1 (IN/OUT)
/RP2350 Core/OSC_OUT: R1.2, U11.31 (XOUT)
/RP2350 Core/POWER_BUTTON: J16.2, U11.47 (GPIO38)
/RP2350 Core/POWER_LED_DATA: J5.3, U11.48 (GPIO39)
/RP2350 Core/SD Card/SDIO.CLK: U11.40 (GPIO32); also elsewhere on the board
/RP2350 Core/SD Card/SDIO.CMD: U11.42 (GPIO33); also elsewhere on the board
/RP2350 Core/SD Card/SDIO.D0: U11.43 (GPIO34); also elsewhere on the board
/RP2350 Core/SD Card/SDIO.D1: U11.44 (GPIO35); also elsewhere on the board
/RP2350 Core/SD Card/SDIO.D2: U11.45 (GPIO36); also elsewhere on the board
/RP2350 Core/SD Card/SDIO.D3: U11.46 (GPIO37); also elsewhere on the board
/RP2350 Core/USB Hub/USB.D+: R16.2; also elsewhere on the board
/RP2350 Core/USB Hub/USB.D-: R15.2; also elsewhere on the board
/RP2350 Core/USB_D+: R16.1, U11.66 (USB_DM)
/RP2350 Core/USB_D-: R15.1, U11.67 (USB_DP)
/RP2350 Core/VREG_AVDD: C71.1, R25.2, U11.61 (VREG_AVDD)
/RP2350 Core/VREG_LX: L3.2, U11.63 (VREG_LX)
/power_supply/POWER_ENABLE: U11.54 (GPIO43_ADC3); also elsewhere on the board
GND: C1.2, C2.2, C3.2, C4.2, C5.2, C6.2, C7.2, C8.2, C9.2, C10.2, C11.2, C12.2, C13.2, C14.2, C44.2, C71.2, C74.2, C75.2, J1.2, J5.1, U11.62 (VREG_PGND), U11.81 (GND), Y1.2 (GND), Y1.4 (GND); also elsewhere on the board
unnamed: J16.1, R21.1
unnamed: C2.1, R1.1, Y1.3 (OUT/IN)

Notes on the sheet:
Decoupling

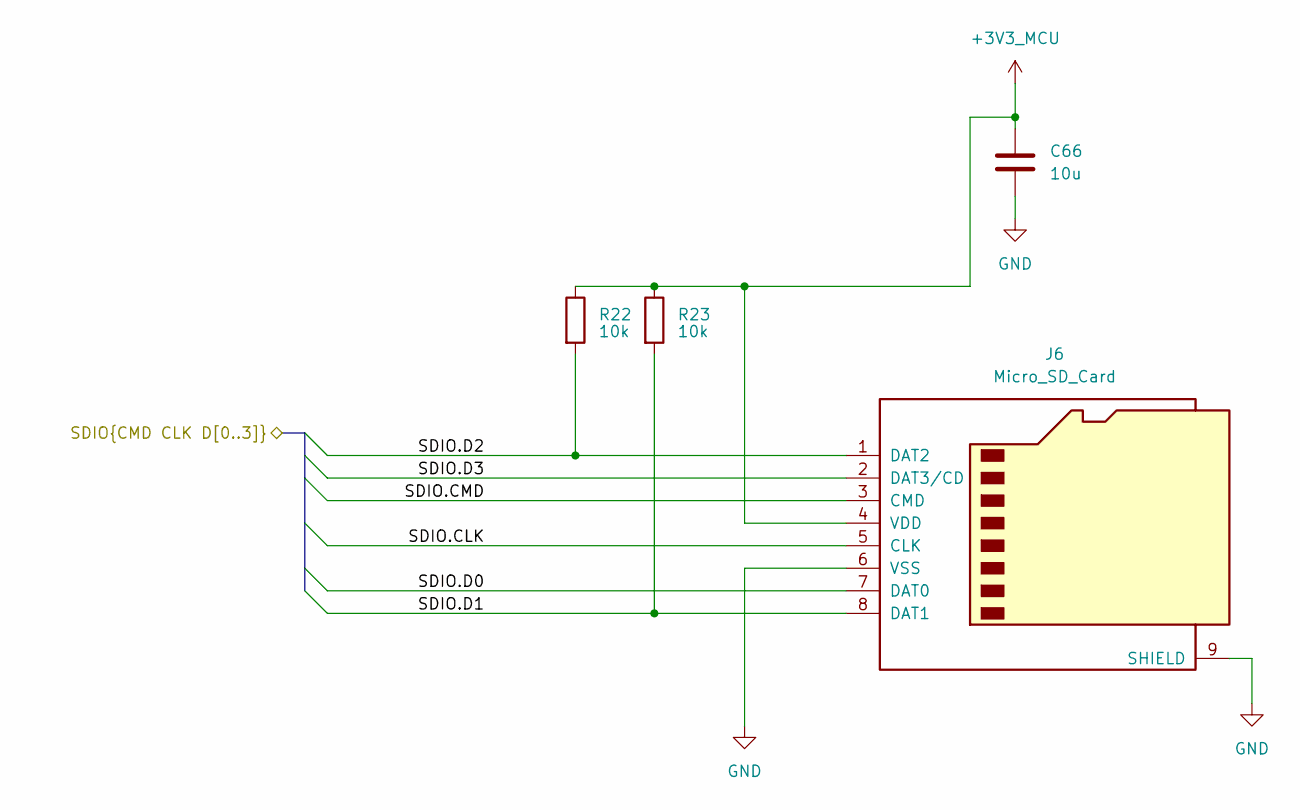
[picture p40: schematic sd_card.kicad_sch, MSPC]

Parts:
C66: 10u; C_0402_1005Metric_Pad0.74x0.62mm_HandSolder
J6: Micro_SD_Card; microSD_HC_Wuerth_693072010801
R22, R23: 10k; R_0402_1005Metric_Pad0.72x0.64mm_HandSolder

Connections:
+3V3_MCU: C66.1, J6.4 (VDD), R22.1, R23.1; also elsewhere on the board
/RP2350 Core/SD Card/SDIO.CLK: J6.5 (CLK); also elsewhere on the board
/RP2350 Core/SD Card/SDIO.CMD: J6.3 (CMD); also elsewhere on the board
/RP2350 Core/SD Card/SDIO.D0: J6.7 (DAT0); also elsewhere on the board
/RP2350 Core/SD Card/SDIO.D1: J6.8 (DAT1), R23.2; also elsewhere on the board
/RP2350 Core/SD Card/SDIO.D2: J6.1 (DAT2), R22.2; also elsewhere on the board
/RP2350 Core/SD Card/SDIO.D3: J6.2 (DAT3/CD); also elsewhere on the board
GND: C66.2, J6.6 (VSS), J6.9 (SHIELD); also elsewhere on the board


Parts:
C19, C20, C58, C59: 100n; C_0402_1005Metric_Pad0.74x0.62mm_HandSolder
C22, C60: 1u; C_0402_1005Metric_Pad0.74x0.62mm_HandSolder
C57: 10u; C_1206_3216Metric_Pad1.33x1.80mm_HandSolder
C61, C62: 47u; C_1206_3216Metric_Pad1.33x1.80mm_HandSolder
U4: TLV320DAC3203IRGET; VQFN-24-1EP_4x4mm_P0.5mm_EP2.45x2.45mm

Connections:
+3V3_BUS: C57.1, C59.1, U4.11 (LDOin), U4.24 (IOVDD); also elsewhere on the board
/RP2350 Core/Audio DAC/AUDIO.BCLK: U4.2 (BCLK); also elsewhere on the board
/RP2350 Core/Audio DAC/AUDIO.DIN: U4.4 (DIN/MFP1); also elsewhere on the board
/RP2350 Core/Audio DAC/AUDIO.DOUT: U4.5 (DOUT/MFP2); also elsewhere on the board
/RP2350 Core/Audio DAC/AUDIO.MCLK: U4.1 (MCLK); also elsewhere on the board
/RP2350 Core/Audio DAC/AUDIO.RESET#: U4.20 (RESET#); also elsewhere on the board
/RP2350 Core/Audio DAC/AUDIO.WCLK: U4.3 (WCLK); also elsewhere on the board
/RP2350 Core/Audio DAC/AUDIO_OUT.L: C62.2; also elsewhere on the board
/RP2350 Core/Audio DAC/AUDIO_OUT.R: C61.2; also elsewhere on the board
/RP2350 Core/Audio DAC/AUX_IN.L: C19.1; also elsewhere on the board
/RP2350 Core/Audio DAC/AUX_IN.R: C20.1; also elsewhere on the board
/RP2350 Core/Audio DAC/I2C.SCL: U4.7 (SCL/SS#); also elsewhere on the board
/RP2350 Core/Audio DAC/I2C.SDA: U4.8 (SDA/MOSI); also elsewhere on the board
GND: C22.2, C57.2, C58.2, C59.2, C60.2, U4.14 (AVSS), U4.19 (SPI_SELECT), U4.21 (DVSS), U4.23 (IOVSS); also elsewhere on the board
unnamed: C22.1, C58.1, U4.13 (AVDD), U4.22 (DVDD)
unnamed: C62.1, U4.12 (HPL)
unnamed: C61.1, U4.10 (HPR)
unnamed: C19.2, U4.15 (INL)
unnamed: C20.2, U4.16 (INR)
unnamed: C60.1, U4.17 (REF)


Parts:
C65, C72: 100n; C_0402_1005Metric_Pad0.74x0.62mm_HandSolder
R27, R31: 10k; R_0402_1005Metric_Pad0.72x0.64mm_HandSolder
U10, U12: W25Q128JVS; SOIC-8_5.23x5.23mm_P1.27mm

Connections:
+3V3_MCU: C65.1, C72.1, R27.2, R31.2, U10.8 (VCC), U12.8 (VCC); also elsewhere on the board
/RP2350 Core/MCU flash/QSPI.CSN0: R27.1, U12.1 (~CS); also elsewhere on the board
/RP2350 Core/MCU flash/QSPI.CSN1: R31.1, U10.1 (~CS); also elsewhere on the board
/RP2350 Core/MCU flash/QSPI.SCLK: U10.6 (CLK), U12.6 (CLK); also elsewhere on the board
/RP2350 Core/MCU flash/QSPI.SD0: U10.5 (DI(IO0)), U12.5 (DI(IO0)); also elsewhere on the board
/RP2350 Core/MCU flash/QSPI.SD1: U10.2 (DO(IO1)), U12.2 (DO(IO1)); also elsewhere on the board
/RP2350 Core/MCU flash/QSPI.SD2: U10.3 (IO2), U12.3 (IO2); also elsewhere on the board
/RP2350 Core/MCU flash/QSPI.SD3: U10.7 (IO3), U12.7 (IO3); also elsewhere on the board
GND: C65.2, C72.2, U10.4 (GND), U12.4 (GND); also elsewhere on the board


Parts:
J7: Conn_01x04_Female; PinHeader_1x04_P2.54mm_Vertical
J8, J11: Conn_01x03_Female; PinHeader_1x03_P2.54mm_Vertical
J9, J10: AudioJack4; Jack_3.5mm_PJ320D_Horizontal
J13: Connector A 16-bit; PinSocket_2x15_P1.27mm_Vertical_SMD
J14: Connector A 8-bit; PinSocket_2x10_P1.27mm_Vertical_SMD
J15: Connector B 8-bit; PinSocket_2x10_P1.27mm_Vertical_SMD

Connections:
+3V3_BUS: J7.1, J13.28, J14.18, J15.18; also elsewhere on the board
+5V_BUS: J13.25, J14.15, J15.15; also elsewhere on the board
/RP2350 Core/Audio DAC/AUDIO_OUT.L: J9.T; also elsewhere on the board
/RP2350 Core/Audio DAC/AUDIO_OUT.R: J9.R1; also elsewhere on the board
/RP2350 Core/Audio DAC/AUX_IN.L: J10.T; also elsewhere on the board
/RP2350 Core/Audio DAC/AUX_IN.R: J10.R1; also elsewhere on the board
/RP2350 Core/Audio DAC/I2C.SCL: J7.4; also elsewhere on the board
/RP2350 Core/Audio DAC/I2C.SDA: J7.3; also elsewhere on the board
/RP2350 Core/MCU Connectors/BUS_CS#A0: J13.22; also elsewhere on the board
/RP2350 Core/MCU Connectors/BUS_CS#A1: J13.20; also elsewhere on the board
/RP2350 Core/MCU Connectors/BUS_CS#A2: J14.12; also elsewhere on the board
/RP2350 Core/MCU Connectors/BUS_CS#A3: J14.10; also elsewhere on the board
/RP2350 Core/MCU Connectors/BUS_CS#B0: J15.12; also elsewhere on the board
/RP2350 Core/MCU Connectors/BUS_CS#B1: J15.10; also elsewhere on the board
/RP2350 Core/MCU Connectors/BUS_DET.IN0: J13.24; also elsewhere on the board
/RP2350 Core/MCU Connectors/BUS_DET.IN1: J14.14; also elsewhere on the board
/RP2350 Core/MCU Connectors/BUS_DET.IN2: J15.14; also elsewhere on the board
/RP2350 Core/MCU Connectors/BUS_INT.IN0: J13.23; also elsewhere on the board
/RP2350 Core/MCU Connectors/BUS_INT.IN1: J14.13; also elsewhere on the board
/RP2350 Core/MCU Connectors/BUS_INT.IN2: J15.13; also elsewhere on the board
/RP2350 Core/MCU Connectors/BUS_NORTH.CLK0: J15.9; also elsewhere on the board
/RP2350 Core/MCU Connectors/BUS_NORTH.CLK1: J13.19, J14.9; also elsewhere on the board
/RP2350 Core/MCU Connectors/BUS_NORTH.D0: J13.18, J15.8; also elsewhere on the board
/RP2350 Core/MCU Connectors/BUS_NORTH.D1: J13.17, J15.7; also elsewhere on the board
/RP2350 Core/MCU Connectors/BUS_NORTH.D2: J13.16, J15.6; also elsewhere on the board
/RP2350 Core/MCU Connectors/BUS_NORTH.D3: J13.15, J15.5; also elsewhere on the board
/RP2350 Core/MCU Connectors/BUS_NORTH.D4: J13.14, J15.4; also elsewhere on the board
/RP2350 Core/MCU Connectors/BUS_NORTH.D5: J13.13, J15.3; also elsewhere on the board
/RP2350 Core/MCU Connectors/BUS_NORTH.D6: J13.12, J15.2; also elsewhere on the board
/RP2350 Core/MCU Connectors/BUS_NORTH.D7: J13.11, J15.1; also elsewhere on the board
/RP2350 Core/MCU Connectors/BUS_NORTH.D8: J13.10, J14.8; also elsewhere on the board
/RP2350 Core/MCU Connectors/BUS_NORTH.D9: J13.9, J14.7; also elsewhere on the board
/RP2350 Core/MCU Connectors/BUS_NORTH.D10: J13.8, J14.6; also elsewhere on the board
/RP2350 Core/MCU Connectors/BUS_NORTH.D11: J13.7, J14.5; also elsewhere on the board
/RP2350 Core/MCU Connectors/BUS_NORTH.D12: J13.6, J14.4; also elsewhere on the board
/RP2350 Core/MCU Connectors/BUS_NORTH.D13: J13.5, J14.3; also elsewhere on the board
/RP2350 Core/MCU Connectors/BUS_NORTH.D14: J13.4, J14.2; also elsewhere on the board
/RP2350 Core/MCU Connectors/BUS_NORTH.D15: J13.3, J14.1; also elsewhere on the board
/RP2350 Core/MCU Connectors/BUS_RE#.OUT0: J13.26; also elsewhere on the board
/RP2350 Core/MCU Connectors/BUS_RE#.OUT1: J14.16; also elsewhere on the board
/RP2350 Core/MCU Connectors/BUS_RE#.OUT2: J15.16; also elsewhere on the board
/RP2350 Core/MCU Connectors/DEBUG.SWCLK: J8.1; also elsewhere on the board
/RP2350 Core/MCU Connectors/DEBUG.SWD: J8.3; also elsewhere on the board
/RP2350 Core/MCU Connectors/UART.RX: J11.3; also elsewhere on the board
/RP2350 Core/MCU Connectors/UART.TX: J11.1; also elsewhere on the board
GND: J7.2, J8.2, J9.R2, J9.S, J10.R2, J10.S, J11.2, J13.1, J13.2, J13.27, J13.30, J14.17, J14.20, J15.17, J15.20; also elsewhere on the board

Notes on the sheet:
External Input/Output

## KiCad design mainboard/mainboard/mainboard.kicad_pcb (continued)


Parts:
C63, C64: 100n; C_0402_1005Metric_Pad0.74x0.62mm_HandSolder
IC1: SN74HCS151PWR; TSSOP-16_4.4x5mm_P0.65mm; Manufacturer_Part_Number SN74HCS151PWR; Mouser Part Number 595-SN74HCS151PWR
R4, R26, R30, R33, R34, R35: 10k; R_0402_1005Metric_Pad0.72x0.64mm_HandSolder
U9: SN74LVC139APWR; TSSOP-16_4.4x5mm_P0.65mm

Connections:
+3V3_BUS: C63.1, C64.1, IC1.16 (VCC), U9.16 (VCC); also elsewhere on the board
/RP2350 Core/Audio DAC/AUDIO.RESET#: U9.9 (2Y3); also elsewhere on the board
/RP2350 Core/BUS_DET_OUT: IC1.5 (Y); also elsewhere on the board
/RP2350 Core/BUS_RE#.IN: U9.15 (2G#); also elsewhere on the board
/RP2350 Core/MCU Connectors/BUS_DET.IN0: IC1.3 (D1), R35.2; also elsewhere on the board
/RP2350 Core/MCU Connectors/BUS_DET.IN1: IC1.12 (D7), R34.2; also elsewhere on the board
/RP2350 Core/MCU Connectors/BUS_DET.IN2: IC1.14 (D5), R33.2; also elsewhere on the board
/RP2350 Core/MCU Connectors/BUS_INT.IN0: IC1.4 (D0), R30.2; also elsewhere on the board
/RP2350 Core/MCU Connectors/BUS_INT.IN1: IC1.13 (D6), R26.2; also elsewhere on the board
/RP2350 Core/MCU Connectors/BUS_INT.IN2: IC1.15 (D4), R4.2; also elsewhere on the board
/RP2350 Core/MCU Connectors/BUS_RE#.OUT0: U9.10 (2Y2); also elsewhere on the board
/RP2350 Core/MCU Connectors/BUS_RE#.OUT1: U9.11 (2Y1); also elsewhere on the board
/RP2350 Core/MCU Connectors/BUS_RE#.OUT2: U9.12 (2Y0); also elsewhere on the board
/RP2350 Core/Main bus control/BUS.CONTROL0: IC1.11 (A), U9.14 (2A); also elsewhere on the board
/RP2350 Core/Main bus control/BUS.CONTROL1: IC1.10 (B), U9.13 (2B); also elsewhere on the board
/RP2350 Core/Main bus control/BUS.CONTROL2: IC1.9 (C), U9.1 (1G#); also elsewhere on the board
GND: C63.2, C64.2, IC1.7 (~G), IC1.8 (GND), R4.1, R26.1, R30.1, R33.1, R34.1, R35.1, U9.2 (1A), U9.3 (1B), U9.8 (GND); also elsewhere on the board

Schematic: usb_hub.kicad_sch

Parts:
C41, C43: 4.7u; C_0402_1005Metric_Pad0.74x0.62mm_HandSolder
C42: 100n; C_0402_1005Metric_Pad0.74x0.62mm_HandSolder
D1, D2, D3, D4, D5, D6, D7, D8, D9, D10: LESD5D5.0CT1G; TVS_LESD5D5.0CT1G; PARTREV O
J3, J4: USB_A_Wuerth_61400826021_Horizontal_Stacked
R19: 100k; R_0402_1005Metric_Pad0.72x0.64mm_HandSolder
R20: 4.7; R_0402_1005Metric_Pad0.72x0.64mm_HandSolder
U7: hs8836a; SOP-16_3.9x9.9mm_P1.27mm

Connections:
+3V3_USB_HUB: C41.1, C42.1, U7.12 (DCP), U7.14 (V33)
+5V_VBUS: D9.1, D10.1, J3.1 (VBUS1), J3.5 (VBUS2), J4.1 (VBUS1), J4.5 (VBUS2), R20.2; also elsewhere on the board
/RP2350 Core/USB Hub/D1+: D8.1, J3.3 (D1+), U7.8 (DP1)
/RP2350 Core/USB Hub/D1-: D6.1, J3.2 (D1-), U7.7 (DM1)
/RP2350 Core/USB Hub/D2+: D4.1, J3.7 (D2+), U7.6 (DP2)
/RP2350 Core/USB Hub/D2-: D2.1, J3.6 (D2-), U7.5 (DM2)
/RP2350 Core/USB Hub/D3+: D7.1, J4.3 (D1+), U7.4 (DP3)
/RP2350 Core/USB Hub/D3-: D5.1, J4.2 (D1-), U7.3 (DM3)
/RP2350 Core/USB Hub/D4+: D3.1, J4.7 (D2+), U7.2 (DP4)
/RP2350 Core/USB Hub/D4-: D1.1, J4.6 (D2-), U7.1 (DM4)
/RP2350 Core/USB Hub/USB.D+: U7.10 (DM); also elsewhere on the board
/RP2350 Core/USB Hub/USB.D-: U7.11 (DP); also elsewhere on the board
GND: C41.2, C42.2, C43.2, D1.2, D2.2, D3.2, D4.2, D5.2, D6.2, D7.2, D8.2, D9.2, D10.2, J3.4 (GND1), J3.8 (GND2), J3.9 (Shield), J4.4 (GND1), J4.8 (GND2), J4.9 (Shield), R19.1, U7.16 (GND); also elsewhere on the board
unnamed: R19.2, U7.9 (REF)
unnamed: C43.1, R20.1, U7.13 (VCC)



Board: 4 copper layers, 100.0 x 100.0 mm, 135 parts (17 on the bottom side), 120 nets.

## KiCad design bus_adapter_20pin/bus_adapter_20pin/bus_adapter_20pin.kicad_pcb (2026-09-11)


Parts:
J2, J4: Conn_01x10_Pin; PinHeader_1x10_P2.54mm_Vertical
J3: Conn_02x10_Odd_Even; PinHeader_2x10_P1.27mm_Vertical_SMD

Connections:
GND: J2.9, J3.17, J3.20, J4.10
unnamed: J2.1, J3.1
unnamed: J2.2, J3.3
unnamed: J2.3, J3.5
unnamed: J2.4, J3.7
unnamed: J2.5, J3.9
unnamed: J2.6, J3.11
unnamed: J2.7, J3.13
unnamed: J2.8, J3.15
unnamed: J2.10, J3.19
unnamed: J3.2, J4.1
unnamed: J3.4, J4.2
unnamed: J3.6, J4.3
unnamed: J3.8, J4.4
unnamed: J3.10, J4.5
unnamed: J3.12, J4.6
unnamed: J3.14, J4.7
unnamed: J3.16, J4.8
unnamed: J3.18, J4.9


Board: 2 copper layers, 24.0 x 50.0 mm, 3 parts (1 on the bottom side), 19 nets.

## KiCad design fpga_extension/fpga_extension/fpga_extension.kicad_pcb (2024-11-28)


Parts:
U1: LFE5UM-85F-7BG381x; Lattice_caBGA-381_17.0x17.0mm_Layout20x20_P0.8mm_Ball0.4mm_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

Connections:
+3V3: U1.F9 (VCCIO0), U1.F10 (VCCIO0), U1.F11 (VCCIO1), U1.F12 (VCCIO1), U1.L6 (VCCIO6), U1.L7 (VCCIO6), U1.M6 (VCCIO6); also elsewhere on the board
/Connector/BUS.CLK: U1.B9 (PT58A); also elsewhere on the board
/Connector/BUS.CS#A1: U1.A9 (PT60A); also elsewhere on the board
/Connector/BUS.D0: U1.A12 (PT76A); also elsewhere on the board
/Connector/BUS.D1: U1.B12 (PT71A); also elsewhere on the board
/Connector/BUS.D2: U1.B13 (PT78A); also elsewhere on the board
/Connector/BUS.D3: U1.A13 (PT76B); also elsewhere on the board
/Connector/BUS.D4: U1.A15 (PT103A); also elsewhere on the board
/Connector/BUS.D5: U1.A14 (PT83A); also elsewhere on the board
/Connector/BUS.D6: U1.A16 (PT110A); also elsewhere on the board
/Connector/BUS.D7: U1.B15 (PT105A); also elsewhere on the board
/Connector/BUS.D8: U1.A17 (PT116A); also elsewhere on the board
/Connector/BUS.D9: U1.B16 (PT110B); also elsewhere on the board
/Connector/BUS.D10: U1.A18 (PT119A); also elsewhere on the board
/Connector/BUS.D11: U1.B17 (PT114A); also elsewhere on the board
/Connector/BUS.D12: U1.A19 (PT121A); also elsewhere on the board
/Connector/BUS.D13: U1.B18 (PT116B); also elsewhere on the board
/Connector/BUS.D14: U1.B20 (PT121B); also elsewhere on the board
/Connector/BUS.D15: U1.B19 (PT119B); also elsewhere on the board
/Connector/BUS.INT: U1.B8 (PT15B); also elsewhere on the board
/JTAG/UART.RX: U1.K1 (PL53D); also elsewhere on the board
/JTAG/UART.TX: U1.L1 (PL89C); also elsewhere on the board


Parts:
C2: 100n; C_0402_1005Metric_Pad0.74x0.62mm_HandSolder
R1, R2, R3, R4, R5, R6, R8, R10, R12, R13, R14: 4.7k; R_0402_1005Metric_Pad0.72x0.64mm_HandSolder
R7, R11, R15: DNF; R_0402_1005Metric_Pad0.72x0.64mm_HandSolder
R9: 1k; R_0402_1005Metric_Pad0.72x0.64mm_HandSolder
U1: LFE5UM-85F-7BG381x; Lattice_caBGA-381_17.0x17.0mm_Layout20x20_P0.8mm_Ball0.4mm_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
U2: W25Q128JVS; SOIC-8_5.23x5.23mm_P1.27mm

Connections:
+3V3: C2.1, R2.1, R3.1, R4.1, R5.1, R6.1, R8.1, R9.1, R10.1, R12.1, R13.1, R14.1, U1.P9 (VCCIO8), U1.P10 (VCCIO8), U2.8 (VCC); also elsewhere on the board
/FPGA Configuration/CFG.CFG0: R13.2, R15.1, U1.U4 (CFG_0); also elsewhere on the board
/FPGA Configuration/CFG.CFG1: R10.2, R11.1, U1.T4 (CFG_1); also elsewhere on the board
/FPGA Configuration/CFG.CFG2: R6.2, R7.1, U1.R4 (CFG_2); also elsewhere on the board
/FPGA Configuration/CFG.CLK: R9.2, U1.U3 (CCLK), U2.6 (CLK)
/FPGA Configuration/CFG.CSS: R2.2, U1.R2 (PB15A), U2.1 (~CS)
/FPGA Configuration/CFG.DONE: R8.2, U1.Y3 (DONE); also elsewhere on the board
/FPGA Configuration/CFG.INIT#: R12.2, U1.V3 (~INIT); also elsewhere on the board
/FPGA Configuration/CFG.IO2: U1.Y2 (PB9B), U2.3 (IO2)
/FPGA Configuration/CFG.IO3: U1.W1 (PB9A), U2.7 (IO3)
/FPGA Configuration/CFG.MISO: U1.V2 (PB11A), U2.2 (DO(IO1))
/FPGA Configuration/CFG.MOSI: U1.W2 (PB11B), U2.5 (DI(IO0))
/FPGA Configuration/CFG.PROGRAM#: R14.2, U1.W3 (~PROGRAM); also elsewhere on the board
/FPGA Configuration/JTAG.TCK: R1.1, U1.T5 (TCK); also elsewhere on the board
/FPGA Configuration/JTAG.TDI: R3.2, U1.R5 (TDI); also elsewhere on the board
/FPGA Configuration/JTAG.TDO: R4.2, U1.V4 (TDO); also elsewhere on the board
/FPGA Configuration/JTAG.TMS: R5.2, U1.U5 (TMS); also elsewhere on the board
GND: C2.2, R1.2, R7.2, R11.2, R15.2, U2.4 (GND); also elsewhere on the board

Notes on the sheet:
Select correct configuration on PCB


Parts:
C41: 100n; C_0402_1005Metric_Pad0.74x0.62mm_HandSolder
C42: 4.7u; C_0402_1005Metric_Pad0.74x0.62mm_HandSolder
D3, D4, D5: LED; LED_0402_1005Metric_Pad0.77x0.64mm_HandSolder
R29, R30, R31: 600; R_0402_1005Metric_Pad0.72x0.64mm_HandSolder
R32: 22; R_0402_1005Metric_Pad0.72x0.64mm_HandSolder
U1: LFE5UM-85F-7BG381x; Lattice_caBGA-381_17.0x17.0mm_Layout20x20_P0.8mm_Ball0.4mm_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
X1: SG-8002CE; Oscillator_SMD_SeikoEpson_SG210-4Pin_2.5x2.0mm

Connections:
+3V3: C41.1, C42.1, U1.H14 (VCCIO2), U1.H15 (VCCIO2), U1.J15 (VCCIO2), X1.1 (OE), X1.4 (Vcc); also elsewhere on the board
/LEDs/REF_CLK: R32.2, U1.G19 (PR41A)
GND: C41.2, C42.2, R29.2, R30.2, R31.2, X1.2 (GND); also elsewhere on the board
unnamed: D3.2 (A), U1.E20 (PR38A)
unnamed: D3.1 (K), R29.1
unnamed: D4.2 (A), U1.D20 (PR35C)
unnamed: D4.1 (K), R30.1
unnamed: D5.2 (A), U1.C20 (PR35A)
unnamed: D5.1 (K), R31.1
unnamed: R32.1, X1.3 (OUT)


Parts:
C1, C3, C4, C17, C18, C19, C21, C43, C44, C45, C46, C47, C48, C49, C50, C51, C53, C54, C55, C56, C57, C58, C59: 100n; C_0402_1005Metric_Pad0.74x0.62mm_HandSolder
C9, C10, C11, C12, C13, C20, C22, C23: 4.7u; C_0402_1005Metric_Pad0.74x0.62mm_HandSolder
C14, C15: 10u; C_0603_1608Metric_Pad1.08x0.95mm_HandSolder
C16: 6.8p; C_0402_1005Metric_Pad0.74x0.62mm_HandSolder
C60, C61: 1u; C_0402_1005Metric_Pad0.74x0.62mm_HandSolder
D1: D_Schottky; D_SOD-323_HandSoldering
FB1, FB2, FB3: FerriteBead; L_0805_2012Metric_Pad1.05x1.20mm_HandSolder
L1: 2.2u; L_0805_2012Metric_Pad1.15x1.40mm_HandSolder
Q1: TSM2301ACX; SOT-23W_Handsoldering
R16: 100k; R_0402_1005Metric_Pad0.72x0.64mm_HandSolder
R17: 120k; R_0402_1005Metric_Pad0.72x0.64mm_HandSolder
R18: 10k; R_0402_1005Metric_Pad0.72x0.64mm_HandSolder
U1: LFE5UM-85F-7BG381x; Lattice_caBGA-381_17.0x17.0mm_Layout20x20_P0.8mm_Ball0.4mm_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
U4: TLV75525PDBV; SOT-23-5
U5: TLV75518PDBV; SOT-23-5
U6: TLV62569DRL; SOT-563

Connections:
+1V1: C14.1, C15.1, C16.1, FB2.1, FB3.1, L1.2, R16.1
+1V8: C3.1, C4.1, C13.1, C59.1, C60.1, U5.5 (OUT); also elsewhere on the board
+2V5: C12.1, C17.2, C56.1, C57.1, C58.1, U1.F6 (VCCAUX), U1.F15 (VCCAUX), U1.P6 (VCCAUX), U1.P15 (VCCAUX), U4.5 (OUT)
+3V3: C1.1, C43.1, C44.1, C45.1, C46.1, C47.1, C48.1, C49.1, C50.1, C51.1, C53.1, C54.1, C55.1, C61.1, FB1.1; also elsewhere on the board
+3V3_BUS: FB1.2; also elsewhere on the board
+5V: C9.1, C10.1, C11.1, D1.1 (K), Q1.2 (S), U4.1 (IN), U4.3 (EN), U5.1 (IN), U5.3 (EN), U6.3 (VIN), U6.5 (EN)
+5V_BUS: Q1.3 (D); also elsewhere on the board
+5V_USB: D1.2 (A), Q1.1 (G), R18.1; also elsewhere on the board
GND: C1.2, C3.2, C4.2, C9.2, C10.2, C11.2, C12.2, C13.2, C14.2, C15.2, C17.1, C18.2, C19.2, C20.2, C21.2, C22.2, C23.2, C43.2, C44.2, C45.2, C46.2, C47.2, C48.2, C49.2, C50.2, C51.2, C53.2, C54.2, C55.2, C56.2, C57.2, C58.2, C59.2, C60.2, C61.2, R17.2, R18.2, U1.B7 (GND), U1.B14 (GND), U1.C19 (GND), U1.D4 (GND), U1.F7 (GND), U1.F8 (GND), U1.F13 (GND), U1.F14 (GND), U1.G4 (GND), U1.G6 (GND), U1.G7 (GND), U1.G8 (GND), U1.G9 (GND), U1.G10 (GND), U1.G11 (GND), U1.G12 (GND), U1.G13 (GND), U1.G14 (GND), U1.G15 (GND), U1.G17 (GND), U1.H19 (GND), U1.J2 (GND), U1.J7 (GND), U1.J9 (GND), U1.J10 (GND), U1.J11 (GND), U1.J12 (GND), U1.J14 (GND), U1.K6 (GND), U1.K7 (GND), U1.K9 (GND), U1.K10 (GND), U1.K11 (GND), U1.K12 (GND), U1.K14 (GND), U1.K15 (GND), U1.L9 (GND), U1.L10 (GND), U1.L11 (GND), U1.L12 (GND), U1.M2 (GND), U1.M7 (GND), U1.M9 (GND), U1.M10 (GND), U1.M11 (GND), U1.M12 (GND), U1.M14 (GND), U1.M16 (GND), U1.N6 (GND), U1.N7 (GND), U1.N14 (GND), U1.N15 (GND), U1.P7 (GND), U1.P8 (GND), U1.P11 (GND), U1.P12 (GND), U1.P13 (GND), U1.P14 (GND), U1.R19 (GND), U1.U7 (GND), U1.U8 (GND), U1.U9 (GND), U1.U10 (GND), U1.U11 (GND), U1.U12 (GND), U1.U13 (GND), U1.U14 (GND), U1.V5 (GND), U1.V6 (GND), U1.V7 (GND), U1.V8 (GND), U1.V9 (GND), U1.V12 (GND), U1.V13 (GND), U1.V14 (GND), U1.V15 (GND), U1.V16 (GND), U1.V19 (GND), U1.V20 (GND), U1.W6 (GND), U1.W7 (GND), U1.W12 (GND), U1.W15 (GND), U1.W16 (GND), U1.W19 (GND), U4.2 (GND), U5.2 (GND), U6.2 (GND); also elsewhere on the board
unnamed: C18.1, C20.1, FB2.2, U1.H8 (VCC), U1.H9 (VCC), U1.H10 (VCC), U1.H11 (VCC), U1.H12 (VCC), U1.H13 (VCC), U1.J8 (VCC), U1.J13 (VCC), U1.K8 (VCC), U1.K13 (VCC), U1.L8 (VCC), U1.L13 (VCC), U1.M8 (VCC), U1.M13 (VCC), U1.N8 (VCC), U1.N9 (VCC), U1.N10 (VCC), U1.N11 (VCC), U1.N12 (VCC), U1.N13 (VCC)
unnamed: C19.1, C21.1, C22.1, C23.1, FB3.2, U1.T6 (VCCA0), U1.T15 (VCCA1), U1.U6 (VCCA0), U1.U15 (VCCA1)
unnamed: C16.2, R16.2, R17.1, U6.1 (FB)
unnamed: L1.1, U6.4 (SW)

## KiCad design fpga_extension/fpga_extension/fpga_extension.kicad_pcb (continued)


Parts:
C24: 4.7u; C_0402_1005Metric_Pad0.74x0.62mm_HandSolder
C25, C28: 14p; C_0402_1005Metric_Pad0.74x0.62mm_HandSolder
C26, C27, C29, C31, C32, C33, C34, C35, C36, C37, C52, C62: 100n; C_0402_1005Metric_Pad0.74x0.62mm_HandSolder
C30, C38: 1u; C_0402_1005Metric_Pad0.74x0.62mm_HandSolder
D2: LED; LED_0402_1005Metric_Pad0.77x0.64mm_HandSolder
F1: Fuse; Fuse_0603_1608Metric_Pad1.05x0.95mm_HandSolder
J1: USB_C_Receptacle_USB2.0_16P; USB_C_Receptacle_HRO_TYPE-C-31-M-12
J2: Conn_01x03; PinHeader_1x03_P2.54mm_Vertical
R19, R20: 5.1k; R_0402_1005Metric_Pad0.72x0.64mm_HandSolder
R21: 10k; R_0402_1005Metric_Pad0.72x0.64mm_HandSolder
R22, R23: 27.4; R_0402_1005Metric_Pad0.72x0.64mm_HandSolder
R24: 1k; R_0402_1005Metric_Pad0.72x0.64mm_HandSolder
R25: 600; R_0402_1005Metric_Pad0.72x0.64mm_HandSolder
U7: USBLC6-2P6; SOT-666
U8: W25Q128JVS; SOIC-8_5.23x5.23mm_P1.27mm
U9: RP2040; QFN-56-1EP_7x7mm_P0.4mm_EP3.2x3.2mm
Y1: ECS-120-8-36-CGN-TR; XTAL_ECS-120-8-36-CGN-TR; PARTREV 2017

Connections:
+3V3: C26.1, C31.1, C32.1, C33.1, C34.1, C35.1, C36.1, C37.1, C38.1, C52.1, R21.2, U8.8 (VCC), U9.1 (IOVDD), U9.10 (IOVDD), U9.22 (IOVDD), U9.33 (IOVDD), U9.42 (IOVDD), U9.43 (ADC_AVDD), U9.44 (VREG_IN), U9.48 (USB_VDD), U9.49 (IOVDD); also elsewhere on the board
+5V_USB: F1.2; also elsewhere on the board
/Connector/BUS.CLK: U9.31 (GPIO20); also elsewhere on the board
/Connector/BUS.CS#A0: U9.30 (GPIO19); also elsewhere on the board
/Connector/BUS.D0: U9.32 (GPIO21); also elsewhere on the board
/Connector/BUS.D1: U9.34 (GPIO22); also elsewhere on the board
/Connector/BUS.D2: U9.35 (GPIO23); also elsewhere on the board
/Connector/BUS.D3: U9.36 (GPIO24); also elsewhere on the board
/Connector/BUS.D4: U9.37 (GPIO25); also elsewhere on the board
/Connector/BUS.D5: U9.38 (GPIO26_ADC0); also elsewhere on the board
/Connector/BUS.D6: U9.39 (GPIO27_ADC1); also elsewhere on the board
/Connector/BUS.D7: U9.40 (GPIO28_ADC2); also elsewhere on the board
/Connector/BUS.D8: U9.41 (GPIO29_ADC3); also elsewhere on the board
/Connector/BUS.RE#: U9.26 (RUN); also elsewhere on the board
/FPGA Configuration/CFG.CFG0: U9.9 (GPIO7); also elsewhere on the board
/FPGA Configuration/CFG.CFG1: U9.6 (GPIO4); also elsewhere on the board
/FPGA Configuration/CFG.CFG2: U9.2 (GPIO0); also elsewhere on the board
/FPGA Configuration/CFG.DONE: U9.5 (GPIO3); also elsewhere on the board
/FPGA Configuration/CFG.INIT#: U9.3 (GPIO1); also elsewhere on the board
/FPGA Configuration/CFG.PROGRAM#: U9.4 (GPIO2); also elsewhere on the board
/FPGA Configuration/JTAG.TCK: U9.12 (GPIO9); also elsewhere on the board
/FPGA Configuration/JTAG.TDI: U9.8 (GPIO6); also elsewhere on the board
/FPGA Configuration/JTAG.TDO: U9.11 (GPIO8); also elsewhere on the board
/FPGA Configuration/JTAG.TMS: U9.13 (GPIO10); also elsewhere on the board
/JTAG/FLASH.SCLK: U8.6 (CLK), U9.52 (QSPI_SCLK)
/JTAG/FLASH.SD0: U8.5 (DI(IO0)), U9.53 (QSPI_SD0)
/JTAG/FLASH.SD1: U8.2 (DO(IO1)), U9.55 (QSPI_SD1)
/JTAG/FLASH.SD2: U8.3 (IO2), U9.54 (QSPI_SD2)
/JTAG/FLASH.SD3: U8.7 (IO3), U9.51 (QSPI_SD3)
/JTAG/FLASH.SS: R21.1, U8.1 (~CS), U9.56 (QSPI_SS)
/JTAG/OSC_IN: C25.1, U9.20 (XIN), Y1.1 (IN/OUT)
/JTAG/OSC_OUT: R24.2, U9.21 (XOUT)
/JTAG/SWCLK: J2.3, U9.24 (SWCLK)
/JTAG/SWD: J2.1, U9.25 (SWD)
/JTAG/UART.RX: U9.16 (GPIO13); also elsewhere on the board
/JTAG/UART.TX: U9.15 (GPIO12); also elsewhere on the board
/JTAG/USB.D+: R23.2, U7.4 (I/O2)
/JTAG/USB.D-: R22.2, U7.6 (I/O1)
GND: C24.1, C25.2, C26.2, C27.2, C28.2, C29.2, C30.2, C31.2, C32.2, C33.2, C34.2, C35.2, C36.2, C37.2, C38.2, C52.2, C62.2, J1.A1 (GND), J1.A12 (GND), J1.B1 (GND), J1.B12 (GND), J1.S1 (SHIELD), J2.2, R19.1, R20.1, R25.2, U7.2 (GND), U8.4 (GND), U9.19 (TESTEN), U9.57 (GND), Y1.2 (GND), Y1.4 (GND); also elsewhere on the board
unnamed: D2.2 (A), U9.27 (GPIO16)
unnamed: D2.1 (K), R25.1
unnamed: J1.A5 (CC1), R19.2
unnamed: J1.B5 (CC2), R20.2
unnamed: J1.A6 (D+), J1.B6 (D+), U7.3 (I/O2)
unnamed: J1.A7 (D-), J1.B7 (D-), U7.1 (I/O1)
unnamed: C24.2, F1.1, J1.A4 (VBUS), J1.A9 (VBUS), J1.B4 (VBUS), J1.B9 (VBUS), U7.5 (VBUS)
unnamed: R22.1, U9.46 (USB_DM)
unnamed: R23.1, U9.47 (USB_DP)
unnamed: C27.1, C29.1, C30.1, C62.1, U9.23 (DVDD), U9.45 (VREG_VOUT), U9.50 (DVDD)
unnamed: C28.1, R24.1, Y1.3 (OUT/IN)

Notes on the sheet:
C40 near pin 44


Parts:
C39: 10u; C_0402_1005Metric_Pad0.74x0.62mm_HandSolder
C40: 100n; C_0402_1005Metric_Pad0.74x0.62mm_HandSolder
J3: Micro_SD_Card_Det1; microSD_HC_Wuerth_693072010801
R26, R27: 10k; R_0402_1005Metric_Pad0.72x0.64mm_HandSolder
U1: LFE5UM-85F-7BG381x; Lattice_caBGA-381_17.0x17.0mm_Layout20x20_P0.8mm_Ball0.4mm_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

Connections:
+3V3: C39.1, C40.1, J3.4 (VDD), R26.1, R27.1, U1.L14 (VCCIO3), U1.L15 (VCCIO3), U1.M15 (VCCIO3); also elsewhere on the board
/SD/SDIO.CLK: J3.5 (CLK), U1.R20 (PR86B)
/SD/SDIO.CMD: J3.3 (CMD), U1.T20 (PR86C)
/SD/SDIO.D0: J3.7 (DAT0), U1.P20 (PR86A)
/SD/SDIO.D1: J3.8 (DAT1), R27.2, U1.N20 (PR83B)
/SD/SDIO.D2: J3.1 (DAT2), R26.2, U1.U20 (PR86D)
/SD/SDIO.D3: J3.2 (DAT3/CD), U1.U19 (PR89C)
GND: C39.2, C40.2, J3.6 (VSS), J3.9 (SHIELD); also elsewhere on the board


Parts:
U1: LFE5UM-85F-7BG381x; Lattice_caBGA-381_17.0x17.0mm_Layout20x20_P0.8mm_Ball0.4mm_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


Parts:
J4: Connector A 16-bit; PinHeader_2x15_P1.27mm_Vertical_SMD
R28: <10k; R_0402_1005Metric_Pad0.72x0.64mm_HandSolder

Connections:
+3V3_BUS: J4.28, R28.1; also elsewhere on the board
+5V_BUS: J4.25; also elsewhere on the board
/Connector/BUS.CLK: J4.19; also elsewhere on the board
/Connector/BUS.CS#A0: J4.22; also elsewhere on the board
/Connector/BUS.CS#A1: J4.20; also elsewhere on the board
/Connector/BUS.D0: J4.18; also elsewhere on the board
/Connector/BUS.D1: J4.17; also elsewhere on the board
/Connector/BUS.D2: J4.16; also elsewhere on the board
/Connector/BUS.D3: J4.15; also elsewhere on the board
/Connector/BUS.D4: J4.14; also elsewhere on the board
/Connector/BUS.D5: J4.13; also elsewhere on the board
/Connector/BUS.D6: J4.12; also elsewhere on the board
/Connector/BUS.D7: J4.11; also elsewhere on the board
/Connector/BUS.D8: J4.10; also elsewhere on the board
/Connector/BUS.D9: J4.9; also elsewhere on the board
/Connector/BUS.D10: J4.8; also elsewhere on the board
/Connector/BUS.D11: J4.7; also elsewhere on the board
/Connector/BUS.D12: J4.6; also elsewhere on the board
/Connector/BUS.D13: J4.5; also elsewhere on the board
/Connector/BUS.D14: J4.4; also elsewhere on the board
/Connector/BUS.D15: J4.3; also elsewhere on the board
/Connector/BUS.DET: J4.24, R28.2
/Connector/BUS.INT: J4.23; also elsewhere on the board
/Connector/BUS.RE#: J4.26; also elsewhere on the board
GND: J4.1, J4.2, J4.27, J4.30; also elsewhere on the board

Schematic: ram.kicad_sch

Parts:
C5, C7: 100n; C_0402_1005Metric_Pad0.74x0.62mm_HandSolder
C6, C8: 4.7u; C_0402_1005Metric_Pad0.74x0.62mm_HandSolder
U1: LFE5UM-85F-7BG381x; Lattice_caBGA-381_17.0x17.0mm_Layout20x20_P0.8mm_Ball0.4mm_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
U3: W958D8NBYA; BGA24C100P5X5_600X800X120

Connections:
+1V8: C5.1, C6.1, C7.1, C8.1, U1.H6 (VCCIO7), U1.H7 (VCCIO7), U1.J6 (VCCIO7), U3.B4 (VCC), U3.D1 (VCCQ), U3.E4 (VCCQ); also elsewhere on the board
/RAM/HYPERRAM.CK+: U1.A4 (PL11A), U3.B2 (CK)
/RAM/HYPERRAM.CK-: U1.A5 (PL11B), U3.B1 (CK#)
/RAM/HYPERRAM.CS#: U1.A3 (PL14C), U3.A3 (CS#)
/RAM/HYPERRAM.DQ0: U1.D1 (PL38B), U3.D3 (DQ0)
/RAM/HYPERRAM.DQ1: U1.B2 (PL35C), U3.D2 (DQ1)
/RAM/HYPERRAM.DQ2: U1.B1 (PL35B), U3.C4 (DQ2)
/RAM/HYPERRAM.DQ3: U1.C2 (PL35D), U3.D4 (DQ3)
/RAM/HYPERRAM.DQ4: U1.C1 (PL38A), U3.D5 (DQ4)
/RAM/HYPERRAM.DQ5: U1.D2 (PL38C), U3.E3 (DQ5)
/RAM/HYPERRAM.DQ6: U1.E1 (PL38D), U3.E2 (DQ6)
/RAM/HYPERRAM.DQ7: U1.D3 (PL17D), U3.E1 (DQ7)
/RAM/HYPERRAM.RESET#: U1.A2 (PL35A), U3.A4 (RESET#)
/RAM/HYPERRAM.RWDS: U1.B3 (PL14D), U3.C3 (RWDS)
GND: C5.2, C6.2, C7.2, C8.2, U3.B3 (VSS), U3.C1 (VSSQ), U3.E5 (VSSQ); also elsewhere on the board



Board: 6 copper layers, 47.5 x 50.0 mm, 120 parts (49 on the bottom side), 103 nets.

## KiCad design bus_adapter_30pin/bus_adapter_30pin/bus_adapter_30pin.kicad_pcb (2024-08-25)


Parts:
J1: Conn_02x15_Odd_Even; PinHeader_2x15_P1.27mm_Vertical_SMD
J2, J3: Conn_01x15_Socket; PinHeader_1x15_P2.54mm_Vertical

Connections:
GND: J1.1, J1.4, J1.29, J1.30, J2.2, J2.15, J3.1, J3.15
unnamed: J1.2, J2.1
unnamed: J1.3, J3.2
unnamed: J1.5, J3.3
unnamed: J1.6, J2.3
unnamed: J1.7, J3.4
unnamed: J1.8, J2.4
unnamed: J1.9, J3.5
unnamed: J1.10, J2.5
unnamed: J1.11, J3.6
unnamed: J1.12, J2.6
unnamed: J1.13, J3.7
unnamed: J1.14, J2.7
unnamed: J1.15, J3.8
unnamed: J1.16, J2.8
unnamed: J1.17, J3.9
unnamed: J1.18, J2.9
unnamed: J1.19, J3.10
unnamed: J1.20, J2.10
unnamed: J1.21, J3.11
unnamed: J1.22, J2.11
unnamed: J1.23, J3.12
unnamed: J1.24, J2.12
unnamed: J1.25, J3.13
unnamed: J1.26, J2.13
unnamed: J1.27, J3.14
unnamed: J1.28, J2.14


Board: 2 copper layers, 47.5 x 50.0 mm, 3 parts (1 on the bottom side), 27 nets.

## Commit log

2022-02-11 decoupling capacitors placed
    [SDRAM.kicad_sch, clock.kicad_sch, connector.kicad_sch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]
2022-02-20 working on new version of fpga extension with Lattice FPGA
    [clock.kicad_sch, fpga.kicad_sch, fpga_config.kicad_sch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]
2022-02-21 qspi added
    [fpga.kicad_sch, fpga_config.kicad_sch, fpga_dvi.kicad_sch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]
2022-04-10 motherboard almost done, power section must be added
    [bipolar_amp.kicad_sch, bus_mux_demux.kicad_sch, connectors.kicad_sch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]
2022-04-15 Fixing labels
    [bus_mux_demux.kicad_sch, connectors.kicad_sch, flash.kicad_sch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]
2022-04-16 fixed warnings and errors
    [bus_mux_demux.kicad_sch, connectors.kicad_sch, mainboard.kicad_sch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]
2022-04-29 board almost ready, paths must be aligned
    [bus_mux_demux.kicad_sch, connectors.kicad_sch, flash.kicad_sch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]
2022-04-30 motherboard designed
    [bus_mux_demux.kicad_sch, connectors.kicad_sch, flash.kicad_sch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]
2022-07-04 some changes
    [RP2040.kicad_sch, audio.kicad_sch, connector.kicad_sch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]
2022-11-10 schematic for gpu extension
    [RP2040.kicad_sch, bus_mux_demux.kicad_sch, connector.kicad_sch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]
2022-11-10 some ERC fixes
    [RP2040.kicad_sch, bus_mux_demux.kicad_sch, connector.kicad_sch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]
2022-11-13 some fixes for ERC
    [bus_mux_demux.kicad_sch, connectors.kicad_sch, flash.kicad_sch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]
2022-11-16 gpu and motherboard passes tests, now time for fpga
    [bus_mux_demux.kicad_sch, connector.kicad_sch, connectors.kicad_sch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]
2022-11-29 refactored mainboard schematic
    [RP2040.kicad_sch, audio_dac.kicad_sch, bus_mux_demux.kicad_sch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]
2022-12-06 working on new pcb
    [audio_dac.kicad_sch, bus_south_connectors.kicad_sch, main_bus_control.kicad_sch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]
2022-12-09 working on PCB
    [audio_dac.kicad_sch, bus_south_connectors.kicad_sch, freerouting.dsn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]
2022-12-11 Mainboard rev 1.0a prepared
    [audio_dac.kicad_sch, bus_south_connectors.kicad_sch, main_bus_control.kicad_sch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]
2022-12-11 fixes in gpu extension schematic
    [RP2040.kicad_sch, bus_connector.kicad_sch, connector.kicad_sch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]
2023-01-19 version 1.0
    [bottomStencil.scad, bottomStencil.stl, dvi.kicad_sch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]
2023-01-20 new gpu stencil
    [bottomStencil.scad, bottomStencil.stl, topStencil.scad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]
2023-01-20 new mainboard stencil
    [bottomStencil.scad, bottomStencil.stl, topStencil.scad]
2024-08-25 prepared first versions of PCBs
    [SDRAM.kicad_sch, audio_dac.kicad_sch, bus_adapter_10pin.kicad_pcb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]
2024-08-25 added outputs and gerbers
    [bus_adapter_10pin-B_Cu.gbl, bus_adapter_10pin-B_Mask.gbs, bus_adapter_10pin-B_Paste.gbp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]
2024-11-28 fixed trace to flash memory
    [fpga_config.kicad_sch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]
2024-12-19 vga and dvi cards separated
    [RP2040.kicad_sch, audio.kicad_sch, bottomStencil.scad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]
2026-09-11 Replace .gitignore and stop tracking KiCad per-machine files
    The old .gitignore listed per-directory paths, and every one of them had
    gone stale: gpu_extension/ was split into gpu_vga_extension/ and
    gpu_dvi_card/, so their backup folders started being committed. Use
    generic KiCad patterns instead and untrack what they cover: project
    backup zips, fp-info-cache, *.kicad_prl, *-bak / *.bak backups, KiCad 5
    cache libraries, Freerouting exports, generated simulation netlists and
    Python bytecode (188 files). The files stay on disk; fabrication
    outputs remain tracked on purpose.
    [freerouting.dsn, temp-freerouting.dsn]
2026-09-11 Remove stale duplicates and unused library leftovers
    - gpu_*/gerber/: pre-split plots, identical in both cards; the current
    sets live in outputs/gerber/.
    - gpu_dvi_card/outputs/gerber/gpu_extension_vga.zip: the VGA card's
    fab zip, which does not belong to the DVI card.
    - mainboard/mainboard/schematic.pdf: older copy of outputs/schematic.pdf.
    - v1-era mainboard.csv/.xml and 2022 gpu_extension.csv/.xml: BOMs and
    netlists of boards that no longer exist.
    - Empty, unreferenced sheets (5 on the mainboard, 2 on each GPU card),
    empty or never-loaded symbol/footprint files, and the copies of the
    RP2350 80-QFN reference project dropped into libs/ (their nested lib
    tables, project files and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
    [audio.kicad_sch, bus_mux_demux.kicad_sch, bus_south_connectors.kicad_sch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]
2026-09-11 Add README
    Describe the branches, what each board directory contains, how the
    KiCad files and fabrication outputs are handled, and the known issues
    left for later (project names, stale outputs, duplicated libraries).
2026-09-11 Rename KiCad files and sheets to match what they contain
    - mainboard: rp2040_core.kicad_sch -> rp2350_core.kicad_sch and the
    sheet "RP2040 Core" -> "RP2350 Core"; the sheet holds the RP2350.
    Hierarchical net names, footprint sheet properties and the net-class
    patterns in the .kicad_pro follow the new sheet name.
    - gpu_vga_extension, gpu_dvi_card: both projects were still called
    gpu_extension; name each after its directory, including the
    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
    [RP2040.kicad_sch, bus_adapter_20pin.kicad_pcb, bus_adapter_20pin.kicad_sch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]
2026-09-11 Stop tracking gerbers; keep the schematic PDFs
    Gerbers, drill files and their zip bundles are plotted from the KiCad
    projects when a board is ordered, so they no longer live in the
    repository (82 files in the six outputs/gerber*/ directories). They stay
    on disk and are ignored from now on. The schematic PDFs remain tracked
    so the schematics can be read without KiCad.
    [bus_adapter_10pin-B_Cu.gbl, bus_adapter_10pin-B_Mask.gbs, bus_adapter_10pin-B_Paste.gbp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]
